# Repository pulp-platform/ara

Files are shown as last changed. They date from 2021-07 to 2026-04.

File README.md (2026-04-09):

# Ara



Ara is a vector unit working as a coprocessor for the CVA6 core.
It supports the RISC-V Vector Extension, [version 1.0](https://github.com/riscv/riscv-v-spec/releases/tag/v1.0), and the [Zvkned](https://github.com/riscv/riscv-crypto/releases/tag/v1.0.0) vector crypto extension for AES encryption/decryption.

Prototypical documentation can be found at https://pulp-platform.github.io/ara

## Dependencies

Check `DEPENDENCIES.md` for a list of hardware and software dependencies of Ara.

## Supported instructions

Check `FUNCTIONALITIES.md` to check which instructions are currently supported by Ara.

## Get started

Make sure you clone this repository recursively to get all the necessary submodules:

```bash
make git-submodules
```

If the repository path of any submodule changes, run the following command to change your submodule's pointer to the remote repository:

```bash
git submodule sync --recursive
```

## Toolchain

Ara requires a RISC-V LLVM toolchain capable of understanding the vector extension, version 1.0.

To build this toolchain, run the following command in the project's root directory.

```bash
# Build the LLVM toolchain
make toolchain-llvm
```

Ara also requires an updated Spike ISA simulator, with support for the vector extension.
There are linking issues with the standard libraries when using newer CC/CXX versions to compile Spike. Therefore, here we resort to older versions of the compilers. If there are problems with dynamic linking, use:
`make riscv-isa-sim LDFLAGS="-static-libstdc++"`. Spike was compiled successfully using gcc and g++ version 7.2.0.

To build Spike, run the following command in the project's root directory.

```bash
# Build Spike
make riscv-isa-sim
```

## Verilator

Ara requires an updated version of Verilator, for RTL simulations.

To build it, run the following command in the project's root directory.

```bash
# Build Verilator
make verilator
```

Alternatively, you can use a system-installed Verilator by passing `system_verilator=1` to the hardware make targets:

```bash
make -C hardware verilate system_verilator=1
```

### macOS

On macOS, install `libelf` via Homebrew (it is not shipped with macOS):

```bash
brew install libelf
```

The build system will automatically detect macOS and add the necessary Homebrew include/library paths.

## Configuration

Ara's parameters are centralized in the `config` folder, which provides several configurations to the vector machine.
Please check `config/README.md` for more details.

Prepend `config=chosen_ara_configuration` to your Makefile commands, or export the `ARA_CONFIGURATION` variable to choose a configuration other than the `default` one.

## Software

### Build Applications

The `apps` folder contains example applications that work on Ara. Run the following command to build an application. E.g., `hello_world`:

```bash
cd apps
make bin/hello_world
```

### SPIKE Simulation

All the applications can be simulated with SPIKE. Run the following command to build and run an application. E.g., `hello_world`:

```bash
cd apps
make bin/hello_world.spike
make spike-run-hello_world
```

### RISC-V Tests

The `apps` folder also contains the RISC-V tests repository, including a few unit tests for the vector instructions. Run the following command to build the unit tests:

```bash
cd apps
make riscv_tests
```

## RTL Simulation

### Hardware dependencies

The Ara repository depends on external IPs and uses Bender to handle the IP dependencies.
To install Bender and initialize all the hardware IPs, run the following commands:

```bash
# Go to the hardware folder
cd hardware
# Install Bender and checkout all the IPs
make checkout
```

If you have Bender installed system-wide, pass `system_bender=1` to use it instead of the local binary.

### Patches (only once!)

Note: this step is required only once, and needs to be repeated ONLY if the IP hardware dependencies are deleted and checked out again.

Some of the IPs need to be patched to work with Verilator.

```bash
# Go to the hardware folder
cd hardware
# Apply the patches (only need to run this once)
make apply-patches
```

### Simulation

To simulate the Ara system with ModelSim, go to the `hardware` folder, which contains all the SystemVerilog files. Use the following command to run your simulation:

```bash
# Go to the hardware folder
cd hardware
# Only compile the hardware without running the simulation.
make compile
# Run the simulation with the *hello_world* binary loaded
app=hello_world make sim
# Run the simulation with the *some_binary* binary. This allows specifying the full path to the binary
preload=/some_path/some_binary make sim
# Run the simulation without starting the gui
app=hello_world make simc
```

We also provide the `simv` makefile target to run simulations with the Verilator model.

```bash
# Go to the hardware folder
cd hardware
# Apply the patches (only need to run this once)
make apply-patches
# Only compile the hardware without running the simulation.
make verilate
# Run the simulation with the *hello_world* binary loaded
app=hello_world make simv
```

It is also possible to simulate the unit tests compiled in the `apps` folder. Given the number of unit tests, we use Verilator. Use the following command to install Verilator, verilate the design, and run the simulation:

```bash
# Go to the hardware folder
cd hardware
# Apply the patches (only need to run this once)
make apply-patches
# Verilate the design
make verilate
# Run the tests
make riscv_tests_simv
```

Alternatively, you can also use the `riscv_tests` target at Ara's top-level Makefile to both compile the RISC-V tests and run their simulation.

### Traces

Add `trace=1` to the `verilate`, `simv`, and `riscv_tests_simv` commands to generate waveform traces in the `fst` format.
You can use `gtkwave` to open such waveforms.

### Ideal Dispatcher mode

CVA6 can be replaced by an ideal FIFO that dispatches the vector instructions to Ara with the maximum issue-rate possible.
In this mode, only Ara and its memory system affect performance.
This mode has some limitations:
 - The dispatcher is a simple FIFO. Ara and the dispatcher cannot have complex interactions.
 - Therefore, the vector program should be fire-and-forget. There cannot be runtime dependencies from the vector to the scalar code.
 - Not all the vector instructions are supported, e.g., the ones that use the `rs2` register.

To compile a program and generate its vector trace:

```bash
cd apps
make bin/${program}.ideal
```

This command will generate the `ideal` binary to be loaded in the L2 memory for the simulation (data accessed by the vector code).
To run the system in Ideal Dispatcher mode:

```bash
cd hardware
make sim app=${program} ideal_dispatcher=1
```

### VCD Dumping

It's possible to dump VCD files for accurate activity-based power analyses. To do so, use the `vcd_dump=1` option to compile the program and to run the simulation:

```bash
make -C apps bin/${program} vcd_dump=1
make -C hardware simc app=${program} vcd_dump=1
```

Currently, the following kernels support automatic VCD dumping: `fmatmul`, `fconv3d`, `fft`, `dwt`, `exp`, `cos`, `log`, `dropout`, `jacobi2d`.

### Linting Flow

We also provide Synopsys Spyglass linting scripts in the hardware/spyglass. Run make lint in the hardware folder, with a specific MemPool configuration, to run the tests associated with the lint_rtl target.

### Support for `rvv-bench`

To run `rvv-bench` instructions benchmark, execute:

```bash
make rvv-bench
make -C apps bin/rvv
make -C hardware simv app=rvv
```

## FPGA implementation and Linux flow

Ara supports Cheshire's FPGA flow and can be currently implemented on VCU128 and VCU118 in bare-metal and with Linux. The tested configuration is with 2 lanes.

For information about the FPGA bare-metal and Linux flows, please refer to `cheshire/README.md`.

## Publications

If you want to use Ara, you can cite us:
```
@Article{Ara2020,
  author = {Matheus Cavalcante and Fabian Schuiki and Florian Zaruba and Michael Schaffner and Luca Benini},
  journal= {IEEE Transactions on Very Large Scale Integration (VLSI) Systems},
  title  = {Ara: A 1-GHz+ Scalable and Energy-Efficient RISC-V Vector Processor With Multiprecision Floating-Point Support in 22-nm FD-SOI},
  year   = {2020},
  volume = {28},
  number = {2},
  pages  = {530-543},
  doi    = {10.1109/TVLSI.2019.2950087}
}
```
```
@INPROCEEDINGS{9912071,
  author={Perotti, Matteo and Cavalcante, Matheus and Wistoff, Nils and Andri, Renzo and Cavigelli, Lukas and Benini, Luca},
  booktitle={2022 IEEE 33rd International Conference on Application-specific Systems, Architectures and Processors (ASAP)},
  title={A “New Ara” for Vector Computing: An Open Source Highly Efficient RISC-V V 1.0 Vector Processor Design},
  year={2022},
  volume={},
  number={},
  pages={43-51},
  doi={10.1109/ASAP54787.2022.00017}}
```
```
@ARTICLE{10500752,
  author={Perotti, Matteo and Cavalcante, Matheus and Andri, Renzo and Cavigelli, Lukas and Benini, Luca},
  journal={IEEE Transactions on Computers},
  title={Ara2: Exploring Single- and Multi-Core Vector Processing With an Efficient RVV 1.0 Compliant Open-Source Processor},
  year={2024},
  volume={73},
  number={7},
  pages={1822-1836},
  keywords={Vectors;Registers;Computer architecture;Vector processors;Multicore processing;Microarchitecture;Kernel;RISC-V;vector;ISA;RVV;processor;efficiency;multi-core},
  doi={10.1109/TC.2024.3388896}}
```

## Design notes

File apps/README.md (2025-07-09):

# Apps

This folder contains the benchmarks, programs, and tests ready to be run on Ara.

Run the following command to build an application. E.g., `hello_world`:

```bash
cd apps
make bin/hello_world
```

### Convolutions

Convolutions allow to specify the output matrix size and the size of the filter, with the variables `OUT_MTX_SIZE` up to 112 and `F_SIZE` within {3, 5, 7}. Currently, not all the configurations are supported for all the convolutions. For more information, check the `main.c` file for the convolution of interest.
Example:

```bash
cd apps
make bin/fconv2d OUT_MTX_SIZE=112 F_SIZE=7
```

### Linux programs

Compile $app for bare-metal:

```bash
make ${app}
```

Compile $app for OS:

```bash
make ${app}-linux LINUX=1
```

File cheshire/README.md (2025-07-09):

## Introduction

Ara can be synthesized on a VCU128 FPGA and boot Linux through the Cheshire SoC. This folder provides the necessary targets and flow to build RVV-Linux and deploy Ara on FPGA. To make them work, this repository should be deployed as a submodule of Cheshire.

Our entry point is to generate a custom `add_sources.vcu128.tcl` file with specific Ara targets, copy this file into the Cheshire directory, and then use the default Cheshire compile flow, which will use our provided TCL file

## How to Use

Ara should be instantiated as a submodule of Cheshire. This means that the Ara repo should be downloaded through `bender checkout` from the Cheshire directory. Then, Ara's path can be retrived using `bender path ara`.

```bash
git clone git@github.com:pulp-platform/cheshire.git
cd cheshire
git checkout ${COMMIT}
bender checkout
ARA_ROOT=$(bender path ara)
cd ${ARA_ROOT}
```

## FPGA and OS flow

### LINUX-RVV Kernels
Compile kernels to be run on the FPGA under Linux (this will also install the buildroot toolchain)

```bash
cd ${ARA_ROOT}/cheshire/sw

# Choose a kernel from the apps directory
kernel=fmatmul
make ${kernel}-linux
```

### Generate the Linux IMG
Generate the Linux image (containing all the RVV kernels previously built)

```bash
# Generate the Linux img
cd ${ARA_ROOT}/cheshire/sw
make linux-img

# Generate Cheshire's Linux img
cd ${ARA_ROOT}/cheshire
make ara-chs-image
```

### Generate the FPGA bitstream

```bash
cd ${ARA_ROOT}/cheshire
make ara-chs-xilinx
```

### Flash the Linux image on the SD card

```bash
cd ${ARA_ROOT}/cheshire
make ara-chs-xilinx-flash
```

### Program the bitstream

```bash
cd ${ARA_ROOT}/cheshire
make ara-chs-xilinx-program
```

For more information, see Cheshire's documentation (https://pulp-platform.github.io/cheshire/tg/xilinx).

### Example

Example script to boot Linux on a VCU128 FPGA board. Modify the variables as needed.

There should be an open Hardware Target for the VCU128 board. Moreover, a UART terminal is required.

Note: this script requires `bender`. Also, some Cheshire targets may require an up-to-date RISC-V compiler.

```bash
export CHS_ROOT=$(pwd)/cheshire

# Cheshire commit
# FILL ME
export CHS_HASH=

# Do we need a specific GCC/G++ version to build the buildroot GCC compiler?
HOST_TOOLCHAIN_SUFFIX=

# Which RVV kernels to run under Linux
export RVV_KERNELS="hello_world-linux fmatmul-linux fconv3d-linux jacobi2d-linux fdotproduct-linux"

# FPGA details
# FILL ME
export BOARD="vcu128"
export CHS_XILINX_HWS_URL=
export CHS_XILINX_HWS_PATH=

# Info
echo "Using the VCU128 ${CHS_XILINX_HWS_URL} ${CHS_XILINX_HWS_PATH}"
# Clone Cheshire
echo "Cloning Cheshire"
git clone git@github.com:pulp-platform/cheshire.git
cd ${CHS_ROOT}
git checkout ${CHS_HASH}
# Checkout Ara
echo 'Checkout hardware deps'
bender checkout
export ARA_ROOT=$(bender -d ${CHS_ROOT} path ara)
# Apply patches if needed
# The following is non-mandatory:
# Upsize Cheshire's memory and disable VGA
make -C ${ARA_ROOT}/cheshire patch_cheshire_high_perf_hw
# The following is non-mandatory
# Setup L2 as a cache and not as a scratchpad when running Linux
make -C ${ARA_ROOT}/cheshire/sw patch_cheshire_high_perf_sw
# Compile RVV kernels
echo 'Install the Linux compiler and compile the LINUX RVV kernels'
make -C ${ARA_ROOT}/cheshire/sw ${RVV_KERNELS} HOST_TOOLCHAIN_SUFFIX=${HOST_TOOLCHAIN_SUFFIX}
# Compile the Linux image
echo 'Compile the Linux image'
make -C ${ARA_ROOT}/cheshire/sw linux-img HOST_TOOLCHAIN_SUFFIX=${HOST_TOOLCHAIN_SUFFIX}
# Generate Cheshire's Linux image
echo 'Generate Cheshire Linux image'
make -C ${ARA_ROOT}/cheshire ara-chs-image BOARD=${BOARD}
# Generate the bitstream
echo 'Generate the bitstream'
make -C ${ARA_ROOT}/cheshire ara-chs-xilinx BOARD=${BOARD}
# Flash the SD with Linux
echo 'Flash the SD with Linux'
make -C ${ARA_ROOT}/cheshire ara-chs-xilinx-flash BOARD=${BOARD} CHS_XILINX_HWS_URL=${CHS_XILINX_HWS_URL} CHS_XILINX_HWS_PATH=${CHS_XILINX_HWS_PATH}
# Program the bitstream
echo 'Program the bitstream'
make -C ${ARA_ROOT}/cheshire ara-chs-xilinx-flash BOARD=${BOARD} CHS_XILINX_HWS_URL=${CHS_XILINX_HWS_URL} CHS_XILINX_HWS_PATH=${CHS_XILINX_HWS_PATH}
```

## Bare-metal flow

### Compile the bare-metal programs in `${ARA_ROOT}/cheshire/sw/src`

```bash
cd ${ARA_ROOT}/cheshire/sw
make chs-sw-all
```

### Patch Cheshire (optional)

Optionally, Cheshire can be patched to have a larger main memory, VGA disabled, and LLC configured as cache under Linux.
This provides better performance.

```bash
cd ${ARA_ROOT}/cheshire
make patch_cheshire_high_perf_hw
cd ${ARA_ROOT}/cheshire/sw
make patch_cheshire_high_perf_sw
```

### Generate the FPGA bitstream

```bash
cd ${ARA_ROOT}/cheshire
make ara-chs-xilinx
```

### Program the bitstream

Provided that an Hardware Target is available:

```bash
cd ${ARA_ROOT}/cheshire
make ara-chs-xilinx-program
```

### Run programs on the FPGA
The programs can now be injected in the FPGA via JTAG (OpenOCD + GDB).
For more information, see Cheshire's documentation (https://pulp-platform.github.io/cheshire/tg/xilinx).

## Back-Referencing Explained

Here's how we use back-referencing in our setup:

1.  **Generate Custom TCL File**:

    -   We generate a custom `add_sources.vcu128.tcl` file using the `bender script vivado` command with our specific targets (`-t fpga -t vcu128 -t cv64a6_imafdcv_sv39 -t cva6 --define ARA --define NR_LANES=$(nr_lanes) --define VLEN=$(vlen)`).
    -   This custom TCL file includes all the necessary sources and configurations required for the FPGA synthesis with Cheshire + Ara.

2.  **Copy Custom TCL File**:

    -   The generated custom TCL file is then copied into the Cheshire directory (`$(BACKREF_CHS_XIL_SCRIPTS)/add_sources.vcu128.tcl`).

3.  **Invoke Cheshire Compile Flow**:

    -   With the custom TCL file in place, we invoke the Cheshire compile flow by running `make -C $(BACKREF_CHS_ROOT) chs-xilinx-all`.
    -   The Cheshire compile flow target depends on the `add_sources.vcu128.tcl` file, and since we have provided our custom version, it will use ours for the synthesis process.

This method ensures that we can extend and customize the compile flow for our specific needs without modifying the Cheshire repository directly.

## Notes

### Variables
 - ARA_CONFIGURATION: thus far, only Ara with 2 lanes has been tested (ARA_CONFIGURATION=2_lanes).
 - HOST_TOOLCHAIN_SUFFIX: the host GCC and G++ should be sufficiently up to date to build the buildroot cross compiler. For environments that track the program version with suffixes, this variable helps choose the correct host compiler version. Use this variable only if needed when installing the buildroot toolchain.
 - BOARD: name of the board, e.g., `vcu128`.
 - CHS_XILINX_HWS_URL: URL of the FPGA, if connected to the net.
 - CHS_XILINX_HWS_PATH: physical PATH of the FPGA.

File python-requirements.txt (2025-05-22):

# Copyright 2021 ETH Zurich and University of Bologna.
# Solderpad Hardware License, Version 0.51, see LICENSE for details.
# SPDX-License-Identifier: SHL-0.51

dataclasses
gitpython
hjson
jsonref
jsonschema
tabulate
yamlfmt
numpy
matplotlib
scikit-learn

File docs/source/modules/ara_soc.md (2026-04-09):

# `ara_soc`: Top-Level Dummy SoC for Ara

## Overview

The `ara_soc` module is a top-level **dummy system-on-chip** used to instantiate the **Ara vector processor** alongside the scalar **CVA6 core**, enabling test and benchmarking in a standalone simulation environment.

This SoC includes:
- Ara + CVA6 integration
- L2 memory (a simple SRAM, called DRAM in the file for historical reasons)
- Dummy UART peripheral
- Control and status registers
- AXI crossbar interconnect and protocol adapters

It is **parameterizable** to support varying numbers of vector lanes and data widths, enabling scalable evaluation of Ara across configurations.

---

## Parameters

| Name | Description |
|---|---|
| `NrLanes` | Number of parallel vector lanes (2–16, power-of-two) |
| `VLEN` | Vector length in bits (usually `1024 × NrLanes`) |
| `OSSupport` | Enable OS-level support in CVA6 |
| `FPUSupport` | Enables FP16, FP32, FP64 support |
| `FPExtSupport` | Enable optional `vfrec7` / `vfrsqrt7` instructions |
| `FixPtSupport` | Enables fixed-point support |
| `SegSupport` | Enables segmented memory instructions |
| `CryptoSupport` | Enables vector crypto extensions (e.g., `CryptoSupportAES` for Zvkned) |
| `Axi*Width` | AXI bus widths for data, address, ID, user |
| `AxiRespDelay` | AXI response delay in picoseconds (used in gate-level simulations) |
| `L2NumWords` | Number of words in simulated SRAM (`4MiB / lane` default) |

---

## Memory Map

| Region | Base Address | Size |
|---|---|---|
| `SRAM` | `0x8000_0000` | 1 GB |
| `UART` | `0xC000_0000` | 4 KB |
| `CTRL` | `0xD000_0000` | 4 KB |

---

## Internal Structure

### AXI Crossbar
- One master (CVA6+Ara system)
- Three slaves: SRAM, UART, control registers
- Managed via `axi_xbar` with routing rules

### SRAM (L2 Memory)
- Backed by non-synthesizable SRAM (`tc_sram`)
- Connected via `axi_to_mem` and `axi_atop_filter` (atomics filtered out)

### Dummy UART
- APB interface exposed to the environment
- Internally connected via AXI-Lite and AXI width converter
- Used to implement printf's putc in during simulation

### Control Registers
- Control and status block (exit signal, counters, etc.)
- Connected via AXI-Lite

### CVA6 + Ara Integration
- Instantiated via `ara_system`
- Custom configuration generated dynamically from RVV template config

---

## Interfaces

### Inputs
- `clk_i`, `rst_ni`: Clock and active-low reset
- `scan_enable_i`, `scan_data_i`: Scan chain inputs (for DFT)
- `uart_prdata_i`, `uart_pready_i`, `uart_pslverr_i`: UART bus inputs

### Outputs
- `exit_o`: Simulation termination flag, sensed by the testbench to end the simulation.
- `hw_cnt_en_o`: Hardware counter enable signal. Used for benchmarking.
- `scan_data_o`: Scan chain output.
- `uart_*`: APB UART outputs.

---

## Configuration Notes

CVA6 is configured dynamically using:

```systemverilog
function automatic config_pkg::cva6_user_cfg_t gen_usr_cva6_config(...);
```

## Memory

CVA6 + Ara access the memory through AXI using a `32 * #Lanes`-bit wide data port. This wide data port avoids complex interconnects and banked memory management, but performs poorly with indexed memory operations.

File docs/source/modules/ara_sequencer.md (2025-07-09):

# `ara_sequencer` — Instruction sequencer and macro dependency check

Overview
--------
The `ara_sequencer` is a central control module in Ara's vector processor that manages instruction dispatching and execution synchronization across its parallel processing elements (PEs). It ensures correct ordering and dependency resolution for vector instructions, tracks the state of each instruction in-flight, and handles hazards and stalling due to resource constraints.

Key Features
------------
- Tracks running vector instructions and their mapping to PEs
- Maintains a global hazard table for dependency management
- Calculates start and end lanes for operand access
- Arbitrates instruction issuance based on operand readiness and structural hazards
- Interfaces with CVA6 via a tokenized valid/ready protocol
- Handles load/store sequencing and exception propagation
- Supports masked vector operations and precise scalar forwarding

Interface Description
---------------------
### Inputs
- `clk_i`, `rst_ni`: Standard clock/reset
- `ara_req_i`, `ara_req_valid_i`: Instruction request from dispatcher
- `pe_req_ready_i`, `pe_resp_i`: PE readiness and response signals
- `alu_vinsn_done_i`, `mfpu_vinsn_done_i`: Completion signals from specific FU types
- `addrgen_ack_i`, `addrgen_exception_i`, `addrgen_exception_vstart_i`, `addrgen_fof_exception_i`: Address generator and exception interfaces
- `pe_scalar_resp_i`, `pe_scalar_resp_valid_i`: Scalar value return for scalar-result instructions

### Outputs
- `ara_req_ready_o`, `ara_resp_o`, `ara_resp_valid_o`: Request response handshake
- `pe_req_o`, `pe_req_valid_o`: Instruction issued to PEs
- `global_hazard_table_o`: Dependency matrix broadcast to operand requesters
- `ara_idle_o`: High when no instruction is in-flight
- `pe_scalar_resp_ready_o`: Ready signal for scalar result

Main Components
---------------
### Instruction State Tracking
- `pe_vinsn_running_q`: Bitmap showing which PE is executing which instruction
- `vinsn_running_q`: Aggregated bitmap indicating if any instruction is live. This signal is extremely useful for debug
- `vinsn_id_n`: Allocated ID for the next instruction using LZC

### Hazard Management
- RAW, WAR, WAW hazards computed against `read_list_q` and `write_list_q`
- `global_hazard_table_o` updated with current hazard vectors
- Enforces correct serialization and prevents premature execution

### Start/End Lane Calculation
- Derives which lanes will produce the first and last valid elements
- Based on `vstart`, `vl`, and `vsew`
- Important for operand alignment and masking

### Issuance Arbitration
- FSM with `IDLE` and `WAIT` states
- Uses counters per VFU to throttle instruction dispatch
- "Gold ticket" system ensures stalled-but-accounted instructions are not blocked

### Functional Unit Interface
- Identifies target VFU for each instruction
- Uses `target_vfus()` function to map to ALU, MFPU, SLDU, MASKU, etc.
- Only issues when operand requesters and FU queues are ready

### Special Features
- Slide unit constraints handled to avoid chaining issues
- Handles scalar results with mask unit coordination
- Exception signaling for burst and address-related faults
- Provides synchronization to CVA6 (via token and response logic)

Instruction Flow
----------------
1. Dispatcher issues instruction to sequencer.
2. Sequencer:
   - Allocates ID
   - Checks for hazards
   - Builds request (`pe_req_d`)
   - Calculates start/end lanes
   - Evaluates VFU counters
3. If resources available:
   - Issues request
   - Updates global hazard table and instruction trackers
4. Enters `WAIT` if instruction needs scalar return or memory ack
5. Once response is received or exception detected, returns to `IDLE`.

FSM States
----------
- **IDLE**: Default state; waits for instruction or handles stalls from the lanes' operand requesters.
- **WAIT**: Holding state for memory/scalar responses.

Dependency tracking and chaining
----------
Dependencies are tracked per instruction, so that chaining can be implemented at vector-element level.

The sequencer only knows which instruction depends on which other instruction, and assign special "hazard" signals to each instruction before issuing it to the units.
Every instruction keeps hazard metadata per operand register, so that it is clear upon which instruction every operand register depends.

Chaining is implemented in each lane, during operand fetch.
Every dependency (RAW, WAR, WAW) on a specific register will throttle the source operand fetch from the VRF. This throttling is controlled by the write throughput of the instruction that generated the dependency.

RAW example:
```
vld v0, addr
vadd v1, v0, v0
```

When executing the `vadd` (`vld` is executing in parallel), a lane will fetch the next element from `v0` only if `vld` has written one element first. This control is a credit-based system with a depth of one element only. Therefore, if `vld` writes 5 elements, the `vadd` only registers one credit for a read.

WAR and WAW hazards are handled in the same way.

WAR example:
```
vmul v2, v1, v1
vadd v1, v0, v0
```

Also in this case, `vadd` will be able to fetch from `v0` only when `vmul` has written into `v2`. This works because if source operands are chained, destination operands are also correctly ordered.

As soon as one instruction that causes a dependency is completes execution, the scoreboard is cleared and the second instruction will be allowed to fetch operands without restrictions.

This works as long as:
 - The second instruction has source operands from the VRF. For example, WAR and WAW stall loads, which would not be able to chain with this mechanism.
 - The first instruction actually writes something into the VRF. Therefore, WAR on store instructions stalls the second instruction until the first one has not completed.

Instruction Issue
----------
The sequencer keeps an instruction counter per functional unit to track how many instructions are in-flight and stall instruction issue whenever the next target functional unit's instruction queue is already full.

A new instruction bumps up the respective counter, and a completed instruction bumps it down.

Since, for timing reasons, instructions flow into the sequencer and bump the respective counter without waiting to be issues, counters can also go beyond their maximum capacity for one cycle. This event is registered through a gold ticket assigned to the instruction, which basically implies that the instruction was already registered by the respective counter. As soon as the counter returns to its maximum capacity (this happens when an instruction is finishes execution in the respective unit), the gold ticket allows the stalled instruction to proceed.

Physical Considerations
-----------------------
- `vinsn_queue_ready`: Derived from counter depth per FU
- `stall_lanes_desynch`: Ensures lane-0 aligned counters for ALU/MFPU
- `global_hazard_table_d`: Matrix [NrVInsn][NrVInsn] with sparse update logic
- Careful pipeline management to support exception-aware issuing

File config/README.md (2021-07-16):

# Configuration file for Ara

This file is included by all *Makefiles* in the Ara project to have a common
source for all configurations. Please only edit this file to change some
parameters such as the number of lanes in the design. This will automatically
generate the correct software runtime and the correct hardware.

Ara currently has four configurations, which differ on the amount of lanes:
- `2_lanes.mk`
- `4_lanes.mk`
- `8_lanes.mk`
- `16_lanes.mk`
We also provide a `default.mk` configuration, which links to the `4_lanes` one.

When running Ara's Makefiles, prepend `config=configuration_without_mk` to choose
a configuration. Alternatively, export the `ARA_CONFIG` variable. Please note that
the configuration chosen via the `config=` command line has priority over the
configuration set globally through the `ARA_CONFIG` variable.

If no configuration is explicitly chosen, Ara will use the `default` one. Please run
`make clean` after changing configurations.

To avoid constantly having a dirty git environment when working with a
configuration that differs from the default one, you can ignore changes to the
configuration file with the following command:

```bash
git update-index --assume-unchanged config/default.mk
```

In case you want to change the default and commit your changes to `default.mk`,
you can use the following command to make git pick up tracking the file again:

```bash
git update-index --no-assume-unchanged config/default.mk
```

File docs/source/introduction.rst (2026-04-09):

Introduction
=============

This Section will Introduce you the Ara Vector Processor.

Introduction to Ara
-------------------

Ara is a **modular, open-source vector processing unit** designed to **augment RISC-V processors** with **high-performance, energy-efficient vector computation**. It is developed by the `PULP platform <https://pulp-platform.org/>`_ at ETH Zurich and the University of Bologna.

At its core, **Ara is a scalable vector accelerator** compliant with the `RISC-V Vector Extension 1.0 (RVV) <https://github.com/riscv/riscv-v-spec>`_. It is specifically designed to target **data-parallel workloads** in embedded and high-performance computing environments. Ara is built to plug into the `CVA6 RISC-V core <https://github.com/openhwgroup/cva6>`_, and is suitable for system-on-chip (SoC) designs that require vector processing capabilities for applications such as:

- Signal processing
- Linear algebra
- Machine learning kernels
- Computer vision
- Cryptographic acceleration (currently AES via the Zvkned extension)

Ara can be configured with a power-of-2 number of parallel vector lanes ranging from 2 to 16. Each lane contains a slice of the Vector Register File (VRF), a SIMD FPU, and a SIMD ALU/Multiplier.

Since Multiply-and-Accumulate instructions can be executed in one cycle by each FPU, the maximum performance of Ara is `2 * #Lanes` 64-bit packets/cycle, where each 64-bit packet can contain from one 64-bit element to eight 8-bit elements, processed in SIMD fashion.

Architectural Overview
----------------------

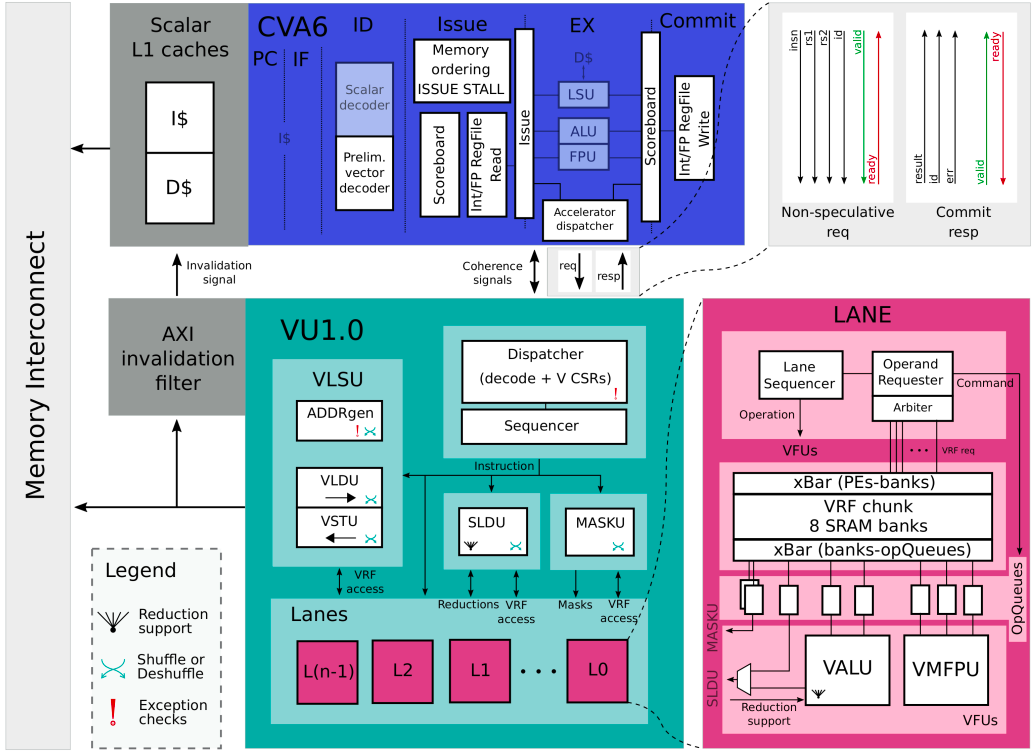
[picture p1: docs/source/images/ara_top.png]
Ara Top level Image


   Ara's top level diagram

Ara is composed of the following major components:

- **Vector Functional Units (VFUs)**: Includes ALUs, FPUs, multipliers, mask units, and slide units, each operating across multiple lanes in parallel.
- **Vector Lanes**: The architecture is scalable to multiple lanes. Each lane processes one slice of the data, providing parallelism at the element level.
- **Dispatcher & Sequencer**: These components decode and schedule vector instructions, ensuring synchronization and legal execution patterns.
- **Register File (VRF)**: Ara contains a large vector register file, partitioned across lanes for bandwidth scalability.
- **Memory Interface**: Vector loads and stores are issued via AXI-compatible memory accesses, either from DRAM or TCDM (depending on system integration).

Ara is **modular by construction**: users can configure the number of lanes, supported datatypes (int/fixed/fp), and optional features like floating-point extensions, reductions, or vector crypto.

Target Use Cases
----------------

Ara is ideal for:

- **Academic research** into vector architectures and compilers
- **Hardware/software co-design**
- **Custom accelerators** in SoC designs
- **FPGA-based prototyping** of RVV software

Ara for Non-Experts
-------------------

What Is Ara?
~~~~~~~~~~~~

Think of Ara as a **muscle boost for a processor**, specialized in handling **repetitive data-heavy tasks**—like multiplying a thousand numbers in parallel or transforming images efficiently.

Instead of performing one operation at a time, Ara handles **many operations at once** using **vectors** (think: long lists of numbers). This is similar to how modern GPUs work for games and machine learning—but in a way that is more **tailored to embedded systems** and open-source hardware.

Why Is Ara Useful?
~~~~~~~~~~~~~~~~~~

Most general-purpose CPUs process one or two pieces of data per cycle. Ara can process **dozens or hundreds of values in parallel**. This makes it **much faster and more energy-efficient** when dealing with structured, repetitive workloads like:

- Filtering an audio signal
- Applying a blur effect on an image
- Computing dot products in a neural network layer

Ara plugs into a RISC-V core like an add-on, offloading these "bulk" computations.

.. toctree::
   :maxdepth: 2
   :caption: Contents:

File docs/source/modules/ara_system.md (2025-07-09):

# `ara_system`: Integration of CVA6 and Ara

## Overview

`ara_system` instantiates and connects the scalar core **CVA6** with the **Ara vector accelerator**. It builds the system-level interface between the two, handles AXI width conversion, invalidation signaling, and merges AXI traffic into a unified master port.

This module is the core of Ara's architectural integration, enabling:
- Vector instruction dispatch from CVA6 to Ara
- Shared AXI access arbitration
- Coherent invalidation handling for vector memory stores
- Flexible benchmarking configurations through parameterization

CVA6 is a RV64GC RISC-V Linux-ready core. It features one L1 instruction cache and one L1 data cache connecting to the L2 memory.

CVA6 is the only "RISC-V core" properly speaking, meaning that it is the only one accessing the program's instruction flow.

Ara is a tighlty-coupled accelerator plugged into CVA6, and receives vector instructions from CVA6.

Both Ara and CVA6 have a private AXI4-compliant Load-Store unit. Ara's one directly connects to the L2 memory, bypassing CVA6's L1 data cache.

This allows for potential coherence and memory operation ordering issues.

---

## Memory Coherence and Consistency

Memory coherence is enforced through three main mechanisms:
 - Memory writes are serialized through a single memory bus.
 - CVA6 L1-D$ is write-through.
 - An invalidation filter snoops on Ara's AXI AW memory bus and invalidates the potentially-stale sets in CVA6's L1-D$.

Memory ordering is enforced by CVA6 and control signals between CVA6 and Ara. No memory operations are issued or started until it's safe to do so.
For example, pending vector stores prevent CVA6 from issuing scalar memory operations, and vector memory operations are not dispatched to Ara if there is a pending scalar store.

---

## Virtual memory support

Ara uses CVA6's MMU to translate virtual addresses into physical ones. This is done through the MMU interface.

---

## Parameters

### Ara + RVV Parameters

| Name | Description |
|---|---|
| `NrLanes` | Number of vector lanes |
| `VLEN` | Vector register length (in bits) |
| `OSSupport` | Enables OS features |
| `FPUSupport`  | Enabled FP precisions |
| `FPExtSupport`| Support for `vfrec7`, `vfrsqrt7` |
| `FixPtSupport`| Enable fixed-point ops |
| `SegSupport`  | Support for segmented memory ops |

### CVA6 and AXI Interface

| Name | Description |
|---|---|
| `CVA6Cfg` | CVA6 configuration record |
| `exception_t` | CVA6 exception type |
| `accelerator_req_t` | Accelerator interface (CVA6 → Ara) |
| `accelerator_resp_t`| Accelerator interface (Ara → CVA6) |
| `acc_mmu_{req,resp}`| MMU interface |
| `cva6_to_acc_t` | Packed request interface |
| `acc_to_cva6_t` | Packed response interface |
| `Axi*Width` | AXI bus widths |
| AXI typedefs | All channel and request/response types |

---

## Ports

| Port | Direction | Description |
|---|---|---|
| `clk_i` | Input | Clock signal |
| `rst_ni` | Input | Active-low reset |
| `boot_addr_i`| Input | Initial fetch address for CVA6 |
| `hart_id_i`  | Input | Hardware thread ID |
| `scan_*` | In/Out | Scan chain (test) |
| `axi_req_o`  | Output | AXI master request (merged) |
| `axi_resp_i` | Input | AXI master response (merged) |

---

## Internal Blocks

### 1. **CVA6 Core**
- Scalar processor core
- Interfaces to Ara via a dedicated accelerator port
- Outputs standard AXI (`ariane_axi_req_t`) at narrow data width to L2 memory

### 2. **Ara Accelerator**
- Fully parameterized vector unit
- Receives CVA6 requests, returns results and exceptions
- AXI master interface at wide data width (`32 * #Lanes` data width)

### 3. **AXI Width Converter**
- `axi_dw_converter` adjusts CVA6's narrow AXI (e.g., 64-bit) to match Ara/system-wide bus width

### 4. **AXI Invalidation Filter**
- Detects vector memory stores and emits invalidation signals
- Ensures cache coherence with CVA6
- Integrated with Ara's AXI path

### 5. **AXI Multiplexer**
- Merges CVA6 and Ara AXI requests
- Handles arbitration, backpressure, and spill registers

---

## Vector Interface Handling

- The `acc_to_cva6_t` signal is extended to include `inval_valid` and `inval_addr`, enabling memory coherence notification from Ara back to CVA6.
- Ara can assert `inval_valid` when performing stores that require CVA6 cache line invalidation.
- `acc_cons_en` gate controls the invalidation path.

---

## Alternative Configuration: `IDEAL_DISPATCHER`

The ideal dispatcher is just a tool to benchmark Ara's performance with an ideal vector instruction dispatcher instantiated INSTEAD OF CVA6.

If `IDEAL_DISPATCHER` is defined:
- CVA6 is replaced with a perfect dispatcher (`accel_dispatcher_ideal`), i.e., a FIFO containing the dynamic instruction trace of the program plus the correct register file values
- Useful for functional validation/benchmarking or micro-benchmarking Ara in isolation

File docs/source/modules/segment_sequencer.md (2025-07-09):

# `segment_sequencer` - Split segment memory operations into multiple micro-ops

This module breaks down segment memory operations into a sequence of scalar memory operations. While this results in poor instruction-per-cycle (IPC) performance, it simplifies hardware implementation and avoids the need for tightly coupled multi-element memory accesses.

## Key Parameters

- `SegSupport`: Enables or disables segment memory support (`1'b1` enables it).
- `ara_req_t`, `ara_resp_t`: Types representing Ara's request and response protocols.

## Interface Signals

### Clock & Reset
- `clk_i`: Clock signal.
- `rst_ni`: Active-low reset.

### Control Inputs
- `ara_idle_i`: Indicates Ara is idle.
- `is_segment_mem_op_i`: Indicates the instruction is a segment memory op.
- `illegal_insn_i`: Signals if the instruction is illegal.
- `is_vload_i`: Identifies if the operation is a vector load.

### Operation Tracking
- `seg_mem_op_end_o`: Signals the end of a segment memory op.
- `load_complete_i/o`, `store_complete_i/o`: Track completion of memory operations.

### Ara Frontend-Backend Interface
- `ara_req_i/o`, `ara_req_valid_i/o`, `ara_req_ready_i`
- `ara_resp_i/o`, `ara_resp_valid_i/o`

## Functionality

When `SegSupport` is enabled, this module implements a small FSM to micro-sequence a segment operation into a series of scalar instructions. These instructions are prepared by adjusting `vs1`, `vd`, and `scalar_op` fields, and issuing one sub-operation at a time.

### FSM States

- `IDLE`: Wait for segment memory op. Sample `nf` and `is_vload_i`.
- `SEGMENT_MICRO_OPS`: Sequentially issue micro-operations for each field of the segment.
- `SEGMENT_MICRO_OPS_WAIT_END`: Wait for Ara backend to become idle.
- `SEGMENT_MICRO_OPS_END`: Forward the final response and signal completion.

### Micro-operation Construction

- For each segment element:
  - `vl` is set to 1
  - `vstart` tracks the segment index
  - `vs1`, `vd`, and `scalar_op` are offset by the segment field index (`segment_cnt_q`)
- For unit-stride segments (`VLE`, `VSE`): `op` is changed to `VLSE`, `VSSE` and a `stride` is computed.

### Control Logic

- Two counters are used:
  - `segment_cnt_q` tracks the number of fields processed
  - `vstart_cnt_q` increments for each segment
- Response (`ara_resp_q`) is delayed until the full operation finishes and Ara is idle.

## Disabled Mode (SegSupport == 0)

In this case, the module becomes a passthrough between Ara's frontend and backend, with no internal FSM or micro-operation handling.

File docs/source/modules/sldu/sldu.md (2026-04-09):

# `sldu` — Ara's slide unit, for permutations, shuffles, and slides

## Overview

The Slide Unit (`sldu`) in Ara's vector processor is responsible for implementing vector slide instructions as specified in the RISC-V Vector Extension (RVV). These instructions shift elements within vector registers, either left or right, potentially with a configurable stride, and can support varying effective element widths (EEWs). The design is modular and consists of three components:

- `sldu`: The top-level Slide Unit module
- `sldu_op_dp`: The datapath handling element reshuffling and shifting
- `p2_stride_gen`: A utility module that generates power-of-two strides

This unit supports seamless data flow between the operand lanes and result queues, handling valid/ready handshakes and internal reshuffling, aligning with the RVV specification.

---

## 1. `sldu`: Top-Level Slide Unit

### Purpose

The `sldu` module serves as the interface and coordinator for the entire slide operation. It connects the operand input/output ports, manages the slide operation control logic, and integrates the datapath (`sldu_op_dp`) and the stride generator (`p2_stride_gen`).

### Key Interfaces

- **Clock and Reset**
  - `clk_i`, `rst_ni`: Standard synchronous design signals.

- **Operands**
  - `sldu_operand_i [NrLanes-1:0]`: Operand vector from the lanes.
  - `sldu_operand_valid_i`, `sldu_operand_ready_o`: Valid/ready handshake.
  - `sldu_result_o`, `sldu_result_valid_o`, `sldu_result_ready_i`: Slide result vector and handshake signals.

- **Control**
  - `vinsn_issue_i`: Vector instruction information (EEW, SEW, etc.).
  - `stride_valid_i`, `stride_update_i`: Control inputs for stride progression.
  - `stride_i`: Incoming stride value.

- **Utility**
  - `stride_valid_o`: Asserted if the stride value is a power of two.
  - `popcount_o`: Output of 1-bit population count on stride vector.

### Functionality

- Integrates:
  - **Datapath (`sldu_op_dp`)** for reshuffling and sliding
  - **Stride Generator (`p2_stride_gen`)** for power-of-two stride sequence generation

- Responds to stride updates and dynamically loads new strides.

The slide unit's datapath can only handle power-of-two strides. Every non-power-of-two stride is broken down into power-of-two strides. This ensures a lightweight interconnect datapath in the slide unit while accelerating the common case. Non-power-of-2 slides are extremely rare.

The slide unit can also reshuffle, i.e., perform a slide-by-zero with different input and output data widths. This is used to change the byte layout of a vector register file.

---

## 2. `sldu_op_dp`: Slide Operand Datapath

### Purpose

This module implements the actual sliding logic of the operands, depending on:
- Source and destination EEW (`eew_src_i`, `eew_dst_i`)
- Direction (`dir_i`)
- Slide amount (`slamt_i`)

It operates with flattened vectors (`op_i_flat`, `op_o_flat`) for simplified internal manipulation.

### Operation

- Uses a large `unique case` block over `{eew_src_i, eew_dst_i, slamt_i, dir_i}` to pattern-match operations.
- For each case, byte-wise manipulation (via `+: 8` slices) rearranges bytes between source and destination.
- The result is assigned back to the `op_o_flat` register, which is then returned to the module interface.

### Notable Features

- Handles conversions across EEWs (e.g., EW8 → EW16)
- To have a simpler datapath, it cannot slide and reshuffle in the same cycle

---

## 3. `p2_stride_gen`: Power-of-Two Stride Generator

### Purpose

This utility module generates stride vectors where exactly one bit is high (i.e., a power-of-two stride), and can sequentially generate the next stride on `update_i`.

### Interfaces

- **Input**
  - `stride_i`: A stride vector to load.
  - `valid_i`: Load enable.
  - `update_i`: Trigger to generate the next stride.

- **Output**
  - `stride_p2_o`: Power-of-two stride vector
  - `valid_o`: Indicates if a valid (non-zero) stride is present
  - `popc_o`: Population count of stride bits

### Functionality

- Uses:
  - **`popcount` module** to count active bits in `stride_i`
  - **`lzc` module** to detect the first active bit
- Computes the next stride by XORing the current with the last stride
- Asserts `valid_o` if the stride is valid

---

## Signal Behavior Across Modules

- `vinsn_issue_i` is propagated across modules to control EEW behaviors and operand reshuffling.
- `sldu_op_dp` interprets the sliding direction (`dir_i`) and index (`slamt_i`) to select the output permutation.
- `stride_p2_o` controls which element is selected during a stride-slide.
- All data vectors (`op_i`, `op_o`) are organized as `elen_t [NrLanes-1:0]`, allowing lane-based parallel operation.

---

## Zvkned AES Support

When `Zvkned(CryptoSupport)` is enabled, the SLDU serves as the cross-lane permutation engine for AES instructions. It performs **Phase 2** of the 3-phase ALU-SLDU-ALU pipeline used by AES round and key schedule instructions.

### Role in the AES Pipeline

The SLDU receives intermediate results from the VALU (after SubBytes), performs a cross-column permutation, and returns the result to the VALU (for MixColumns + AddRoundKey). This reuses the existing SLDU datapath and avoids dedicated AES shuffle hardware.

### AES ShiftRows / InvShiftRows

For AES round instructions, the SLDU performs the ShiftRows (encrypt) or InvShiftRows (decrypt) byte permutation across the 4 columns of each 128-bit AES element group.

Each 32-bit AES column is laid out as `[7:0]=row0, [15:8]=row1, [23:16]=row2, [31:24]=row3`. The permutation operates per-element-group (4 columns), selecting source bytes from neighboring columns:

**ShiftRows** (for `vaesem`, `vaesef`):
- Row 0: stays in place
- Row 1: sourced from column `(c+1) % 4`
- Row 2: sourced from column `(c+2) % 4`
- Row 3: sourced from column `(c+3) % 4`

**InvShiftRows** (for `vaesdm`, `vaesdf`):
- Row 0: stays in place
- Row 1: sourced from column `(c+3) % 4`
- Row 2: sourced from column `(c+2) % 4`
- Row 3: sourced from column `(c+1) % 4`

The permutation is computed combinationally using column indices derived from `NrLanes` and `AesColsPerLane` (= DataWidth / 32).

### AES Key Schedule Prefix-XOR

For key schedule instructions (`vaeskf1`, `vaeskf2`), the SLDU performs a prefix-XOR chain across the 4 columns of each element group:

```
Input from VALU Phase 0:  [w0, w1, w2, temp]
  where temp = SubWord(RotWord(w3)) ^ Rcon

XOR chain:
  nw0 = w0 ^ temp
  nw1 = w1 ^ nw0
  nw2 = w2 ^ nw1

Output to VALU Phase 1:   [nw0, nw1, nw2, nw2]
```

The `nw2` value is placed in both column 2 and column 3 positions, so that the VALU can compute `nw3 = old_w3 ^ nw2` in Phase 3.

### Active Lane Masking

When `VL` is smaller than one full beat (fewer than `2 * NrLanes` columns), the SLDU computes an active lane mask to avoid marking inactive lanes as valid — which would cause a deadlock since no VALU would be waiting to grant on those lanes.

### Parameterization

Key AES parameters in the SLDU:
- `AesColsPerLane = DataWidth / 32` — AES columns per 64-bit lane (typically 2)
- `AesColsPerGroup = 4` — columns per 128-bit AES element group
- `AesGroupsPerBeat = (NrLanes * AesColsPerLane) / AesColsPerGroup` — element groups processed per beat

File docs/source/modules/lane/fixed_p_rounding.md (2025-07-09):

# `fixed_p_rounding` - Set up fixed-point arithmetic rounding information

## Overview

The `fixed_p_rounding` module implements fixed-point rounding logic for Ara's vector execution stage. It operates on 64-bit wide elements and generates rounding result bits for each element stream based on the rounding mode and vector element width (VEW).

---

## Ports

### Inputs

| Name | Type | Description |
|---|---|---|
| `operand_a_i` | `elen_t` | Encodes the shift amount `j` for each sub-element. |
| `operand_b_i` | `elen_t` | Source operand to extract rounding bits from. |
| `valid_i` | `logic` | Enables rounding logic when high. |
| `op_i` | `ara_op_e` | Operation type; rounding occurs only on selected operations. |
| `vew_i` | `vew_e` | Specifies the vector element width: `EW8`, `EW16`, `EW32`, or `EW64`. |
| `vxrm_i` | `vxrm_t` | RISC-V vector rounding mode: `00`, `01`, `10`, or `11`. |

### Output

| Name | Type | Description |
|---|---|---|
| `r_o` | `strb_t` | Output rounding bits for each element. |

---

## Internal Structures

### `rounding_args`
A `union packed` type that allows simultaneous interpretation of a 64-bit value as:
- 8 x 8-bit (`w8`)
- 4 x 16-bit (`w16`)
- 2 x 32-bit (`w32`)
- 1 x 64-bit (`w64`)

---

## Functional Behavior

Rounding logic is triggered only when `valid_i` is high and `op_i` matches one of:
- `VSSRA`
- `VSSRL`
- `VNCLIP`
- `VNCLIPU`

Depending on `vew_i` and `vxrm_i`, different rounding strategies are selected.

### Rounding Modes (`vxrm_i`)
- `00` (RNU): Round to Nearest, Up.
- `01` (RNE): Round to Nearest, ties to Even.
- `10` (RTZ): Round Towards Zero (no rounding).
- `11` (ROD): Round towards -∞ for negative and +∞ for positive.

### Element Width Handling

Each `vew_i` type (`EW8`, `EW16`, etc.) leads to different slicing of input operands.

#### Example for `EW8`, `vxrm = 00`:
```verilog
for (int i = 0; i < 8; i++) begin
  j      = opa.w8[i];
  r_o[i] = opb.w8[i][j-1];
end
```

#### Example for `EW32`, `vxrm = 01`:
```verilog
for (int i = 0; i < 2; i++) begin
  j      = opa.w32[i];
  r_o[i] = opb.w32[i][j-1] & opb.w32[i][j];
end
```

#### For `vxrm = 10`, no rounding is performed:
```verilog
r_o = '0;
```

#### For `vxrm = 11` (ROD), more logic is applied:
- Negates the `j`th bit
- ORs the masked remaining bits using a lookup from `bit_select`

---

## Lookup Table: `bit_select`

This is a constant table used to mask and check lower bits for rounding:
```verilog
bit_select = {
  64'h0000000000000000,
  64'h0000000000000001,
  64'h0000000000000003,
  ...
  64'h7FFFFFFFFFFFFFFF
};
```

Each index `j` selects `bit_select[j]` to help evaluate whether remaining bits are non-zero.

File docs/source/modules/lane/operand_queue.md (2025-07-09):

# `operand_queue` — Buffer between the VRF and the functional units

**Module Path**: `operand_queue.sv`
**Description**:
This module implements a configurable operand queue used to buffer and manipulate elements from the Vector Register File (VRF) before they are consumed by Functional Units (FUs). It includes support for type conversion, data widening, floating-point normalization, and reduction operations. It is a key part of Ara’s vector execution pipeline.

---

## Table of Contents
1. [Interface Overview](#interface-overview)
2. [Parameterization](#parameterization)
3. [Command FIFO](#command-fifo)
4. [Data Buffer (Input FIFO)](#data-buffer-input-fifo)
5. [Credit-Based Flow Control](#credit-based-flow-control)
6. [Floating-Point Leading Zero Count](#floating-point-leading-zero-count)
7. [Type Conversion Logic](#type-conversion-logic)
8. [Neutral Value Padding for Reductions](#neutral-value-padding-for-reductions)
9. [Operand Output Control](#operand-output-control)
10. [State Management](#state-management)
11. [Conclusion](#conclusion)

---

## Interface Overview

### Inputs:
- `clk_i`, `rst_ni`: Clock and active-low reset.
- `flush_i`: Flushes internal state (used during exception recovery or pipeline flush).
- `lane_id_i`: Identifier for the lane this operand queue belongs to.
- `operand_queue_cmd_i`, `operand_queue_cmd_valid_i`: Command inputs that define the behavior for each operand.
- `operand_i`, `operand_valid_i`: Operand data from the VRF.
- `operand_issued_i`: Tracks how many operands were issued.
- `operand_ready_i`: One-hot vector indicating readiness of connected FU ports.

### Outputs:
- `cmd_pop_o`: Optional indication that command has been popped (only if `AccessCmdPop` is enabled).
- `operand_queue_ready_o`: Signals readiness to accept new operands.
- `operand_o`, `operand_valid_o`, `operand_target_fu_o`: Operand data sent to FU, with valid and target signals.

---

## Parameterization

- `CmdBufDepth`, `DataBufDepth`: FIFO depths for commands and data.
- `FPUSupport`: Enum to control which FP formats (Half, Single, Double) are supported.
- `SupportIntExt[2|4|8]`: Enable widening integer operations.
- `SupportReduct`, `SupportNtrVal`: Support for reductions and neutral padding.
- `AccessCmdPop`: Enables external visibility into command buffer pops.

---

## Command FIFO

The command buffer stores upcoming operand operations as defined by the scheduler. These determine how operands are transformed. The `fifo_v3` module ensures in-order delivery and tracks usage internally. Commands are consumed only when enough operands are emitted.

---

## Data Buffer (Input FIFO)

An operand input FIFO buffers incoming VRF values until they are needed. Each cycle, values may be pushed (if valid) and popped (when used). Internally, a credit-based system ensures no overflows and supports simultaneous push/pop.

---

## Credit-Based Flow Control

The signal `operand_queue_ready_o` is driven by comparing current FIFO usage (`ibuf_usage_q`) with capacity. The usage counter is updated based on:
- Operand issued → increment
- Operand consumed → decrement

Flush logic resets the usage tracker.

---

## Floating-Point Leading Zero Count

The module optionally instantiates LZC (Leading Zero Counter) logic to normalize subnormal FP inputs:
- `fp8_m_lzc`, `fp16_m_lzc`, `fp32_m_lzc`: Count zeros in mantissas of FP formats.
- Used for wide FP conversions (e.g., fp8→fp16, fp16→fp32, etc.)

---

## Type Conversion Logic

The `type_conversion` block:
- Handles all widening cases (sign/zero-extension for int8→int16/32/64).
- Supports floating-point widening with exponent/mantissa adjustment.
- Applies neutral padding for inactive lanes during reductions.
- Includes element reordering logic for FP conversions and `shuffle_index`.

Conversion modes supported:
- `OpQueueConversionSExt*`, `ZExt*`, `WideFP2`, `AdjustFPCvt`
- Neutral-padding via `OpQueueReductionZExt` or default padding for final packet

---

## Neutral Value Padding for Reductions

When `SupportNtrVal` is set and reduction is active:
- MSBs are padded with harmless neutral values to avoid altering result.
- Based on EEW (element width) and command-provided `ntr_red`.

Neutral values vary per target (ALU, MFPU) and FP format, with special encoding:
- e.g., `0x7ff0000000000000` for FP64 max

---

## Operand Output Control

Output logic in `obuf_control` block:
- Tracks how many operands have been emitted (`elem_count_q`)
- Selects sub-operands in packet (`select_q`)
- Pops from FIFO when all elements of an operand are consumed
- Updates target FU routing info
- Resets state on flush or command completion

Operand conversion and sequencing are tightly controlled to maintain data integrity across pipeline stages.

---

## State Management

Sequential registers:
- `select_q`, `elem_count_q`: Maintain operand fragment selection and element counter.
- Updated on each operand emission or reset on flush.

---

## Conclusion

The `operand_queue` module is a sophisticated component handling:
- Pipelined operand buffering
- Element-wise manipulation (conversion, widening, neutral fill)
- Intelligent control of operand delivery timing
- Support for multiple vector formats, FP pipelines, and reduction ops

It ensures high flexibility and correctness in vector operand preparation before execution in Ara’s VFUs.

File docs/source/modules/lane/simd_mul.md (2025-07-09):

# `simd_mul` — Ara's in-lane SIMD multiplier

**Module Name:** `simd_mul`
**Function:** This module implements a SIMD vector multiplier for Ara.

---

## Overview

The `simd_mul` module is Ara’s SIMD multiplier, supporting 8/16/32/64-bit elements and fixed-point multiplication with rounding and saturation. It operates in a pipelined manner and can produce one 64-bit result per cycle when fully utilized. It supports several RISC-V vector arithmetic operations (`VMUL`, `VMULH`, `VMULHU`, `VSMUL`, `VMADD`, `VMACC`, etc.).

---

## Parameters

| Parameter | Type | Description |
|---|---|---|
| `FixPtSupport` | `fixpt_support_e` | Enables fixed-point support and saturation logic. |
| `NumPipeRegs` | `int unsigned` | Number of pipeline stages. |
| `ElementWidth` | `vew_e` | Specifies element width (EW8, EW16, EW32, EW64). |

---

## Interface

| Port | Direction | Type | Description |
|---|---|---|---|
| `clk_i` | Input | `logic` | Clock. |
| `rst_ni` | Input | `logic` | Active-low reset. |
| `operand_[a|b|c]_i` | Input  | `elen_t` | Vector operands. |
| `mask_i` | Input | `strb_t` | Element-level mask. |
| `op_i` | Input | `ara_op_e` | Operation selector. |
| `vxrm_i` | Input | `vxrm_t` | Rounding mode. |
| `valid_i` | Input | `logic` | Input valid handshake. |
| `ready_o` | Output | `logic` | Input ready. |
| `result_o` | Output | `elen_t` | Computed result. |
| `mask_o` | Output | `strb_t` | Mask forwarded to next stage. |
| `vxsat_o` | Output | `vxsat_t` | Saturation flags. |
| `valid_o` | Output | `logic` | Output valid. |
| `ready_i` | Input | `logic` | Output ready handshake. |

---

## Key Internal Structures

### Operand Packing (`mul_operand_t`)
Unions the operand into multiple views (64, 32, 16, or 8-bit chunks) for ease of SIMD processing.

### Pipeline Buffers
Multi-stage pipeline implemented using shift-register logic, enabled via `NumPipeRegs`. All operands, opcodes, masks, and valid bits are pipelined.

### Ready Valid Interface
Flow control logic supports handshake-based data propagation through the pipeline.

---

## Functional Description

### Multiply Logic
Supports various operations:
- `VMUL`, `VMULHU`, `VMULHSU`, `VMULH` → Integer multiply
- `VSMUL` → Fixed-point multiply with rounding/saturation
- `VMACC`, `VMADD`, `VNMSAC`, `VNMSUB` → Multiply-accumulate & multiply-subtract

### Signedness
Sign control logic dynamically selects signed/unsigned behavior based on opcode (`signed_a`, `signed_b`).

### Result Rounding
Rounding logic for `VSMUL` is driven by `vxrm` mode:
- 00: round to nearest even
- 01: round to nearest, tie to max magnitude
- 10: truncate
- 11: ceiling

### Saturation (`vxsat`)
When enabled (`FixedPointEnable`), detects overflow and sets corresponding saturation bits.

---

## Element Width Handling

For each supported width, dedicated combinational blocks handle:
- Partial multiplications
- Optional fixed-point rounding/saturation
- Result assembly and output formatting

### EW64
- 1 × 64-bit operation
- Uses full 128-bit product

### EW32
- 2 × 32-bit elements
- Operates on upper/lower halves

### EW16
- 4 × 16-bit elements
- Operates on 16-bit lanes

### EW8
- 8 × 8-bit elements
- Operates on each byte independently

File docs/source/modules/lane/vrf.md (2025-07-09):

# `vrf` — Ara's Vector Register File (VRF)

## Ara Vector Register File

The Vector Register File (VRF) of Ara is implemented using a set of single ported (1RW) memory banks. The width of each bank is 64-bits which is the same as the width of the datapath of each lane. There are eight banks per lane resulting in eight single ported memory banks per lane. In the RVV ISA there are 32 vector registers. The size of each vector register, in bits, is implementation dependent (minimum = 128 bit).  Let's look at the size of VRF by using an example.

Size of Vector register  (VLEN) = 4096 bit

Size of Vector Register File = 4096 * 32 = 217 bits = 16 KiB

Number of Lanes in Ara can vary from 1 to 16 (implementation dependent). So for a 4 lane system the VRF will be divided into 4 lanes with 4KiB of memory per lane.

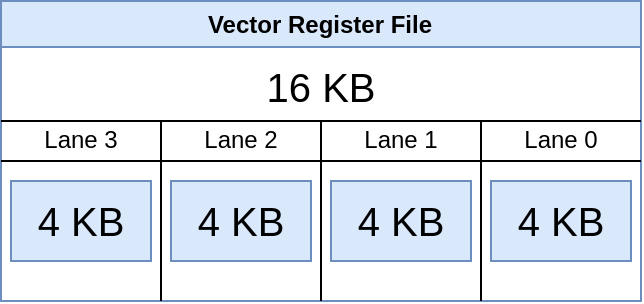
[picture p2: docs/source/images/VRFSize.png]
Image Here


Benefits of splitting VRF across lanes:

* As lanes are our processing elements so most computation constrained within one lane makes hardware implementation easy.

* Removes the dependency of the execution units  on the number of lanes which makes Ara scalable.

* As VRF is internal to the lane routing between VRF and lane execution logic is simplified.

### Division of VRF into Banks

As indicated earlier the portion of VRF inside a lane is further divided into eight 64-bit wide banks. Each bank is implemented using a single-ported SRAM memory. Being a single ported memory it has only one address port for both reads and writes. In steady state, under worst case conditions, 5 banks are accessed simultaneously in order to support predicated multiply-accumulate instructions (which require 3 source registers plus the mask register resulting in 4 reads, and one destination register -resulting in a single write). This is the worst case for a single instruction. But more instructions can be executed at the same time in different units (e.g. vload + vslide + vmacc.m) and they can access up to 8 banks per lane at the same time all together.

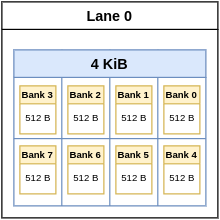
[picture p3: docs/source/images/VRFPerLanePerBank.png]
Image Here


Continuing with the earlier example, where each of the four lanes has 4KiB of memory, each lane will as such have 8 banks of 512B (4096B / 8 =  512B) memory. Given that each bank is 64-bits wide there will be 64 (512B/8B = 64) 8B wide addressable locations within each bank.

Since each lane has  4KiB of VRF memory the address bus, going to each lane,  will be 12-bits wide. Since there are 8 banks within a lane the least significant 3 bits of the address are used for addressing the 8 banks and the remaining 9-bits are used to address the byte within the bank. Of these remaining 9-bits, 6-bits are used to address 1-of-the-64 64-bit locations within the bank and the remaining 3 bits of the address are used to address the individual byte within the 64-bits.

Image Here

### Translating Vector Register Number to SRAM memory Bank

Vector register number fields ranging in value from 0 to 31 (5-bits) are present in the instruction. They are decoded and used to determine the starting address of that vector register in the VRF memory. Within a lane the vector registers are stored as a contiguous set of bytes. The register number (vid) is multiplied by a factor which is equal to the number of bytes in a single vector register divided by the number of lanes. The resulting number gives the starting address of the vector register in the VRF memory.

For normal cases the starting address of every vector register is a multiple of 8 given that the multiplying factor that is used is a  power of 2 and  greater than or equal to 8. For our continuing example this factor is equal to 128 [(4096/8)/4].  In some cases where VLEN is small e.g.128, and number of lanes are high e.g. 16 this is not true.  So if the address is a multiple of 8  then the least significant three bits of the address are always 0.  As indicated earlier the least significant 3 bits of the address are used to select the bank. As such every vector register has its first element (its starting point) in the first bank i.e., bank 0 and this will cause bank conflicts which are discussed later.

Continuing with our example the following table gives the starting address in the VRF memory for all 32 vector registers. As can be seen the last nibble of every address is 0 implying that the last 3 address bits are always 0 and as such always pointing to bank 0.

.. csv-table:: Starting Address of 32 Vector Register in VRF Memory
   :file: /documents/Vector_Starting_Addr.csv
   :header-rows: 1

This arrangement causes bank conflicts because banks are composed of single ported memories and as such only a single request to read or write an operand can be sent to a bank. However functional units can request multiple operands simultaneously and as such need to access the same bank at the same time causing bank conflicts.

To resolve bank conflicts Ara uses a weighted round robin priority arbiter per bank. Mask register (v0) has the highest priority, followed by reading of operands A, B, C, and then writing a destination register.

### Organization of Elements in Vector Register File

Elements of a  vector register are mapped to consecutive lanes in the VRF. Each lane’s  datapath width is 64 bits which matches the width of an individual register file bank. The  figure below shows 4 lanes, numbered 0-3  with each lane having 8 bytes (64 bits) and the consecutive bytes numbered 0 - 1F. Since there are functional units present in each lane, groups of elements can be processed in parallel. For example if we have four 64-bit elements and four lanes then each element is placed in a different lane shown by the numbers 0-3 below. All 4 of these elements can be accessed simultaneously from the VRF and can be operated upon in parallel.

Image Here

Continuing with the previous arrangement across lanes, elements within a single lane are also arranged in an order such that when the element width changes the mapping between some of the elements and lanes remains the same. Due to this, the mapping between consecutive bytes in a lane and consecutive bytes of an element is not the same. This is resolved by using shuffle logic described in the next section.

As an example with a vector length of 256B (2048-bits) and 4 lanes each of which are  64-bits wide the mapping of bytes for various sizes of SEW are shown below:

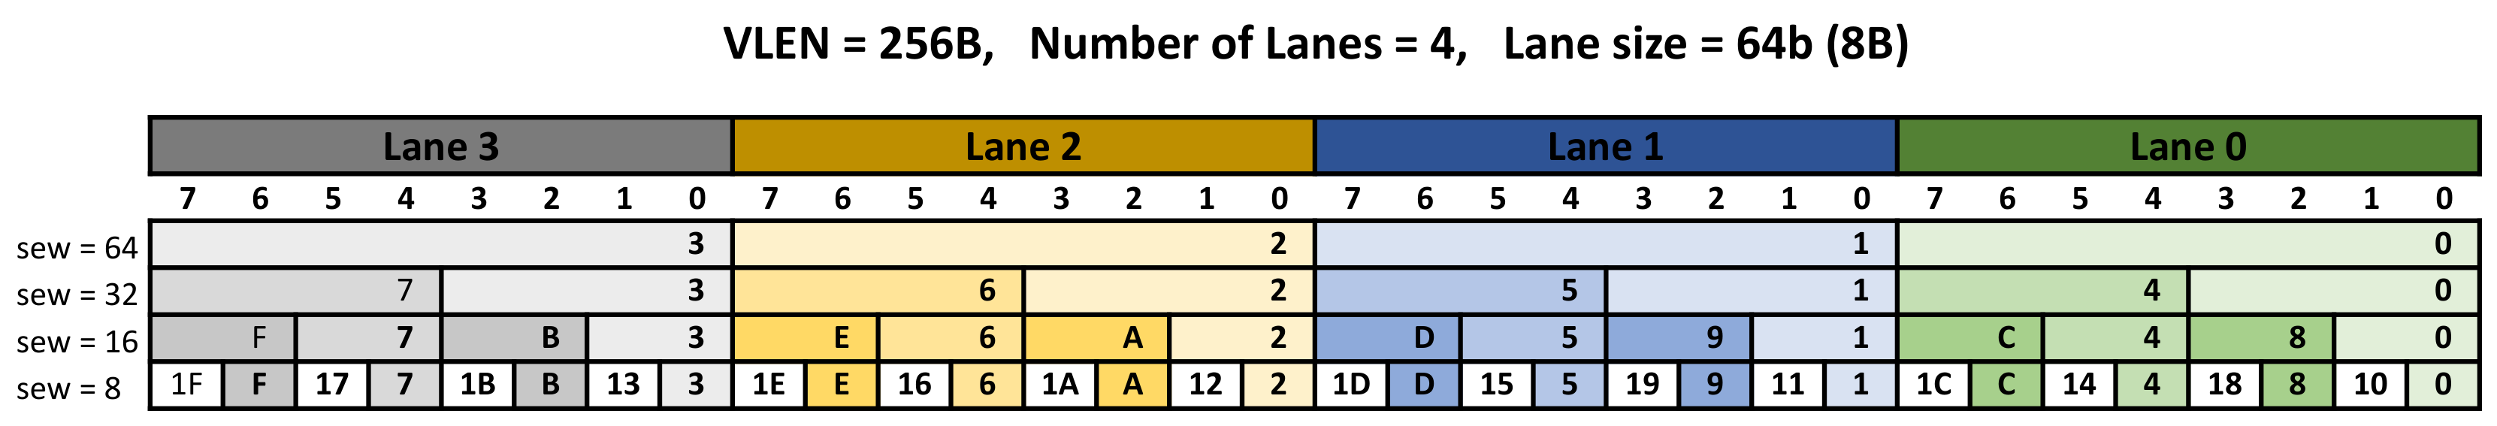
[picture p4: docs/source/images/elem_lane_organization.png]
Image Here


For the first case (SEW = 64) the arrangement is simple and obvious. Each 64-bit element is mapped into a different lane and the bytes of each element are contiguously stored within the lane. For the second case (SEW = 32) elements 0, 1, 2 and 3 are mapped in the lower half (32-bit) of lane 0 through lane 3. Element 4 then gets mapped to the upper half of lane 0 and so on until element 7 gets mapped to the upper half of lane 3. It is important to note that the least significant byte of  elements 0, 1, 2 and 3 for both cases of SEW are mapped to the same byte location within the corresponding lanes.  This process continues to be repeated for the remaining values of SEW.

In the case of SEW = 16 and 8 there is an additional thing to observe. When we start from lane 0 to start assigning the first byte of a new element we also observe which half of the lane (upper or lower 32-bits) the last element in the lane was assigned.  For the new assignment we pick the half which was not used the previous time. So in the case of SEW = 16  when it comes time to assigning element 8 it is placed in Lane 0’s byte position 2 (lower half of lane 0) and not byte position 6 (upper half of lane 0)  since the last element assigned in lane 0, element 4, was assigned in byte position 4 (upper half of lane 0).

The above arrangement of elements and their corresponding bytes in the VRF is constrained within the lane. Data outside the lane i.e in memory, is arranged with bytes packed simply from the least-significant byte to the most-significant byte in increasing memory addresses. As such when data is moved between the memory and the VRF bytes get shuffled/de-shuffled to match the appropriate required ordering. These two ordering of elements and bytes is referred to as Lane Organization of bytes and Natural Packing of bytes.

**Lane Organization:** The manner in which elements and their corresponding bytes are stored in the VRF as discussed above.

**Natural Packing:** The elements and bytes packed in memory with the least-significant bye to the most-significant byte in increasing memory addresses.

### Shuffle Logic

As shown in the figure below the shuffle/de-shuffle logic sits between the memory subsystem and the VRF. When data is moved from memory to the VRF (via a load instruction) it gets shuffled from the Natural Packing arrangement to the Lane Organization arrangement. Similarly When data is moved from VRF to memory (via a store instruction) it gets de-shuffled from the  Lane Organization to the Natural Packing arrangement.

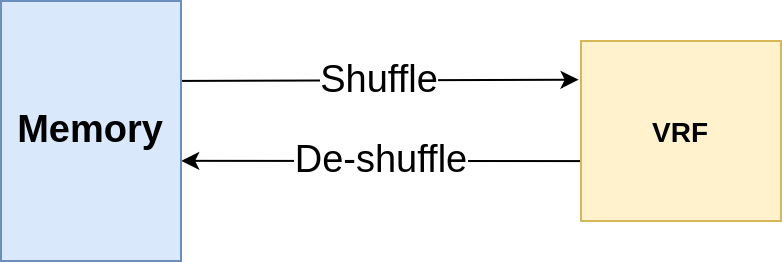
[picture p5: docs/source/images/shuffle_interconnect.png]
Image Here


The mapping of bytes from Natural Packing to Lane Organization for 4 lanes and SEW of 16 is shown in the figure below.  For element 0, byte indices are the same, 0 & 1, for Natural Packing and Lane Organization. Element 1 is mapped  to byte index 8 in the VRF with its two bytes in indices 8 & 9 in the VRF. Shuffle logic takes the sequential bytes from memory as shown in the natural Packing row and converts it into the Lane Organization arrangement as shown in the Lane Organization row. De-shuffle logic does the opposite.

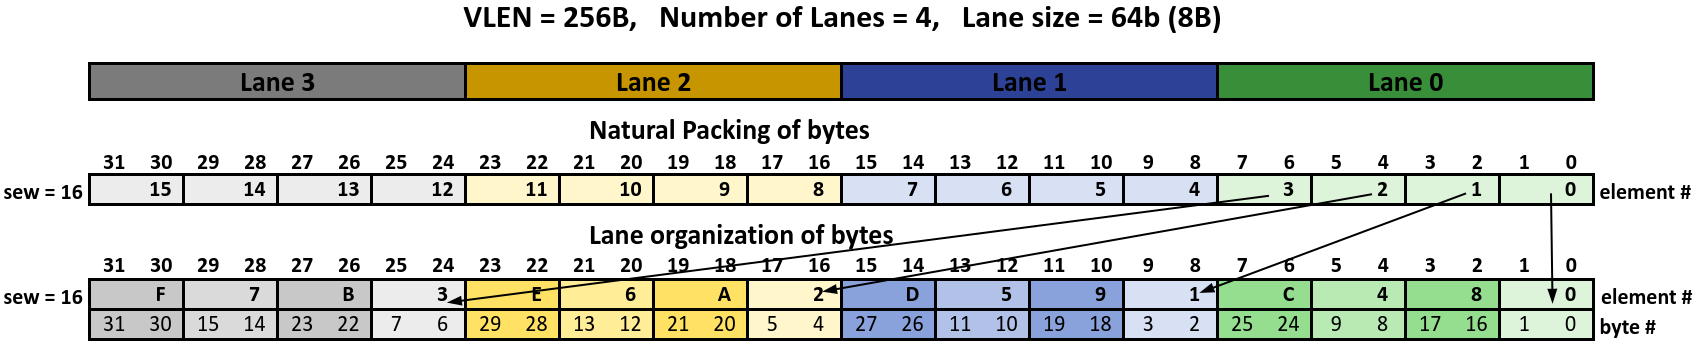
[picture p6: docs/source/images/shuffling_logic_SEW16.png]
Image Here


The arrangement of the shuffle/de-shuffle logic is a function of the vector’s SEW. This means that when a vector is moved from Memory to the VRF bytes get shuffled based on the value of the vector’s SEW. Similarly when a vector is moved from the VRF to memory bytes get reshuffled based on the vector’s SEW. As such in addition to the bytes of a vector being stored in the VRF it also gets tagged, in hardware, with its SEW. This tag is subsequently used by the de-shuffle logic when data is moved back to memory.

The following figure shows how bytes are stored in memory (Natural Packing) and how they get stored in the VRF (Lane Organization.) Thirty two bytes named A0 to H3 are stored sequentially in memory locations 0 through 31 (natural ordering)  as shown in the Memory image below. Subsequently these 32 bytes are stored in the VRF using different SEW values as shown in the VRF image below.

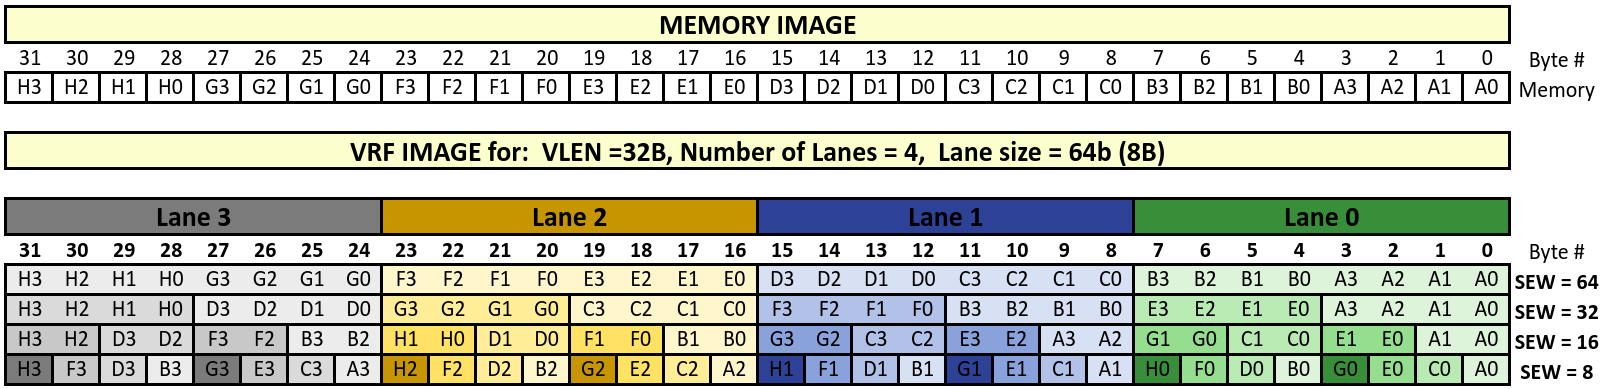
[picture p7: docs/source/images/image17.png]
Image Here


For example Lane 1’s byte location 11 can have memory bytes C3, B3, E3 or G1 for SEW values 64, 32, 16 and 8 respectively . So the shuffle multiplexor for this byte is as follows:

Lane 1 [ location 11]  =  (SEW = = 64) ? C3 : ((SEW == 32) ? B3 : ((SEW == 16) ? E3 : G1))

Similarly the deshuffle multiplexor for memory location 11 is as follows:

Memory [location 11] =   (SEW = = 64) ? Lane 1[location 11)] :  ((SEW == 32) ? Lane 2[location 19] : ((SEW == 16) ? Lane 1[location 13] : Lane 3[location 25]))

These byte multiplexores get replicated in both directions for every byte coming from memory into the VRF and every byte going out from the VRF to memory.

### Reshuffle Logic

In a multi-lane architecture with the VRF distributed across multiple lanes, certain peculiar issues arise for instructions which cross lane boundaries (e.g., the narrowing and widening instruction). These issues get further exacerbated because of the architectural requirement of supporting the tail-undisturbed policy i.e., the requirement that elements past the vector length should not be modified. When an instruction writes to a vector register, vd, that was originally encoded with a EEW different than the new EEW and the old contents of vd are not fully overwritten then the old contents of vd get corrupted and the tail undisturbed policy gets violated. To avoid this corruption of the tail elements the slide unit, which has access to all the lanes, performs a shuffling operation on the vector register. This shuffling operation is called reshuffle.

Let us take the example of a simple vector unit with a 256bit (32B) wide vector register and four lanes with each lane being 64bit (8B) wide. Each lane has a single 256B SRAM bank configured as 32x64bit wide 1R1W port memory. As such each bank implements a ¼ of the VRF. The examples below are limited to SEW values of 16 and 32.

Mapping of vector elements, in the SRAM, based on Natural Packing is shown below:

Image Here

Mapping of vector elements, in the SRAM, based on Lane Organization is shown below:

Image Here

Each lane has 8 bytes of the vector and the vector elements are mapped starting from Lane 0 all the way to Lane 3.
For Natural Packing & SEW = 32 Lane 0 contains elements 0 and 1, Lane 1 contains elements 2 and 3, Lane 2 contains elements 4 and 5 and Lane 3 contains elements 6 and 7. Similarly the mappings of the 16 elements for SEW = 16 are also shown. As such consecutive elements of the vector register are stored in consecutive lanes.
For Lane Organization & SEW = 32 Lane 0 contains elements 0 and 4, Lane 1 contains elements 1 and 5, Lane 2 contains elements 2 and 6 and Lane 3 contains elements 3 and 7. Similarly the mappings of the 16 elements for SEW = 16 are also shown. Here consecutive elements are stored in different lanes.
The following memory image is used in the examples below. Consecutive vector bytes are stored in consecutive locations in memory.

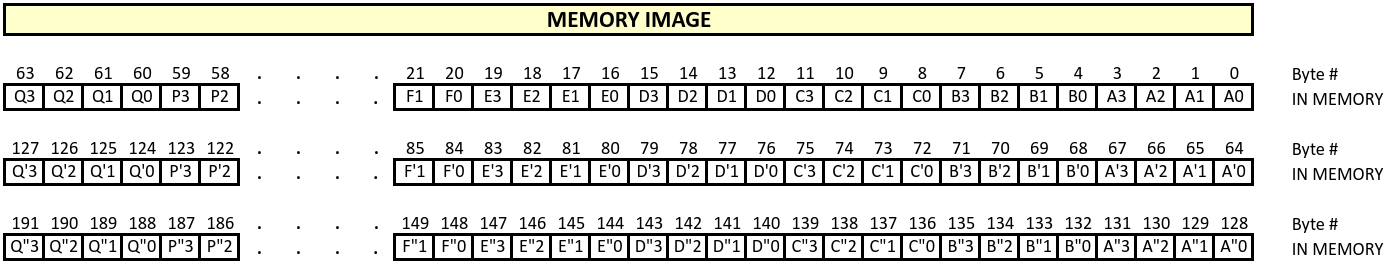
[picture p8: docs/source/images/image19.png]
Image Here


Bytes are numbered from A0 through Q”3 with A0 stored in memory location 0 and Q”3 stored in memory location 191.
In the case of Natural Packing data movement between memory and the VRF is fairly straight forward and there is a one to one mapping between the memory image and the VRF image of individual bytes. In case of Lane organization, as discussed above,  the mapping is not straight forward and requires a shuffle/deshuffle unit between the memory and the VRF to get the data bytes in the correct position.

#### Natural Packing

Let us take an example of a Narrowing instruction with source SEW = 32 and LMUL = 2 and a destination EEW = 16 and the corresponding EMUL = 1. Taking the case of Natural Packing we look at the case with the destination register initially having a SEW of 32. Below the source registers are identified as Vs and Vs+1. The destination register before the instruction is executed is identified as Vd’:

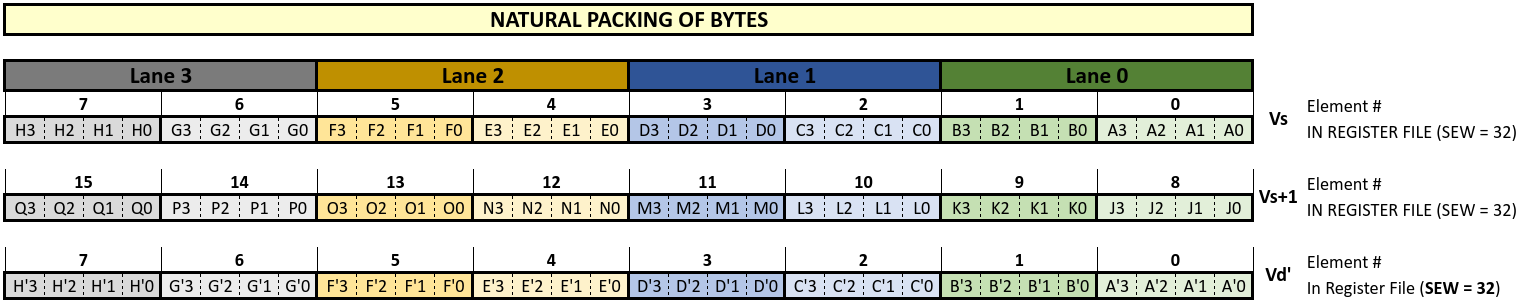
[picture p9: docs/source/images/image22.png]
Image Here


Since the source SEW = 32 there are 8 elements in each source register for a total of 16 elements and 64 bytes. These 64 bytes A0 – Q3 are loaded from memory locations 0 to 63 into the source registers.

The vector length, vl, for the narrowing instruction is set to 11. This means that only the first 11 elements of the destination register, Vd, should be modified and the remaining 5 elements of the destination register are part of the tail and should not be disturbed. Taking the Vector Narrowing Integer Right Shift Instruction as an example:

Narrowing Instruction (source 4 bytes, shift amount = 0) -> Destination 2 bytes

e.g., for the first source element A3A2A1A0:

Narrowing Instruction (A3A2A1A0, 0) -> A”1A”0

with A”0 being the least significant byte and A”1 being the most significant byte of the resulting 16bit result. Note the bytes are identified with a (“) but they are the source’s least significant bytes A0 and A1.

Vd” shows the content of Vd’ after the instruction is executed:

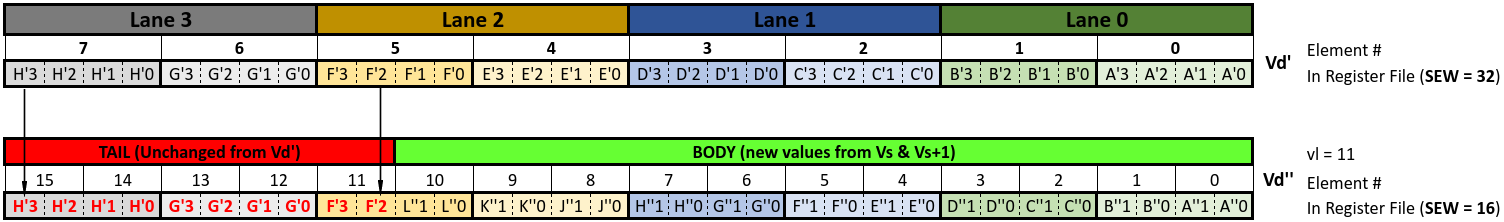
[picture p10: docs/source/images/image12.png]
Image Here


Result bytes move across lanes, requiring the use of the Slide unit. The destination bytes (from Vd’) that should remain unchanged get preserved and transferred to Vd” as shown above in a straightforward manner.

The case with Vd’ having a SEW of 16 before the execution of the instruction is shown below:

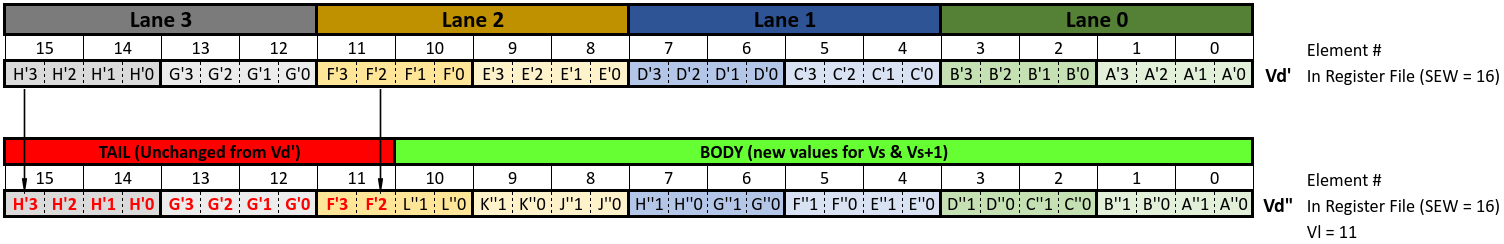
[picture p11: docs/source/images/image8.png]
Image Here


Once again destination bytes that should be unchanged (from F’2 to H’3) get preserved and transferred to Vd”. Hence if bytes are mapped in the VRF according to Natural Packing order the tail undisturbed policy gets implemented without requiring any special logic.

#### Lane Organiation

Now let’s look at the case of Lane Organization of the VRF. The source registers and the destination register (before instruction execution) are shown below. This is the case where initially the destination register has a vector with SEW = 32 stored in it. As can seen in this organization consecutive bytes from memory are not stored in consecutive lanes because the elements are not stored in consecutive lanes.

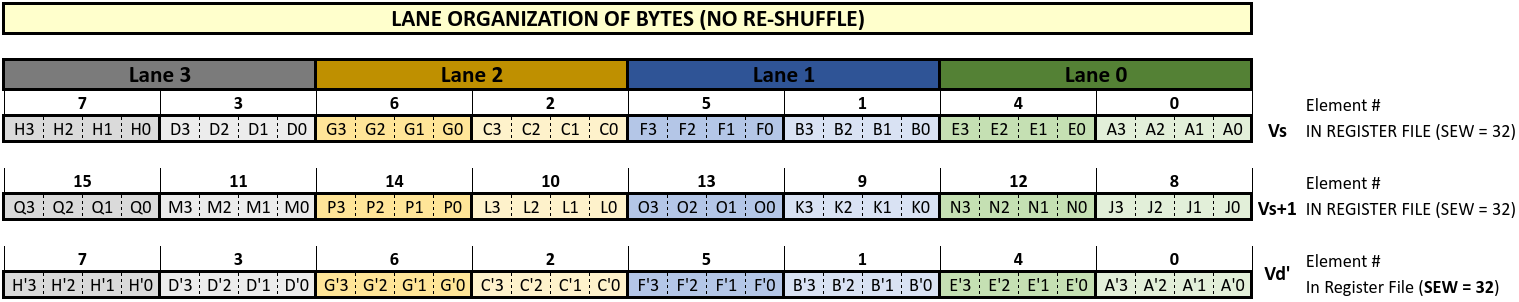
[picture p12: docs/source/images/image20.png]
Image Here


After the Vector Narrowing Integer Right Shift Instruction is executed Vd changes as shown below from Vd’ to Vd”:

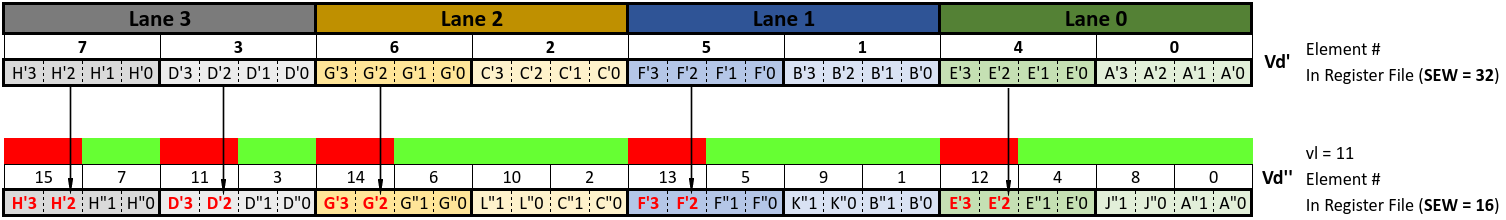
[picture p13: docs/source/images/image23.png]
Image Here


The last 5 tail elements are unchanged between Vd’ and Vd”. However because these elements are not stored in consecutive locations they are now distributed across all four lanes. Now de-shuffling these (using the de-shuffle multiplexor discussed earlier) so that it can be written to memory in the correct order we get:

Image Here

Comparing this with Natural ordering we see that two of the tail elements are totally incorrect and two are in the wrong position (only one element is correct and in the correct position.) These discrepancies can be resolved by shuffling the contents of the destination register before the instruction is executed and ordering the elements of the destination in line with the new destination EEW. This step is called reshuffle and is shown in the figure below. For ease of understanding this reshuffle process is shown as a two-step process below.

    Step 1: the destination is de-shuffled  into natural ordering based on its existing EEW

    Step 2: the result of step 1 is shuffled  into lane organization based on the new EEW.

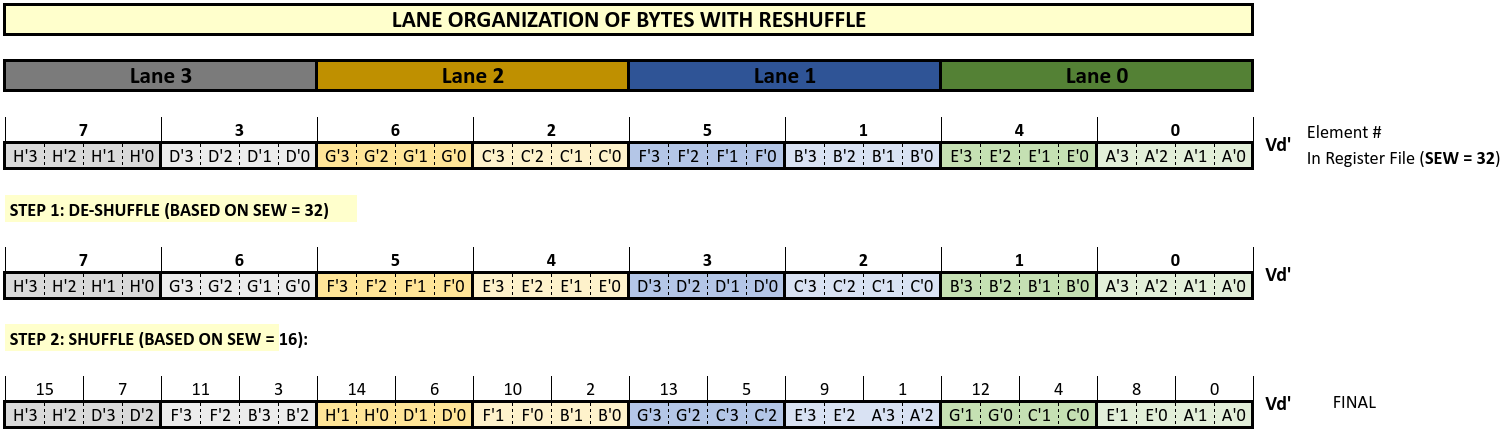
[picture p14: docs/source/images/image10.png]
Image Here


Now using this new reshuffled Vd’ and executing the narrowing instruction we get:

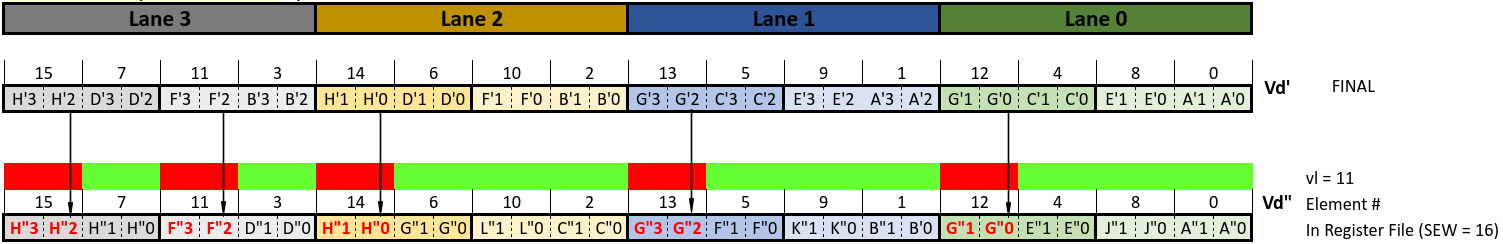
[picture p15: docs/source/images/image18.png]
Image Here


Now de-shuffling these so that it can be written to memory in the correct order we get:

Image Here

Comparing this with Natural Ordering we see that the correct tail elements are preserved in the correct locations. Hence by reshuffling the destination register so that it’s SEW matches the EEW of the instruction’s destination register EEW we can correctly implement the tail undisturbed policy.  As is obvious from the figure above if the SEW & EEW match then reshuffling is not required.

### Mapping of Vector Elements to the Memory Banks

Continuing on let's look at the mapping between the elements of an individual vector register and the VRF memory banks. As an example with VLEN=4096, SEW=64 and 4 lanes, we have a total 64 elements which are numbered from 0 to 63. In Natural packing vector representation V0 is shown below with Vn[x] indicating the xth 64-bit element of the vector register Vn:

Image Here

In the VRF the individual vector registers and their corresponding elements are distributed across 4 lanes. Continuing with our example elements of vector register V0 are distributed across lanes and memory banks as shown below:

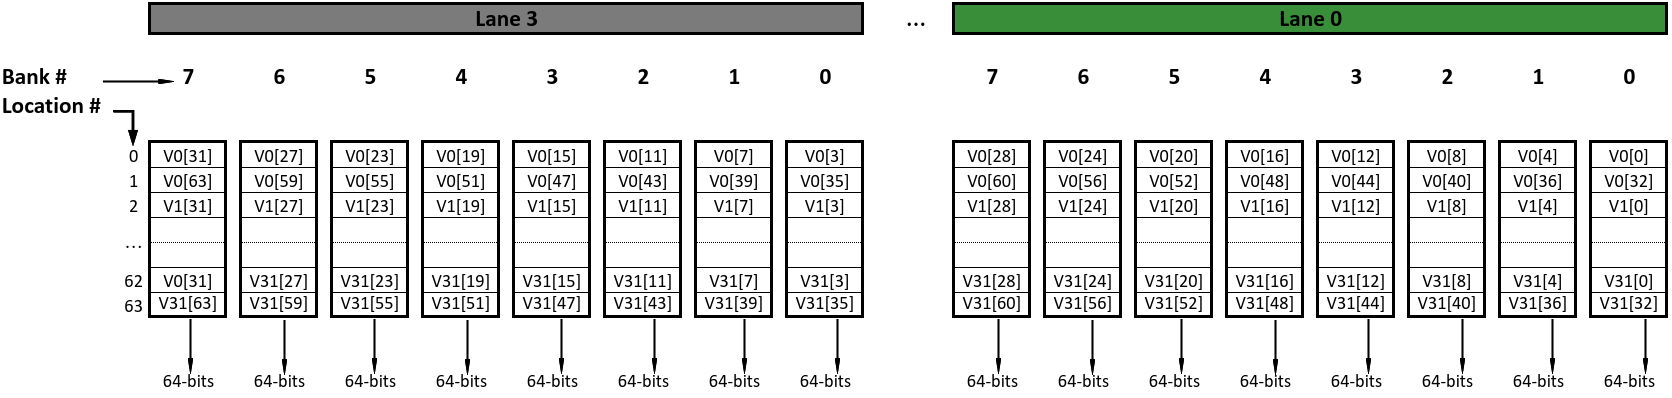
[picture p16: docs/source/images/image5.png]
Image Here


For 4 lanes a 4096-bit (512B) vector requires 64 memory banks with each bank being 64-bits wide. Since there are 4 lanes with each lane having 8 banks there are a total of 32 banks in a single “row” location. Hence two memory row locations are needed for the full vector. This can be seen in the figure above, for SEW = 64, where memory row locations 0 and 1 are occupied  by V0, locations 2 & 3 are occupied by V1 all the way to locations 62 & 63 being occupied by V31.

Taking another example for the same vector size of 4096-bit but with a SEW = 32 we have a total 128 elements which are numbered from 0 to 127. In Natural packing vector representation V0 is shown below:

Image Here

Once again, as discussed above, each vector register occupies two rows of memory banks. Since the element width is 32-bits and the bank width is 64-bits each bank contains two elements. This is shown in the figure below:

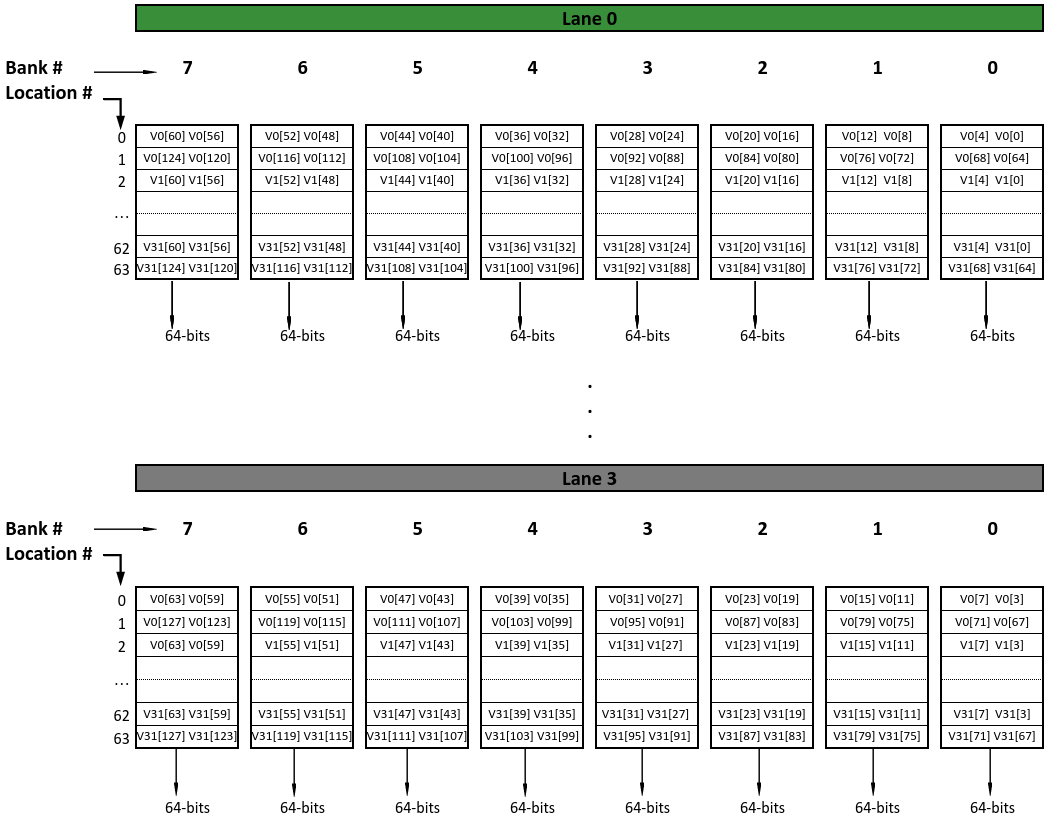
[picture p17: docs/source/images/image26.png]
Image Here


### Vector Register File and Operand-Delivery Interconnect

Each lane of the vector processor has 3 functional units:

1.  Vector Floating-point Unit (VFPU)
2.  Vector Multiplier (VMUL)
3.  Vector Integer ALU (VALU)

A Vector Load & Store unit (VLSU) for Lector Load and Store instructions and a Slide unit (SLDU) for Vector Slide instructions are present as separate units outside the lanes.

The datapath of each functional unit matches the VRF memory bank width of 64-bits.

The lanes receive requests from the main Ara sequencer to execute vector instructions. The request contains the following information about the vector instruction:

- Vector and scalar source operand register numbers
- Mask register number
- Vector & scalar destination register numbers
- Effective length multiplier
- Value of the vector length
- Value of the vector start
- Vector type (values from the vtype CSR register)
- etc.

Every lane has its own sequencer (Lane Sequencer) that receives the requests and interfaces with the Operand Requester and the functional units.

The Operand Requester along with the Vector Register File Arbiter requests individual operand elements from the VRF banks. The target functional unit information etc., is also passed along with the request. The fetched operands from the VRF, for the functional units, are then passed to the Operand Queues. As discussed earlier the multi-banked organization of the VRF leads to banking conflicts when several functional units try to access operands in the same bank. Each lane is provided with a set of operand queues between the VRF and the functional units to absorb delays due to such banking conflicts. Similarly writing results back into the VRF can also cause bank conflicts. Write Back  queues present at the output of each functional unit are provided to absorb any delays due to banking conflicts. All the queues are 64-bits wide.

There are nine Operand Queues connecting the VRF banks to the functional units:

- Three are dedicated to the VFPU/VMUL.
- Two are dedicated to the VALU.
- Two are dedicated to the Mask Unit.
- One is dedicated to the VLSU.
- One is dedicated to the SLDU.

Operand Queues send their operands to the functional units as the operands become available and the functional unit is ready for the next operation.

There are six Write Back Queues one from each of the Functional units. Each Functional unit has a Write Back queue inside the unit.

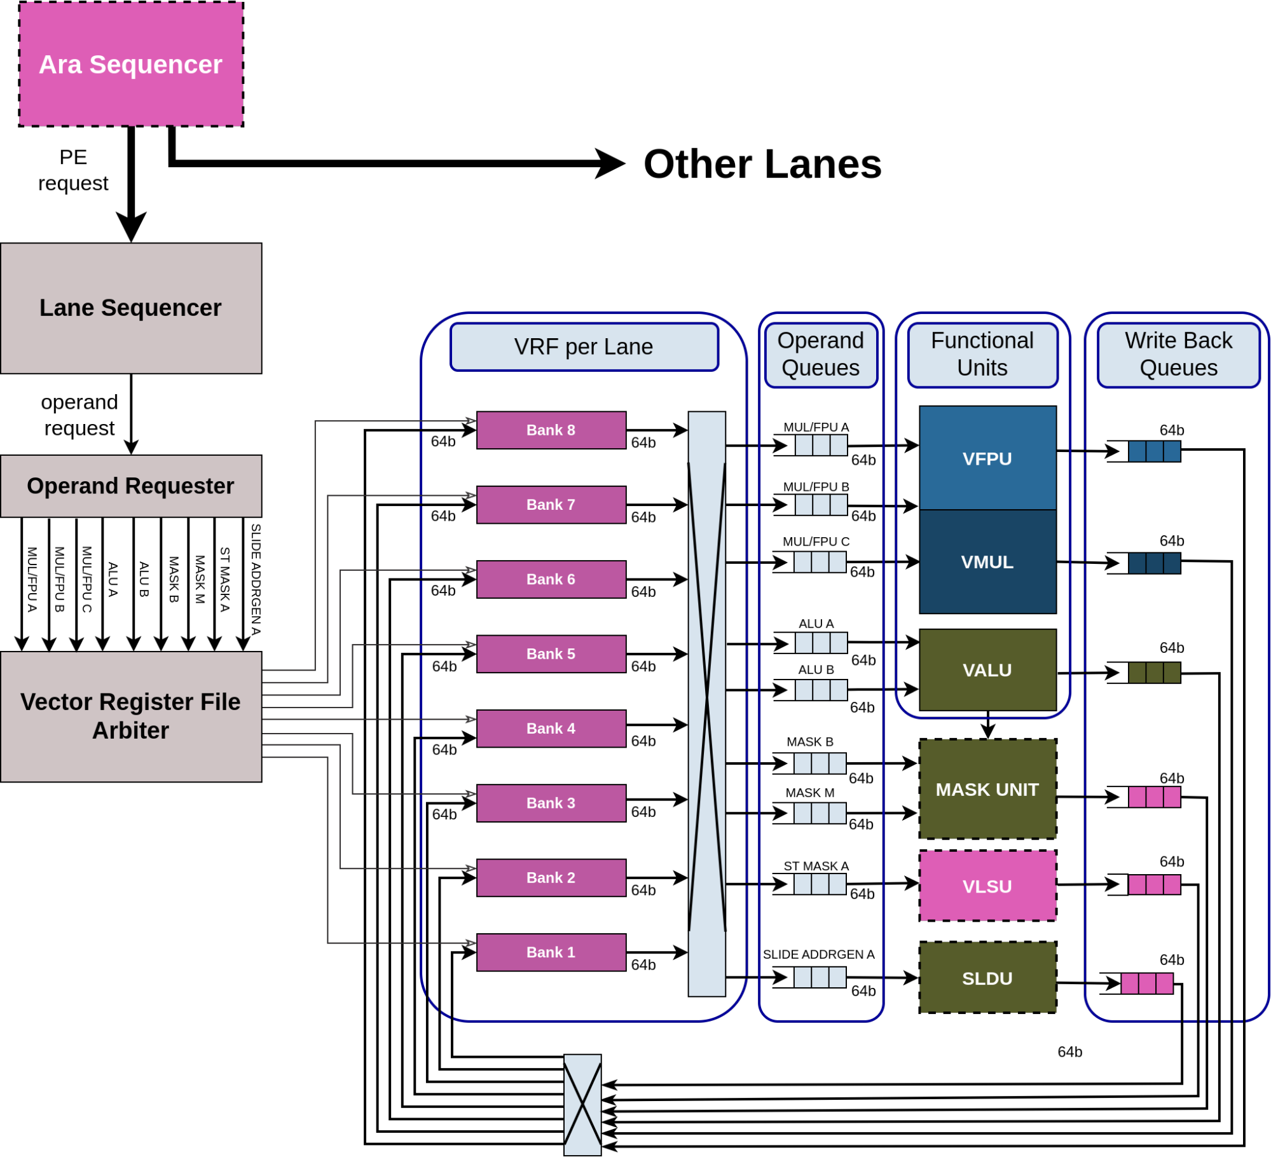
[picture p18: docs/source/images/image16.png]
Image Here


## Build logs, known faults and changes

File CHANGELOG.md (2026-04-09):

# Changelog
All notable changes to this project will be documented in this file.

The format is based on [Keep a Changelog](http://keepachangelog.com/en/1.0.0/)
and this project adheres to [Semantic Versioning](http://semver.org/spec/v2.0.0.html).

## [Unreleased]

### Fixed

 - Fix dump vtrace script for vsetvli instructions without x0 (ideal dispatcher)
 - Fix Pathfinder and FFT performance
 - Stall Ara and wait for ara_idle upon CSR write/read
 - Fix how VLSU reports exceptions
 - Set vstart=0 upon succesfull vector instructions
 - Fix vstart usage in ara dispatcher
 - Fix reshuffle mechanism
 - Fix vstart usage for memory operations
 - Fix fft, exp, softmax, roi_align performance
 - Fix printf bug (missing characters) - UART and CTRL memory regions are now idempotent
 - Start int reductions only if ALU result queue is empty
 - Fix `acc_dispatcher` CVA6 bug for instructions with side effects
 - Fix NaN/subnormal floating-point handling in opqueues
 - Stall vfdiv/vfsqrt instructions following/preceding other fp instructions
 - Bump upload and delete artifact actions
 - Fix synthesis-unfriendly constructs
 - Fix vector slicing bug in operand requesters
 - Fix legality check for allowed registers in dispatcher
 - Remove a couple of latches
 - Fix dispatcher state change upon vector CSR instruction
 - Force a reshuffle when `vl == vlmax && vstart > 0`
 - Align g++ version with cheshire's if simulating with it (for QuestaSim)
 - Don't compile the first-pass-decoder in CVA6 (need for a specific bender target)
 - Solve type-conversion warnings about type  - Indexed loads need to wait for operand requesters ready in sequencer
 - Drop sequencer `pe_req_valid` in case of exception
 - Reworked STU exception flush engine
 - Correctly flush the backend pipeline upon indexed load exceptions
 - Make addrgen wait for index address before making an MMU request
 - Fix typos in lane sequencer
 - Fix sldu/addrgen synchronization
 - Reset `vfirst`/`vcpop` accumulator when a new instruction starts
 - Fix wrong `eew` for mask comparisons in lane sequencer
 - Fix bug in ordered reductions
 - Avoid spurious valids to the simd multipliers
 - Fix ideal dispatcher (update the ara-cva6 interface)
 - Bump AXI (v0.39.4 is broken)
 - Remove timing loop in addrgen (triggered by CVA6 pulp-v2)
 - Fix latch in vmfpu
 - Remove spurious .c files from cheshire's test folder after compilation
 - RVV CSR instructions are "config" instructions in ara dispatcher
 - Reshuffle vector store's source reg group if emul > 1 and encoding is not homogeneous.
 - Pass CVA6Cfg to serial divider in Ara
 - Force cheshire's sim scripts re-generation
 - Fix u-boot to support RVV-linux
 - Fixed src emul check for vector integer extension operation

### Added

 - Add support for RISC-V Zvkned vector crypto AES instructions (`vaesdm`, `vaesdf`, `vaesem`, `vaesef`, `vaesz`, `vaeskf1`, `vaeskf2`) with configurable `CryptoSupport` parameter
 - Plot kernels-Vl performance plot
 - Print I$/D$ stall metrics
 - Add `spmv`, `conjugate_gradient`, and `gemv` kernels.
 - Add multi-precision matmul kernel
 - Add MMU interface between Ara and CVA6
 - Add virtual->physical address translation for Ara by sharing CVA6 MMU
 - Add Ara VLSU support for MMU exceptions
 - Add multi-precision conv3d
 - Add support for unit-stride, non-unit-stride, indexed segment memory instructions
 - Add support for fault-only-first loads
 - Extend the riscv-tests MASKU-related tests
 - Add support for vrgather/vcompress
 - Add parametrized support for 8-alt, 8, 16-alt floating-point
 - Add lavaMD `app`, benchmark, and performance plot
 - Add Cheshire bare-metal FPGA flow for vcu128 and vcu118
 - Add cva6-sdk submodule
 - Add Cheshire Linux FPGA flow for vcu128 and vcu118
 - Add RVV tests to be used with Cheshire's stub and specific debug environment.
 - Add ara-cheshire bender flow for vcs
 - Add support for `rvv-bench` instruction benchmarking/verification
 - Add original RiVec benchmark and port to AraOS flow
 - Add fmatmul-loop application
 - Add high-performance patches to cheshire and opensbi for AraOS

### Changed

 - Disable common_cells assertions when simulating with Verilator
 - Bender checkout instead of update
 - Remove Bender.local (use Bender.lock for reproducibility)
 - Update CVA6 to OpenHW group master branch
 - Optimize Jacobi2d
 - Benchmark only the vector kernel in roi_align
 - Improve cache warming functions
 - [f]dotproduct works on the vector length in elements
 - Optimize DWT
 - Fix pathfinder performance
 - Rename CSRs in dispatcher to improve clarity
 - Change from reporting "errors" to full "exceptions"
 - Bump CVA6 to version that supports "exceptions" reporting
 - VLEN is now a parameter of the ara architecture and does not depend on a define anymore
 - vlen_t, as a consequence, is now define within the architecture as a parameter/localparam
 - Refactor addrgen module
 - Memory size is now constant with NrLanes
 - Enable hierarchical verilation
 - Bump AXI and common cells to solve verilation warnings
 - Cut CVA6 - Ara combinatorial path on instruction interface
 - Parametrize OS support (disabled by default)
 - Cut ready-path between VLSU and MASKU
 - Relax tight ADDRGEN timing path
 - Time multiplex VCPOP and VFIRST ops in MASKU
 - Refactor MASKU
 - Remove bit-support for tail elements
 - Adapt mask tests to this behavior
 - Refactor the MASKU
 - The MASKU always receives balanced payloads from the lanes
 - Remove FPU support for opqueues that do not need it
 - Pre-calculate timing-critical addresses before addrgen stage
 - Update all GitHub Actions for CI
 - Update READMEs with FPGA implementation instructions
 - Optimize `addrgen` timing for OS-on operation
 - Enable OS by default
 - Bump CVA6 to pulp-v2
 - Re-parametrize the design with pulp-v2 parameters
 - Bump AXI version from 0.39.4 (broken) to 0.39.5
 - Bump default simulator to QuestaSim 2021.3
 - Bump CVA6 to pulp-v2 and update parametrization
 - Bump QuestaSim version
 - Bump LLVM to version 20.1.0
 - Update RVV intrinsics
 - Bump CI's OS to Ubuntu 22.04
 - Bump CI's Python to 3.12.0
 - Don't download heavy git submodule by default (reserve a make command for that)
 - Switch to a better buildroot mirror
 - CI frees up space in the runner before building a toolchain
 - Update documentation

## 3.0.0 - 2023-09-08

### Fixed

 - Avoid corner-case in which the sequencer issues the same instruction multiple times when two units become non-ready at the same time
 - The lane sequencer now calculates the correct number of elements to be requested by the `MASKU` operand requesters
 - When the instruction queue of the SLDU is not empty, read from it to update the commit counter, and not from the incoming request
 - Masked operations now target the MASKU as well for the issue checks in the main sequencer
 - The granularity of the issue checks/gold tickets is now at a PE level
 - Avoid losing hazard-related information in the pipeline between the main sequencer and the operand requesters
 - Fix anticipated grant bug from operand requester to LDU, SLDU, MASKU, because of the stream registers. Now, the three units wait for a final true grant before commiting
 - The mask unit does not require synchronized lanes anymore to commit an instruction
 - MASKU does not wait anymore for valid incoming data from inactive lanes
 - Fix corner-case comparison in MASKU to provide the expected behavior
 - Fix MaskB-queue vector length in the lane sequencer
 - VALU cleans up the partial result of a reduction when no more needed
 - VALU can step from normalOp->reduction and vice-versa without issues
 - VALU's counters can now count bits when operating on mask vectors
 - Fix the vector length for mask instructions that run on the VALU/VMFPU
 - Don't let indexed memory operations interfere with the reductions in MASKU
 - Enforce strict in-order execution of FPU operations in VMFPU
 - Fixed AXI-inval-filter policy for D$ lines invalidation upon vector stores that are misaligned w.r.t. the D$ line width
 - Fix lane sequencer checks for floating-point comparisons
 - Fix synthesis error occuring due to the continuous assignmnet in the always block of mask unit
 - Fix wrong variable in `vmerge` and `vmv` `riscv-tests`
 - Re-introduce WAIT_STATE to avoid hazards when changin LMUL
 - Fix the PEs-ready signals related conditions in the main sequencer
 - Fix misaligned memory operations with more than 255 beats (>= 256 beats)
 - Fix stripmining condition in dispatcher
 - CVA6 tracks writes to floating-point scalar registers by the accelerator
 - Fixed de-synch bug in vector-FPU
 - Fix masked VSLIDEUP. Use only the mask bits with index higher than the stride
 - Fix SLDU issue_counter modification upon new VSLIDEUP incoming instruction
 - Fix whole-register-move destination register re-encoding
 - `vslide1up` always writes the scalar element in `vd`
 - Don't trim `vslide1up` counters since it always writes the scalar element
 - Wait for the current reduction to be over to execute the next VALU instruction, also when reduction workload is unbalanced and some lanes are only a pass-through
 - Reshuffle the source registers vs when an in-lane operation operates on element with vsew != eew_q[vs]
 - Fix the data target for `.spike` app compilations
 - `make -C apps clean` performs a deeper clean of the temporary object files
 - Fix riscv-isa-sim patch and bump pointer to riscv-isa-sim submodule
 - Fix VALU issue_counter initialization for mask logical operations
 - `vslideup` instructions that have `stride >= vl_q` have no effect
 - `benchmark.sh` keeps into account the number of lanes during program compilation
 - Fix typo in `performance.py` related to `fconv2d`
 - Fix lmul checks on `vs1` for conversion instructions
 - Fix `eew_vs1` for widening instructions
 - Fix cleaning of the accumulator after partial reduction in `valu`
 - De-parametrize FFT on the data-type
 - New reductions should start only when the previous operation is over
 - Prevent VMFPU from acknowledging the opqueues when their issue is over
 - Operand requesters sanitize partial operands during a reduction
 - Fix load/store-complete signals to CVA6
 - Remove latches/repeated-signals from `masku`
 - Reshuffle all the registers of a register group that have `eew_q != eew_d` when `LMUL > 1`
 - `VLXE` and `VSXE` need to wait that the SlideAddrGenA opreq is free before being issued by the lane sequencer to the operand requester stage
 - Do not trap instructions with no operands in the main sequencer
 - Commit a reduction only after a grant from the VRF
 - Solve duplicate verify function in `roi_align`
 - Don't let the lanes sample more than once the same instruction when the workload is unbalanced and the instruction stalls in the main sequencer
 - Don't mute instructions on mask vectors in the lane sequencer when `vl == 0` in that lane
 - Remove unintentional latches from `valu`, `simd_mul`, `lane_sequencer`
 - Fix `vxsat` CSR update in `dispatcher`
 - Fix parameter passing through the hierarchy for fixed point support
 - Decouple `cmdBuffer` and `dataBuffer` depths in opQueues
 - Avoid handshaking wrong results in VMFPU
 - Fix eew reshuffle for mask logical operations
 - Fix eew reshuffle for `vmv.v.v` operations
 - Remove timing loop between `vmfpu` and `operand_requesters`
 - Solve some of the Warnings from SpyGlass run
 - Fix masku handshake. All the lanes should handshake together in input
 - Start solving `sldu` counter widths warnings
 - Fix `vslideup` wrong counter trimming
 - Reset gating registers before the integer multipliers in `vmfpu`
 - Fix narrowing for `vnclip` and `vnclipu`
 - NaN-box the scalar value before forwarding back to CVA6
 - Filter operand queue ready_i from addrgen and sldu selectively when they should not handshake
 - CI: don't check the patch directory for whitespace changes

### Added

 - The sequencer can issue instructions to non-full units even if the other units are full
 - Vector indexed unordered/ordered load (`vluxei8`, `vluxei16`, `vluxei32`, `vluxei64`, `vloxei8`, `vloxei16`, `vloxei32`, `vloxei64`)
 - Vector indexed unordered/ordered stores (`vsuxei8`, `vsuxei16`, `vsuxei32`, `vsuxei64`, `vsoxei8`, `vsoxei16`, `vsoxei32`, `vsoxei64`)
 - Vector integer reductions (`vredsum`, `vredmaxu`, `vredmax`, `vredminu`, `vredmin`, `vredand`, `vredor`, `vredxor`, `vwredsumu`, `vwredsum`)
 - Introduce the global hazard table in the main sequencer, to provide up-to-date information to the operand requesters about the status of the different dependant instructions
 - Integer and Floating-Point scalar move instructions (`vmv.x.s`, `vmv.s.x`, `vmv.f.s`, `vmv.s.f`)
 - Add support for `apps` simulation with `spike`
 - Support for vector single-width floating-point reduction instructions: `vfredusum`, `vfredosum`, `vfredmin`, `vfredmax`
 - Support for Vector widening floating-point reductions: `vfwredusum`, `vfwredosum`
 - fdotproduct benchmark to evaluate dot products with reductions
 - fredsum benchmark to evaluate fp-reductions
 - riscv-tests for `vfredusum`, `vfredosum`, `vfredmin`, `vfredmax`, `vfwredusum`, `vfwredosum`
 - Support for vector single-width fractional multiply with rounding and saturation instruction: `vsmul`
 - Support for vector single-width scaling shift instructions: `vssra`, `vssrl`
 - Support for vector narrowing fixed-point clip instructions: `vnclip`, `vnclipu`
 - Vector floating-point classify instruction (`vfclass`)
 - Vector floating-point divide instructions (`vfdiv`, `vfrdiv`)
 - Vector floating-point square-root instruction (`vfsqrt`)
 - Add simple test for source registers reshuffle, when VSEW != EEW_vs
 - Add support for ideal-dispatcher simulation
 - Add compile-time garbage-collection to strip unused functions out and decrease the memory footprint of the binary
 - Add benchmarking capability with the ideal-dispatcher system + performance plotting. The support is limited to simluation with QuestaSim only
 - Plot jacobi2d performance
 - Plot dropout performance
 - Add FFT benchmark and print its performance
 - Add DWT benchmark and print its performance
 - Add fp-exp, fp-cos, fp-log benchmarks from rivec bmark suite + print performance
 - Ideal Dispatcher tracer now supports strided memory operations
 - Add Softmax benchmark and print its performance
 - Add [f]dotproduct apps and benchmarks, and plot their performance
 - Add a specific script to handle [f]dotproduct performance plotting
 - Add a script to benchmark all the applications together locally
 - Add HW cycle counter to better measure runtime cycles with short vectors
 - Add Pathfinder `app` and `benchmark`, and plot its performance
 - Add Roi-Align `app` and `benchmark`, and plot its performance
 - Support for vector mask instructions: `vmsbf`, `vmsof`, `vmsif`, `viota`, `vid`
 - Add support for vector mask population count and find first set bit instructions: `vcpop.m`, `vfirst.m`
 - Add Spyglass linting script
 - Add parametrized support for Fixed-Point math
 - Add optimized ASM version of exp 64-bit
 - Add optimized ASM version of `roi_align`
 - Add support for cache warming before benchmarks
 - Add support to check the results of the ideal dispatcher runs
 - Add HW/SW environment for automatic VCD dumping
 - Support for vector floating-point reciprocal estimate instruction: `vfrec7`
 - Support for vector floating-point reciprocal square-root estimate instruction: `vfrsqrt7`
 - Support for vector narrowing floating-point convert instruction: `vfncvt.rod.f.f`
 - Parametrize `vfrec7`, `vfrsqrt7` and `vfncvt.rod.f.f` support
 - Add guards in the testbench to successfully compile in post-layout simulations
 - Add VCD dumping features to `imatmul`
 - `core_id_i` added to the interface of the system
 - Clock-gate the system bank macros when not used (VRF, D$, I$)
 - Spill register on `sldu` input signals to better isolate the unit
 - Clock-gate the unusued SIMD-int multipliers to save power

### Changed

 - Fixed-Point instructions were added (`VSADDU`, `VSADD`, `VAADD`, `VAADDU`, `VSSUBU`, `VSSUB`, `VASUB`, `VASUBU`)
 - The main sequencer issues instructions every time the target unit has a non-full instruction queue
 - The main sequencer stalls if the instructions target a lane, and its operand requesters are not ready
 - New instructions enter the main sequencer with a token that marks them as new, and the related counter is updated upon arrival
 - Update `README` with instructions on how to compile convolutions
 - Refactor `benchmark` app
 - Double the testbench memory size
 - Update the `python-requirements` list
 - Remove the assign keyword from the always block of masku.sv
 - Update LLVM to version `15.0.0` (RVV 1.0)
 - Update Spike to version `1.1.1-dev` (RVV 1.0)
 - Update `newlib` from commit 84d068 to 5192d5
 - Ara's dispatcher goes to WAIT_STATE only when the new LMUL is lower than the old one
 - Updated target -march to rv64gcv_zfh_zvfh0p1 to enable half-floats support
 - Halve CVA6's L1 caches to ease backend timing closure
 - Remove CVA6's cache patch from `hardware/patches` (CVA6 is now updated)
 - Increase addrgen queue depth to four, to better hide memory latency
 - The RESHUFFLE state is now iterative and reshuffles all the vector registers that need this operation
 - Performance metrics are now calculated by an external performance.py script, instead of during the program simulation, which just prints out the cycle count
 - 7x7 kernel 2dconvs now support arbitrary vector lengths
 - Default con vlen in the config files is now NR_LANES*1024
 - Optimize jacobi2d in ASM, +align store address
 - Replace `apps/common/script/datagen.sh` with new input data source-of-truth (`apps/common/default_arguments.mk`) during app compilation
 - benchmark.sh can now also benchmark just one app at a time via an input argument
 - Adapt `fdotproduct` to `dotproduct` structure
 - Pre-calculate next-cycle `aligned_start_address` in `addrgen` for timing reasons
 - Add `is_reduct` signal to the operand queues, to gate the neutral value filling
 - The hw-counter can be enabled or disabled via software to work also with an environment with cache warming
 - The dropout vectors are now explicitly memory aligned
 - `matmul` generates data offline like all the other benchmarks
 - Refactor `benchmark.sh` script
 - Update `LLVM` to `16`. This brings faster compilations and a prototype of auto-vectorization (disabled by default here!)
 - All the data-gen scripts generate now random data
 - Patch `riscv-tests` `crt0.S` also before compiling `riscv-tests`
 - Almost align all the vector/matrix sizes in `benchmark.sh`
 - Generate data for `fmatmul` at compile time
 - SIMD multipliers are now power gated
 - Roll-back to Verilator v4.214
 - Parametrize `addrgen` queue depth
 - SIMD-multipliers are now gated singularly depending on VSEW
 - Optimize `pathfinder` kernel
 - Optimize `dwt` kernel
 - Optimize `dotproduct` kernel
 - Optimize `fft` kernel
 - Simplify the reduction engine for both `valu` and `vmfpu`, to avoid spurious valid signals to the `sldu`
 - Fix commit for `dtc` installation (`spike` dependency)
 - Simplify the datapath of the slide unit. The `sldu` supports only powers of two, and cannot slide and reshuffle at the same time. Non-power-of-two slides are now handled with micro operations.
 - Bump Verilator to v5.012
 - Only allow one workflow at a time per branch/PR
 - Bump CVA6 version following OpenHW Group's modification
 - Bump fpnew to CVFPU
 - Switch from git submodules to Bender to handle hardware dependencies
 - Bump AXI, tech_cells_generic, and common_cells dependencies

## 2.2.0 - 2021-11-02

### Fixed

- Fix typo on the build instructions of the README
- Fix Gnuplot installation on GitHub's CI
- The number of elements requested by the Store Unit and the Element Requester now depends both on the requested eew and the past `eew` of the vector of the used register
- When the VRF is written and `EMUL > 1`, the `eew` of all the interested registers is updated
- Memory operations can change EMUL when EEW != VSEW
- The LSU now correctly handles bursts with a saturated length of 256 beats
- AXI transactions on an opposite channel w.r.t. the channel currently in use are started only after the completion of the previous transactions
- Fix the number of elements to be requested for a `vslidedown` instruction
- Generate `data.S` files before compiling the programs
- Clean intermediate app object files with `make clean`
- Add a `fence` before stopping the cycle counter, to let the last vector store complete

### Added

- `benchmarks` app to benchmark Ara
- CI task to create roofline plots of `imatmul` and `fmatmul`, available as artifacts
- Vector floating-point compare instructions (`vmfeq`, `vmfne`, `vmflt`, `vmfle`, `vmfgt`, `vmfge`)
- Vector single-width floating-point/integer type-convert instructions (`vfcvt.xu.f`, `vfcvt.x.f`, `vfcvt.rtz.xu.f`, `vfcvt.rtz.x.f`, `vfcvt.f.xu`, `vfcvt.f.x`)
- Vector widening floating-point/integer type-convert instructions (`vfwcvt.xu.f`, `vfwcvt.x.f`, `vfwcvt.rtz.xu.f`, `vfwcvt.rtz.x.f`, `vfwcvt.f.xu`, `vfwcvt.f.x`, `vfwcvt.f.f`)
- Vector narrowing floating-point/integer type-convert instructions (`vfncvt.xu.f`, `vfncvt.x.f`, `vfncvt.rtz.xu.f`, `vfncvt.rtz.x.f`, `vfncvt.f.xu`, `vfncvt.f.x`, `vfncvt.f.f`)
- Vector whole-register move instruction `vmv<nr>`
- Vector whole-register load/store `vl1r`, `vs1r`
- Vector load/store mask `vle1`, `vse1`
- Whole-register instructions are executed also if `vtype.vl == 0`
- Makefile option (`trace=1`) to generate waveform traces when running simulations with Verilator
- Add `fconv3d` kernel, optimized for 7x7 filters
- Optimize `fconv2d` and `iconv2d` kernels for 3x3 filters
- Add convolutions to the `benchmark` app, and print the related roofline plots
- Add corner case test to `vslidedown` instruction

### Changed

- Add spill register at the lane edge, to cut the timing-critical interface between the Mask unit and the VFUs
- Increase latency of the 16-bit multiplier from 0 to 1 to cut an in-lane timing-critical path
- Widen CVA6's cache lines
- Implement back-to-back accelerator instruction issue mechanism on CVA6
- Use https protocol when cloning DTC from main Makefile
- Use https protocol for newlib-cygwin in .gitmodules
- Cut a timing-critical path from Addrgen to Sequencer (1 cycle more to start an AXI transaction)
- Cut a timing-critical path in the `VSTU`, relative to the calculation of the pointer to the `VRF` word received from the lanes
- Create `ara_system` wrapper containing Ara, Ariane, and an AXI mux, instantiated from within Ara's SoC
- Retime address calculation of the `addrgen`
- Push `MASKU` operand muxing from the lanes to the Mask Unit
- Reduce CVA6's default cache size
- Update Verilator to `v4.214`
- Update bender to `v0.23.1`

## 2.1.0 - 2021-07-16

### Fixed

- Fix calculation of `vstu`'s vector length
- Fix `vslideup` and `vslidedown` operand's vector length trimming
- Mute mask requests on idle lanes
- Mute instructions with vector length zero on the respective `lane_sequencer` and `operand_requester`
- Fix `simd_div`'s offset calculation
- Delay acknowledgment of memory requests if the `axi_inval_filter` is busy

### Added

- Format source files in the `apps` folder with clang-format by running `make format`
- Support for the `2_lanes`, `8_lanes`, and `16_lanes` configurations, besides the default `4_lanes` one

### Changed

- Compile Verilator and Ara's verilated model with LLVM, for a faster compile time.
- Verilator updated to version v4.210.
- Verilation is done with a hierarchical verilation flow
- Replace `ara_soc`'s LLC with a simple main memory
- Reduce number of words on the main memory, for faster Verilation
- Update `common_cells` to v1.22.1
- Update `axi` to v0.29.1

## 2.0.0 - 2021-06-24

### Added

- Script to align all the elf sections to the AXI Data Width (the testbench requires it)
- RISC-V V intrinsics can now be compiled
- Add support for `vsetivli`, `vmv<nr>r.v` instructions
- Add support for strided memory operations
- Add support for stores misaligned w.r.t. the AXI Data Width

### Changed

- Alignment with lowRISC's coding guidelines
- Update Ara support for RISC-V V extension to V 0.10, with the exception of the instructions that were already missing
- Replace toolchain from GCC to LLVM when compiling for RISC-V V extension
- Update toolchain and SPIKE support to RISC-V V 0.10
- Patches for GCC and SPIKE are no longer required
- Ara benchmarks are now compatible with RISC-V V 0.10

### Fixed

- Fix `vrf_seq_byte` definition in the Load Unit
- Fix check to discriminate a valid byte in the VRF word, in the Load Unit
- Fix `axi_addrgen_d.len` calculation in the Address Generation Unit
- Correctly check whether the generated address corresponds to the vector load or the store unit
- Typos on the ChangeLog's dates
- Remove unwanted latches in the `addrgen`, `simd_div`, `instr_queue`, and `decoder`
- Fix `vl == 0` memory operations bug. Ara correctly tells Ariane that the memory operation is over

## 1.2.0 - 2021-04-12

### Added

- Hardware support for:
  - Vector slide instructions (vslideup, vslide1up, vfslide1up, vslidedown, vslide1down, vfslide1down)
- Software implementation of a integer 2D convolution kernel
- CI job to check the conv2d execution on Ara

### Fixed

- Removed dependency to a specific gcc g++ version in Makefile
- Arithmetic and memory vector instructions with `vl == 0` are considered as a `NOP`
- Increment bit width of the vector length type (`vlen_t`), accounting for vectors whose length is `VLMAX`
- Fix vector length calculation for the `MaskB` operand, which depends on `vsew`
- Fix typo on the `vrf_pnt` updating logic at the Mask Unit
- Update README to highlight dependency with Spike
- Update Bender's link dependency to the public CVA6 repository
- Retrigger the `compile` module if the ModelSim compilation did not succeed

### Changed

- The `encoding.h` in the common Ara runtime is now a copy from the `encoding.h` in the Spike submodule

## 1.1.1 - 2021-03-25

### Added

- Parametrization for FPU and FPU-specific formats support, through the `FPUSupport` ara_soc parameter

## 1.1.0 - 2021-03-18

### Added

- GitHub Actions-based CI
- Hardware support for:
  - Vector single-width floating-point fused multiply-add instructions (vfnmacc, vfmsac, vfnmsac, vfnmadd, vfmsub, vfnmsub)
  - Vector floating-point sign-injection instructions (vfsgnj, vfsgnjn, vfsgnjx)
  - Vector widening floating-point add/subtract instructions (vfwadd, vfwsub, vfwadd.w, vfwsub.w)
  - Vector widening floating-point multiply instructions (vfwmul)
  - Vector widening floating-point fused multiply-add instructions (vfwmacc, vfwnmacc, vfwmsac, vfwnmsac)
  - Vector floating-point merge instruction (vfmerge)
  - Vector floating-point move instruction (vfmv)

### Changed

- Contributing guidelines updated to include commit message and C++ code style guidelines

## 1.0.0 - 2021-03-10

### Added

- Hardware support for:
  - Vector single-width floating-point add/subtract instructions (vfadd, vfsub, vfrsub)
  - Vector single-width floating-point multiply instructions (vfmul)
  - Vector single-width floating-point fused multiply-add instructions (vfmacc, vfmadd)
  - Vector single-width floating-point min/max instructions (vfmin, vfmax)
- Software implementation of a floating-point matrix multiplication kernel

## 0.6.0 - 2021-02-24

### Added

- Support for a coherent mode between Ara and Ariane
  - Snoop AW channel from Ara to L2
  - Invalidate Ariane's L1 cache sets accordingly
  - Coherent mode can be toggled together with consistent mode using the LSB of CSR 0x702

### Changed

- Ariane's data cache is active by default
- The matrix multiplication kernel achieves better performance
  - It reports the performance and the utilization for several matrix sizes

## 0.5.0 - 2021-02-14

### Added

- Hardware support for:
  - Vector single-width integer divide instructions (vdivu, vdiv, vremu, vrem)
  - Vector integer comparison instructions (vmseq, vmsne, vmsltu, vmslt, vmsleu, vmsle, vmsgtu, vmsgt)
  - Vector carry-out of add-with-carry and subtract-with-borrow instructions (vmadc, vmsbc)
- Runtime measurement functions
- Consistent mode which orders scalar and vector loads/stores.
  - Conservative ordering without address comparison
  - Consistent mode is enabled per default, can be disabled by clearing the LSB of CSR 0x702.

### Fixed

- Ariane's accelerator dispatcher module was rewritten, fixing a bug where instructions would get skipped.
- The Vector Store unit takes the EEW of the source vector register into account to shuffle the elements before writing them to memory.

### Changed

- Vector mask instructions (vmand, vmnand, vmandnot, vmxor, vmor, vmnor, vmornot, vmxnor) no longer require the non-compliant constraint that the vector length is divisible by eight.

## 0.4.0 - 2021-02-04

### Added

- Hardware compilation with Verilator
- Software implementation of a matrix multiplication kernel

### Changed

- The `riscv_tests_simc` Makefile target was deprecated. The riscv-tests are now run with the Verilated design, which can be called through the `riscv_tests_simv` Makefile target.
- The operand queues now take as a parameter the type conversions they support (currently, `SupportIntExt2`, `SupportIntExt4`, and `SupportIntExt8`)
- The Vector Multiplier unit now has independant pipelines for each element width.

## 0.3.0 - 2021-01-28

### Added

- Hardware support for:
  - Vector single-width integer multiply instructions (vmul, vmulh, vmulhu, vmulhsu)
  - Vector single-width integer multiply-add instructions (vmacc, vnmsac, vmadd, vnmsub)
  - Vector integer add-with-carry/subtract-with-borrow instructions (vadc, vsbc)
  - Vector widening integer multiply instructions (vwmul, vwmulu, vwmulsu)
  - Vector widening integer multiply-add instructions (vwmaccu, vwmacc, vwmaccsu, vwmaccus)

### Changed

- Explicit scan chain signals added to the lane's and Ara's interfaces

### Fixed

- Miscellaneous fixes for compatibility with Synopsys DC
- Send the correct bits of the address to the Vector Register File's banks
- Correctly calculate the initial address of each vector register in the VRF

## 0.2.0 - 2021-01-22

### Added

- Hardware support for:
  - Bit-shift instructions (vsll, vsrl, vsra)
  - Vector widening integer add/subtract (vwadd, vwaddu, vwsub, vwsubu)
  - Vector integer extension (vzext, vsext)
  - Vector integer merge and move instructions (vmerge, vmv)
  - Vector narrowing integer right shift instructions (vnsrl, vnsra)

### Changed

- Bender updated to version 0.21.0

### Fixed

- CVA6's forwarding mechanism of operand B for accelerator instructions

## 0.1.0 - 2021-01-06

### Added

- Hardware support for:
  - Vector configuration instructions (vsetvl/vsetvli)
  - Unit-strided vector loads and vector stores
  - Basic arithmetic and logic instructions (vand, vor, vxor, vadd, vsub, vrsub, vmin-u, vmax-u)
  - Predicated instructions through a mask unit
  - Vector mask instructions (vmand, vmnand, vmandnot, vmor, vmnor, vmornot, vmxor, vmxnor)
  - Length multipliers

- Implementation of a synthesizable Ara SoC top-level

- Software support for RISC-V Vector code

- Continuous integration tests through riscv-tests executed both with Spike and on Ara

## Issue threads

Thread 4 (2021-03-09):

Add support for vector floating-point division and square-root instructions

mp-17, 2021-03-09:
Currently, Ara supports the most important FP operations to run a `matmul` kernel.
All the other vector floating-point instructions still need to be added.

Note:
Some of them, namely:
 - `vfclass`
 - `vfdiv`
 - `vfsqrt`

are not implemented due to issues with the FPU (`fpnew`) when operating in vectorial (SIMD) mode. Once these problems are solved, the corresponding instructions will be added as well.

suehtamacv, 2021-03-12:
Is there a corresponding issue in the `fpnew` repo? As far as I know, this is not an issue with Ara, but rather on how the `fpnew` handles the vector execution of those instructions.

mp-17, 2021-03-12:
This is a reference to the synch issue that affects `vfdiv` in `fpnew`: https://github.com/pulp-platform/fpnew/issues/45
We will add the new issue for `vfclass` soon; I have opened an issue here as well just as a reminder, as the implementation of these instructions in Ara is stalled by the issues in `fpnew`

Xavier2979, 2021-05-19:
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

mp-17, 2022-01-19:
Due to a delay in updating the FPU, these instructions were delayed as well. We are merging them now with PR https://github.com/pulp-platform/ara/pull/100.

Closed 2022-09-29.

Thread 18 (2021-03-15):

Multiple operations on the same `vd`, with different `VSEW` and `vl`

mp-17, 2021-03-15:
The following operation does not work on Ara.

> VSET(1, e64, m1);
  VLOAD_64(v1, 0xffffffffffffffff);
  VSET(16, e16, m1);
  VLOAD_16(v2, 0x33ca, ..., 0x314f);
  VLOAD_16(v3, 0x33ca, ..., 0xbb98);
  asm volatile("vmfeq.vv v1, v2, v3");
  VSET(1, e64, m1);
  VCMP_U64(13, v1, 0xffffffffffff0001);

The same register is first loaded with one 64-bit element, and then a 16 bits mask is produced from a `e16` comparison. The final store operation de-shuffles the `VRF` elements as the register hosted `e16` data. The problem is that the mask unit does not store the mask results following a `e16` shuffled pattern, and does not re-shuffle the previously held `e64` element into `e16` elements.

Potentially, the issue is broader:
Ara can have problems with multiple operations on the same register if `VSEW` [and `vl`] are changed, as not all the elements are re-shuffled during the second operation. Part of the old elements remains shuffled in the register (check this, and open another issue if true). If this is the case, when there is a change in `VSEW`, the previously held elements must be re-shuffled with the correct `VSEW`.

suehtamacv, 2021-03-16:
Can you provide a smaller code snippet where this error occurs? The actual assembly code would also help.

This issue could be fixed by making the Mask Unit reorganize all the elements of a vector, up to `vl`, as it is the case with the other functional units.

mp-17, 2021-09-21:
The following example runs smoothly on SPIKE, but it is not correctly handled by Ara.

```
void TEST_CASE5(void) {
  int64_t zero = 0;
  VSET(2, e64, m1);
  VLOAD_64(v0, 0x76543210fedcba98, 0x76543210fedcba98);
  VSET(2, e16, m1);
  asm volatile("vmul.vx v0, v0, %[A]" :: [A] "r"(zero));
  VCMP_U64(13, v0, 0x7654321000000000, 0x76543210fedcba98);
};

```

Closed 2023-11-28.

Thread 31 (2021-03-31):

Correctly load/store (4*NrLanes)-bit unaligned arrays from/to memory

mp-17, 2021-03-31:
The store unit commits an off-by-one error when tries to store arrays that are not 128-bit aligned in memory (128-bit is the AXI data width). For now, benchmarks work on 128-bit aligned data to overcome this issue.

mp-17, 2021-04-16:
With the commits 1f9c2f54f6919e7b532ec2bd380a559aafcd1afc and 7e4c17dfa80d9d9349213abe0f1d320f8598d5e7, the load operations should now work even when starting from memory locations not aligned to `4*NrLanes` Byte.
For the store operations, I do not find an easy fix. The problem arises since the lanes give the data to the store unit in a synchronized fashion, and receive a grant altogether. In the case of an unaligned store, we might need some of the old data from some lanes and new data from the remaining lanes to fill the AXI beat.
The easiest solution I see is that we need to de-synchronize the lanes, having one `stu_operand_ready_o` signal per lane. Every time we use a value, we acknowledge the corresponding unit. The problem is that we need the same also for the mask values; the mask unit should either be able to store some mask values or process them individually.

mp-17, 2021-05-25:
With commit 650ca1f1938e1ce92a3837c8b7d3b0cd6579d90b, the problem should be solved. The effective length of the AXI bus is reduced to accommodate the misalignment, and the effective length must be a divisor of `8*NrLanes`.

suehtamacv, 2021-05-26:
There are a few style issues with that commit, it is not compliant with the code style, but before I do not know where to review it. The Clang PR is not passing, and I am waiting for that to review it. However, the fixes to this issue are attached to that PR.. What should I do?

suehtamacv, 2021-07-15:
Closed since the commit was merged with #40.

Closed 2021-07-15.

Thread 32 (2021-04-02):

Error when compiling hello_world

strongwind312, 2021-04-02:
i'm trying to run make bin/hello_world, but i got the following errors:

make bin/hello_world
/home/workspace/pulp/ara_lenovo_unix/install/riscv-gcc/bin/riscv64-unknown-elf-gcc -mcmodel=medany -march=rv64gcv -mabi=lp64 -I/home/workspace/pulp/ara_lenovo_unix/apps/common -static -std=gnu99 -O3 -ffast-math -fno-common -fno-builtin-printf -DNR_LANES=4 -Wunused-variable -Wall -Wextra  -c hello_world/main.c -o hello_world/main.c.o
/home/workspace/pulp/ara_lenovo_unix/install/riscv-gcc/bin/riscv64-unknown-elf-gcc -mcmodel=medany -march=rv64gcv -mabi=lp64 -I/home/workspace/pulp/ara_lenovo_unix/apps/common -static -std=gnu99 -O3 -ffast-math -fno-common -fno-builtin-printf -DNR_LANES=4 -Wunused-variable -Wall -Wextra  -c common/crt0.S -o common/crt0.S.o
common/encoding.h: Assembler messages:
common/encoding.h:1: Error: unknown pseudo-op: `..'
common/crt0.S:80: Error: illegal operands `li t0,PMP_NAPOT|PMP_R|PMP_W|PMP_X'
common/crt0.S:92: Error: illegal operands `li t0,(1<<CAUSE_LOAD_PAGE_FAULT)|(1<<CAUSE_STORE_PAGE_FAULT)|(1<<CAUSE_FETCH_PAGE_FAULT)|(1<<CAUSE_MISALIGNED_FETCH)|(1<<CAUSE_USER_ECALL)|(1<<CAUSE_BREAKPOINT)'
common/crt0.S:102: Error: illegal operands `li t0,(MSTATUS_FS&(MSTATUS_FS>>1))'
common/crt0.S:106: Error: illegal operands `li t0,(MSTATUS_VS&(MSTATUS_VS>>1))'
/home/workspace/pulp/ara_lenovo_unix/apps/common/runtime.mk:66: recipe for target 'common/crt0.S.o' failed
make: *** [common/crt0.S.o] Error 1
rm hello_world/main.c.o

what could be the reason for this ?

suehtamacv, 2021-04-05:
Hi @strongwind312,

I wonder if you are not missing the `encoding.h` file, which contains the definitions of macros such as `PMP_NAPOT` or `MSTATUS_FS`, and so on. In Ara, this file is available in `apps/common/encoding.h` as a soft-link to the file inside the Spike submodule.

Do you have this `encoding.h` file? Can you read it?

strongwind312, 2021-04-06:
Thank you for your help @suehtamacv
I have encoding.h,
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
and the real file is located in toolchain/riscv-isa-sim/riscv/encoding.h, it contains the required macro definitions.
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

I think the problem may be the relative file path "../../xxx", if i copy toolchain/riscv-isa-sim/riscv/encoding.h to apps/common to replace the original encoding.h, make bin/hello_world can run correctly.

suehtamacv, 2021-04-06:
That is interesting... I cannot reproduce it, but I have no issues in making a copy of `encoding.h` to the `apps/common` folder. I will open a PR to handle that.

suehtamacv, 2021-04-06:
Hi @strongwind312,

I created a new branch, `encoding`, which replaces the softlink by a copy of `encoding.h`. Could you please check whether it solves your issue?

strongwind312, 2021-04-06:
Ok, i will have a try and feed back later. @suehtamacv

strongwind312, 2021-04-08:
Hi, @suehtamacv ,
the encoding branch solved my problem.

Closed 2021-04-08.

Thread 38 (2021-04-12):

Error when nr_lanes changed to 8 and run make verilate

strongwind312, 2021-04-12:
I changed nr_lanes in config/config.mk to 8, but when i ran make verilate, i got the following error :
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
so did the combination of nr_lanes=8 and vlen=4096 tested ? and are there any usable combinations except na_lanes=4 and vlen=4096 ?

suehtamacv, 2021-07-08:
Hi @strongwind312,

Sorry for the delay in tackling this issue. Indeed, Ara has only currently been tested with four lanes. I started adding support for the other configurations. You can track my work on #50.

Matheus

Closed 2021-07-16.

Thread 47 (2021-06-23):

About the difference between annotation and spec 0.9.

Fog-cake, 2021-06-23:
I look at spec0.9, and the description of mapping seems to be a little different from your official one. Specifically when sew = 16 and sew = 8.

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
At the same time, ask a question. After version 1.0, slen was deleted, and mapping was different. This kind of mapping seems to be more complicated.

mp-17, 2021-06-24:
Hello Fog-cake,

You are right; our physical layout is different from the one depicted in the specs (and maybe there is an error in the comment inside `ara_pkg.sv`).
We have a register file that is split into multiple parts, one part per lane. This somehow "mandates" to have subsequent elements separated by one lane each. The internal representation within the 64-bit data width is kept in the way you see just because it is more convenient for operations in which `EEW != SEW` (I actually saw that this could not be the case for FP operations, though).
The important part is that thanks to the shuffling and deshuffling functions, everything should behave as `VLEN == SLEN` from an external point of view (for example, when data loaded in a register is then stored using a store targeting a different SEW), and the execution is predictable and behaves as the elements are physically kept in the VRF respecting the pattern in the specs.
Anyway, this is a nice issue to be raised since a satisfying verification of this behavior (that should be enforced) has not been done yet. In the meantime, if you experience some non-compliant behavior (we can easily verify the correct behavior with SPIKE), please tell us opening a dedicated issue!

Fog-cake, 2021-06-29:
Hi，mp-17,
Thank you for your answers. Yes it is. VLEN=SLEN is currently adopted in the 0.1.0 specification. I see that you have also recently updated to version 0.1.0. If I find a problem that is inconsistent with the specification, I will open a new one. So I will close this issue.

Fog-cake, 2021-06-29:
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

Hi，mp-17,
Thank you for your answers. Yes it is. VLEN=SLEN is currently adopted in the 0.1.0 specification. I see that you have also recently updated to version 0.1.0. If I find a problem that is inconsistent with the specification, I will open a new one. So I will close this issue.

Closed 2021-09-22.

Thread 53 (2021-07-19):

Run xtensor

davidbrochart, 2021-07-19:
[xtensor](https://github.com/xtensor-stack/xtensor) is a C++ library for high-performance ND array computing. Among other things, it implements lazy evaluation, which performs loop fusion and avoids temporaries. So it is well suited to be run on a vector/SIMD CPU such as RISC-V with Vector extension.
[xsimd](https://github.com/xtensor-stack/xsimd) is an abstraction layer around various SIMD architectures (Intel, Arm...), and xtensor supports xsimd to accelerate computations. We would like to support RISC-V Vector extension in xsimd, and ara is one of the only open-source projects that I know of which implements the Vector extension.
Do you think it is ready to be used for that purpose? We will need to evaluate performances, is the RTL model the only cycle-accurate model, or are there higher-level behavioral models?

suehtamacv, 2021-07-20:
Salut David,

Regarding the cycle-accurate models we have available, the RTL is indeed the only one. This being said, we use Verilator, which is reasonably fast for performance measurement. As you can see in Ara's CI, the Verilator model of Ara with four lanes simulates 3k cycles per second. I have a student project for the next semester where we will try to improve this further---we already know that the verilated `lzc` module is particularly slow, for example---but depending on the size of the algorithms you want to benchmark, this might suffice.

Ara does not implement the whole RVV Extension: we lack some hard-to-implement instructions such as reductions and vector register-gather, or even fixed point. But Ara does implement a large part of the specification, as you can see in the `FUNCTIONALITIES.md` file, and we are working on adding the missing instructions. From this point of view, although you might not be able to currently run some benchmarks on Ara, I believe it already supports enough of them to extract some performance results. Reductions are the biggest missing chunk on Ara right now, but @mp-17 is working on that in the [feat.reduction](https://github.com/pulp-platform/ara/tree/feat.reduction) branch.

Ara also currently does not support virtual memory and has an extremely simple runtime. We basically provide a `printf`. From what I saw from `xsimd`, it seems that it can be used in bare-metal mode. Is that correct? If you check our example kernels, you can see that all of our input matrices are [statically allocated](https://github.com/pulp-platform/ara/blob/17c4e28524ce6d805dc07c84aa26ce549cf0c2ce/apps/fmatmul/main.c#L49-L51). There might be work needed there if `xsimd` needs runtime functions that we do not implement, e.g., `malloc`.

Matheus

davidbrochart, 2021-07-20:
Hi Matheus!
Thanks for your answer. Actually xtensor might need to allocate memory for the rare occasions when it needs temporaries, but we could provide custom memory allocators so that memory is eventually statically allocated.
I was also thinking about starting with [Spike](https://github.com/riscv/riscv-isa-sim) only, just to develop the RISC-V target of xsimd, but I guess we won't be able to get any performance metrics out of it.
Anyways, I'll let you know how it goes, thanks again!

Closed 2021-09-30.

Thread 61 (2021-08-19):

Stuck at the complie flow `make riscv_tests_simv`

fantasysee, 2021-08-19:
Hi, @mp-17 @suehtamacv
When I try to `make riscv_tests_simv` according to the README file, my terminal has been stuck with no message update for a long while, about a few hours.

> `(base) ➜  hardware git:(main) ✗ make riscv_tests_simv`
> `build/verilator/Vara_tb_verilator -l ram,/home/fantasysee/Projects/ara/apps/bin/rv64uv-ara-vadd,elf &> build/rv64uv-ara-vadd.trace`
>

And I checked the message in the `build/rv64uv-ara-vadd.trace` file for several times, which is listed as below. It remains the same for a long while as well.

```
Program header number 0 in `/home/fantasysee/Projects/ara/apps/bin/rv64uv-ara-vadd' low is 80000000
Program header number 0 in `/home/fantasysee/Projects/ara/apps/bin/rv64uv-ara-vadd' high is 80004179
Program header number 1 in `/home/fantasysee/Projects/ara/apps/bin/rv64uv-ara-vadd' high is 80004877
Program header number 2 in `/home/fantasysee/Projects/ara/apps/bin/rv64uv-ara-vadd' high is 80004b17
Program header number 3 in `/home/fantasysee/Projects/ara/apps/bin/rv64uv-ara-vadd' is not of type PT_LOAD; ignoring.
Set `ram TOP.ara_tb_verilator.dut.i_ara_soc.i_dram 10 0x80000000 0x80000 write with offset: 0x0 write with size: 0x4b18
Simulation of Ara
=================

Simulation running, end by pressing CTRL-c.

```

Note that, my QuestaSim version is `Mentor Graphics QuestaSim 10.6c` instead of `Mentor Graphics QuestaSim 2020.1`. And I merely make a fake version soft link to `2020.1`, with no modification in the `hardware/Makefile`.

Is this experimental phenomenon normal? If yes, could you please tell me how long this process approximately lasts? If no, would you please help me check if there is something wrong with my experimental environment?

Thanks in advance!!!

suehtamacv, 2021-08-20:
Hi @fantasysee,

That is weird indeed, simulation usually takes no more than 2min. And, as you can see in the CI, we can simulate this `vadd` kernel. How did you compile the binary? Did you compile it with the compiler provided with this repo?

From what you report, I think an exception happened. If the core reaches an illegal exception, it enters a spinlock phase, and does not leave it (we should probably fix this). Can you attach the `vadd` binary you are trying to simulate here?

Matheus

fantasysee, 2021-08-20:
Hi Matheus @suehtamacv,

Thank you very much for your warm reply.

I compile the binary followed the `README.md` **with the compiler provided with this repo**:
1. Build the LLVM toolchain & Spike: `make toolchain-llvm; make riscv-isa-sim`.[The gcc toolchain I also built: `make toolchain-gcc`]
2. Build Verilator: `make verilator`.
3. Build Applications & RISC-V Tests: `cd apps; make bin/hello_world; make riscv_tests;`.
4. Simulate the unit tests:
```
# Go to the hardware folder
cd hardware
# Apply the patches (only need to run this once)
make apply-patches
# Verilate the design
make verilate
# Run the tests
make riscv_tests_simv
```

The links of `rv64uv-ara-vadd` [binary ](https://box.nju.edu.cn/f/c4c20a4335b244f5884f/?dl=1)and its [dump](https://box.nju.edu.cn/f/a40fb81b70374dd18935/?dl=1) are attached here.

Thanks again!!!

Best Regards,
Chao Fang

suehtamacv, 2021-08-23:
Hi Chao,

I just compared your binary with the one I have on my machine, and while there were a few differences in the addresses, they are not significant. I then tried to run a simulation of your binary with a freshly-compiled verilator model, and it worked without issues.

I guess the problem is in your Verilator model, then. Are you sure you are using the version of Verilator version shipped with this repo? (I guess you should, based on your list of commands, but just checking). Did Verilator compile successfully? Did you get any warnings compiling Verilator, or the Verilator model of Ara? Which version of LLVM did you use to compile both of them?

Matheus

fantasysee, 2021-08-24:
Thank you, Matheus.

Based on your helpful advice and the fact that my binary file combined with your freshly-compiled Verilator model worked without issues, I guess there is something mismatched in my hardware toolchain.

I double-checked the version of Verilator and the version of LLVM at first.

The version of compiled Verilator is `v4.211` for the first time, and I found the required version of Verilator is `v4.106` in `DEPENDENCIES.md`. I then modified the `Makefile` and re-compiled Verilator, but also met the same issue. And I also checked the workflow in the CI, I found the Verilator version is `v4.211` as well. Then I think the version of Verilator is acceptable. I am sure that both versions of Verilators have successfully complied without warnings and errors since I checked the [log](https://box.nju.edu.cn/f/9120db843d5b4fbcba31/?dl=1) of `make verilator`.

The LLVM version is `13.0.0`.

However, an error is thrown following the command `make compile`, which compiles the hardware without running the simulation.

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

At the same time, the called Questasim throws an error in its GUI, thereby failing to continue the compile flow.

> **Error (suppressible): (vsim-19) Failed to access library 'work' at "work".**

Finally, I locate my issue on the version of QuestaSim and realize what the problem is.
I compile the ara project on `WSL2`, which is Ubuntu 20.04.1 LTS. However, my Questasim is installed in Windows. It can be searched and called in the WSL2, while it is incompatible with the workflow of ara. At least I observed incompatibility in two ways.  First, the Windows Questasim required `*.dll` instead of `*.so` files to link. Second, the Windows Questasim can't access the path in WSL2-like behavior.

I feel very sorry for the occupation of your valuable time. I think it would be better if I declare the compile environment in advance before I seek help.

I would then try to find a Ubuntu OS machine instead of a virtual machine like `WSL2`, and find a Linux version of QuestaSim to re-compile the ara project. I'll let you know if I make any progress.

I sincerely appreciate your response.

Best Regards,
Chao

fantasysee, 2021-08-25:
Hi, Matheus.

I just succeeded to run the simulation of the RISC-V unit tests, while the simulation unexpectedly stops at the `rv64uv-ara-vnmsac`. It seems that there are no rules to build this instruction. ~~Is this experimental phenomenon correct?~~

I checked `riscv-tests-simv` in the CI at first, and found that it could be simulated normally.

And then I checked the process to build the unit tests for the vector instructions. The command I use to build the riscv_tests is `make -C apps riscv_tests` on the ara project root path.  I found that there is a segmentation fault when building the unit test for the `vmacc` instruction.

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

The LLVM version is `13.0.0`.

What may be the problem to trigger the segmentation fault?

===
The previous issue is indeed triggered by the platform where QuestaSim was installed. And the solution is using a Ubuntu OS and a Linux version QuestaSim.

Your helpful advice and the CI help me a lot. Thank you very much!!!

Regards,
Chao

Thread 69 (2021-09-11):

Make  bin/hello_world failed

zhuxuanlong, 2021-09-11:
Hi,
The ligloss library cannot be found when compiling hello_world.  When I add the tool chain install directory to the path, the same problem still exists.
`
root@zte-R5300-G4-riscv:/share/zhuxuanlong/Vector_Work/ara/apps# make bin/hello_world
chmod +x /share/zhuxuanlong/Vector_Work/ara/apps/common/script/align_sections.sh
rm -f /share/zhuxuanlong/Vector_Work/ara/apps/common/link.ld && cp /share/zhuxuanlong/Vector_Work/ara/apps/common/arch.link.ld /share/zhuxuanlong/Vector_Work/ara/apps/common/link.ld
/share/zhuxuanlong/Vector_Work/ara/apps/common/script/align_sections.sh 4 /share/zhuxuanlong/Vector_Work/ara/apps/common/link.ld
/share/zhuxuanlong/Vector_Work/ara/install/riscv-llvm/bin/clang -march=rv64gcv0p10 -mabi=lp64d -menable-experimental-extensions -mno-relax -fuse-ld=lld -mcmodel=medany -I/share/zhuxuanlong/Vector_Work/ara/apps/common -std=gnu99 -O3 -ffast-math -fno-common -fno-builtin-printf -DNR_LANES=4 -Wunused-variable -Wall -Wextra -Wno-unused-command-line-argument  -c hello_world/main.c -o hello_world/main.c.o
/share/zhuxuanlong/Vector_Work/ara/install/riscv-llvm/bin/clang -march=rv64gcv0p10 -mabi=lp64d -menable-experimental-extensions -mno-relax -fuse-ld=lld -mcmodel=medany -I/share/zhuxuanlong/Vector_Work/ara/apps/common -std=gnu99 -O3 -ffast-math -fno-common -fno-builtin-printf -DNR_LANES=4 -Wunused-variable -Wall -Wextra -Wno-unused-command-line-argument  -c common/crt0.S -o common/crt0-llvm.S.o
/share/zhuxuanlong/Vector_Work/ara/install/riscv-llvm/bin/clang -march=rv64gcv0p10 -mabi=lp64d -menable-experimental-extensions -mno-relax -fuse-ld=lld -mcmodel=medany -I/share/zhuxuanlong/Vector_Work/ara/apps/common -std=gnu99 -O3 -ffast-math -fno-common -fno-builtin-printf -DNR_LANES=4 -Wunused-variable -Wall -Wextra -Wno-unused-command-line-argument  -c common/printf.c -o common/printf-llvm.c.o
/share/zhuxuanlong/Vector_Work/ara/install/riscv-llvm/bin/clang -march=rv64gcv0p10 -mabi=lp64d -menable-experimental-extensions -mno-relax -fuse-ld=lld -mcmodel=medany -I/share/zhuxuanlong/Vector_Work/ara/apps/common -std=gnu99 -O3 -ffast-math -fno-common -fno-builtin-printf -DNR_LANES=4 -Wunused-variable -Wall -Wextra -Wno-unused-command-line-argument  -c common/string.c -o common/string-llvm.c.o
/share/zhuxuanlong/Vector_Work/ara/install/riscv-llvm/bin/clang -march=rv64gcv0p10 -mabi=lp64d -menable-experimental-extensions -mno-relax -fuse-ld=lld -mcmodel=medany -I/share/zhuxuanlong/Vector_Work/ara/apps/common -std=gnu99 -O3 -ffast-math -fno-common -fno-builtin-printf -DNR_LANES=4 -Wunused-variable -Wall -Wextra -Wno-unused-command-line-argument  -c common/serial.c -o common/serial-llvm.c.o
mkdir -p bin/
/share/zhuxuanlong/Vector_Work/ara/install/riscv-llvm/bin/clang -Iinclude -march=rv64gcv0p10 -mabi=lp64d -menable-experimental-extensions -mno-relax -fuse-ld=lld -mcmodel=medany -I/share/zhuxuanlong/Vector_Work/ara/apps/common -std=gnu99 -O3 -ffast-math -fno-common -fno-builtin-printf -DNR_LANES=4 -Wunused-variable -Wall -Wextra -Wno-unused-command-line-argument  -o bin/hello_world hello_world/main.c.o common/crt0-llvm.S.o common/printf-llvm.c.o common/string-llvm.c.o common/serial-llvm.c.o -static -nostartfiles -lm -T/share/zhuxuanlong/Vector_Work/ara/apps/common/link.ld
ld.lld: error: unable to find library -lgloss
clang-13: error: ld command failed with exit code 1 (use -v to see invocation)
make: *** [Makefile:59: bin/hello_world] Error 1
rm hello_world/main.c.o common/string-llvm.c.o common/crt0-llvm.S.o common/printf-llvm.c.o common/serial-llvm.c.o
`

Thank you.

mp-17, 2021-09-21:
Hello zhuxuanlong,

`libgloss` should be in `/share/zhuxuanlong/Vector_Work/ara/install/riscv-llvm/riscv64-unknown-elf/lib`. Can you please report the output of the command:
`ls /share/zhuxuanlong/Vector_Work/ara/install/riscv-llvm/riscv64-unknown-elf/lib`?

If it's not there, something went wrong during the installation of newlib.

Let us know! ;-)
Matteo

zhuxuanlong, 2021-09-22:
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

Hi mp-17,
Thank you for your reply. This file exists.

_root@zte-R5300-G4-riscv:/share/zhuxuanlong/Vector_Work/ara/apps# ls ../install/riscv-llvm/riscv64-unknown-elf/lib/
crt0.o  libc.a  libg.a  libgloss.a  libm.a  libnosys.a  libsemihost.a  libsim.a  nano.specs  nosys.specs  rv64imafdc  semihost.specs  sim.specs_

mp-17, 2021-09-22:
Okay, let's see where the linker searches for the libraries.

Can you please apply this patch to the Makefile in the `apps` directory?

You just need to download [this file](https://github.com/pulp-platform/ara/files/7210058/issue_69_0.txt) in the repository root directory, and then execute from there:

`git apply issue_69_0.txt`

Then, from the `apps` directory, you can try:

`make bin/hello_world | grep "ld.lld"`

Can you please post the output of this command here? We should see now the verbose output of the linker, with the directories that it visit when looking for the libraries.

zhuxuanlong, 2021-09-22:
> make bin/hello_world | grep "ld.lld"

Thank you. The output of the command is as follows:

`root@zte-R5300-G4-riscv:/share/zhuxuanlong/Vector_Work/ara/apps# make bin/hello_world
chmod +x /share/zhuxuanlong/Vector_Work/ara/apps/common/script/align_sections.sh
rm -f /share/zhuxuanlong/Vector_Work/ara/apps/common/link.ld && cp /share/zhuxuanlong/Vector_Work/ara/apps/common/arch.link.ld /share/zhuxuanlong/Vector_Work/ara/apps/common/link.ld
/share/zhuxuanlong/Vector_Work/ara/apps/common/script/align_sections.sh 4 /share/zhuxuanlong/Vector_Work/ara/apps/common/link.ld
/share/zhuxuanlong/Vector_Work/ara/install/riscv-llvm/bin/clang -march=rv64gcv0p10 -mabi=lp64d -menable-experimental-extensions -mno-relax -fuse-ld=lld -mcmodel=medany -I/share/zhuxuanlong/Vector_Work/ara/apps/common -std=gnu99 -O3 -ffast-math -fno-common -fno-builtin-printf -DNR_LANES=4 -Wunused-variable -Wall -Wextra -Wno-unused-command-line-argument  -c hello_world/main.c -o hello_world/main.c.o
/share/zhuxuanlong/Vector_Work/ara/install/riscv-llvm/bin/clang -march=rv64gcv0p10 -mabi=lp64d -menable-experimental-extensions -mno-relax -fuse-ld=lld -mcmodel=medany -I/share/zhuxuanlong/Vector_Work/ara/apps/common -std=gnu99 -O3 -ffast-math -fno-common -fno-builtin-printf -DNR_LANES=4 -Wunused-variable -Wall -Wextra -Wno-unused-command-line-argument  -c common/crt0.S -o common/crt0-llvm.S.o
/share/zhuxuanlong/Vector_Work/ara/install/riscv-llvm/bin/clang -march=rv64gcv0p10 -mabi=lp64d -menable-experimental-extensions -mno-relax -fuse-ld=lld -mcmodel=medany -I/share/zhuxuanlong/Vector_Work/ara/apps/common -std=gnu99 -O3 -ffast-math -fno-common -fno-builtin-printf -DNR_LANES=4 -Wunused-variable -Wall -Wextra -Wno-unused-command-line-argument  -c common/printf.c -o common/printf-llvm.c.o
/share/zhuxuanlong/Vector_Work/ara/install/riscv-llvm/bin/clang -march=rv64gcv0p10 -mabi=lp64d -menable-experimental-extensions -mno-relax -fuse-ld=lld -mcmodel=medany -I/share/zhuxuanlong/Vector_Work/ara/apps/common -std=gnu99 -O3 -ffast-math -fno-common -fno-builtin-printf -DNR_LANES=4 -Wunused-variable -Wall -Wextra -Wno-unused-command-line-argument  -c common/string.c -o common/string-llvm.c.o
/share/zhuxuanlong/Vector_Work/ara/install/riscv-llvm/bin/clang -march=rv64gcv0p10 -mabi=lp64d -menable-experimental-extensions -mno-relax -fuse-ld=lld -mcmodel=medany -I/share/zhuxuanlong/Vector_Work/ara/apps/common -std=gnu99 -O3 -ffast-math -fno-common -fno-builtin-printf -DNR_LANES=4 -Wunused-variable -Wall -Wextra -Wno-unused-command-line-argument  -c common/serial.c -o common/serial-llvm.c.o
mkdir -p bin/
/share/zhuxuanlong/Vector_Work/ara/install/riscv-llvm/bin/clang -Iinclude -march=rv64gcv0p10 -mabi=lp64d -menable-experimental-extensions -mno-relax -fuse-ld=lld -mcmodel=medany -I/share/zhuxuanlong/Vector_Work/ara/apps/common -std=gnu99 -O3 -ffast-math -fno-common -fno-builtin-printf -DNR_LANES=4 -Wunused-variable -Wall -Wextra -Wno-unused-command-line-argument  -o bin/hello_world hello_world/main.c.o common/crt0-llvm.S.o common/printf-llvm.c.o common/string-llvm.c.o common/serial-llvm.c.o -static -nostartfiles -lm -T/share/zhuxuanlong/Vector_Work/ara/apps/common/link.ld -v
clang version 13.0.0 (https://github.com/llvm/llvm-project.git b14c8f5f6eb96e70adb553cc8a4257524881e029)
Target: riscv64-unknown-unknown-elf
Thread model: posix
InstalledDir: /share/zhuxuanlong/Vector_Work/ara/install/riscv-llvm/bin
Found candidate GCC installation: /usr/lib/gcc-cross/riscv64-linux-gnu/9
Selected GCC installation: /usr/lib/gcc-cross/riscv64-linux-gnu/9
 "/share/zhuxuanlong/Vector_Work/ara/install/riscv-llvm/bin/ld.lld" -m elf64lriscv hello_world/main.c.o common/crt0-llvm.S.o common/printf-llvm.c.o common/string-llvm.c.o common/serial-llvm.c.o -lm -L/usr/lib/gcc-cross/riscv64-linux-gnu/9 -L/usr/lib/gcc-cross/riscv64-linux-gnu/9/../../../../riscv64-linux-gnu/lib -T /share/zhuxuanlong/Vector_Work/ara/apps/common/link.ld --start-group -lc -lgloss --end-group -lgcc -o bin/hello_world
ld.lld: error: unable to find library -lgloss
clang-13: error: ld command failed with exit code 1 (use -v to see invocation)
make: *** [Makefile:59: bin/hello_world] Error 1
rm hello_world/main.c.o common/string-llvm.c.o common/crt0-llvm.S.o common/printf-llvm.c.o common/serial-llvm.c.o
`

mp-17, 2021-09-22:
Your LLVM found a candidate RISC-V GCC installation on the system and it is searching for libraries there.
I must change the options we give to LLVM when it is installed to fix this in a more elegant way, but, in the meantime, you can apply another patch to solve the problem.

Revert the patch that you applied before, from the root repository directory:
`git checkout -- apps/Makefile`

Download and apply the [new patch](https://github.com/pulp-platform/ara/files/7211697/issue_69_1.txt):
`git apply issue_69_1.txt`

Then, it should compile smoothly. Let us know!

Best,
Matteo

zhuxuanlong, 2021-09-23:
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

Hi Matteo,
The above solution can solve the helloword compilation error. Thank you again for your support.  In addition, two targets need to be modified in the apps/makefile, such as `bin/$(1)-ara-%` and `bin/$(1)-ara-%.` Otherwise, `make riscv_tests` has the same problem.
After compilation, all executable programs under bin are as follows:
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
mp-17, 2021-09-23:
Perfect, happy that it helped! :-)

Best,
Matteo

Closed 2021-09-23.

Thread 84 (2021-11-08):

ctype.h

forthyen, 2021-11-08:
make bin/hello_world, ctype.h not found ?

suehtamacv, 2021-11-08:
Hi @forthyen

I am not sure, I never heard of this file. Do you have a more detailed log?

Matheus

forthyen, 2021-11-09:
chmod +x /mnt/d/ara/apps/common/script/align_sections.sh
/mnt/d/ara/install/riscv-llvm/bin/clang -march=rv64gcv0p10 -mabi=lp64d -menable-experimental-extensions -mno-relax -fuse-ld=lld -mcmodel=medany -I/mnt/d/ara/apps/common -std=gnu99 -O3 -ffast-math -fno-common -fno-builtin-printf -DNR_LANES=4 -DVLEN=4096 -Wunused-variable -Wall -Wextra -Wno-unused-command-line-argument  -c hello_world/main.c -o hello_world/main.c.o
/mnt/d/ara/install/riscv-llvm/bin/clang -march=rv64gcv0p10 -mabi=lp64d -menable-experimental-extensions -mno-relax -fuse-ld=lld -mcmodel=medany -I/mnt/d/ara/apps/common -std=gnu99 -O3 -ffast-math -fno-common -fno-builtin-printf -DNR_LANES=4 -DVLEN=4096 -Wunused-variable -Wall -Wextra -Wno-unused-command-line-argument  -c common/crt0.S -o common/crt0-llvm.S.o
/mnt/d/ara/install/riscv-llvm/bin/clang -march=rv64gcv0p10 -mabi=lp64d -menable-experimental-extensions -mno-relax -fuse-ld=lld -mcmodel=medany -I/mnt/d/ara/apps/common -std=gnu99 -O3 -ffast-math -fno-common -fno-builtin-printf -DNR_LANES=4 -DVLEN=4096 -Wunused-variable -Wall -Wextra -Wno-unused-command-line-argument  -c common/printf.c -o common/printf-llvm.c.o
/mnt/d/ara/install/riscv-llvm/bin/clang -march=rv64gcv0p10 -mabi=lp64d -menable-experimental-extensions -mno-relax -fuse-ld=lld -mcmodel=medany -I/mnt/d/ara/apps/common -std=gnu99 -O3 -ffast-math -fno-common -fno-builtin-printf -DNR_LANES=4 -DVLEN=4096 -Wunused-variable -Wall -Wextra -Wno-unused-command-line-argument  -c common/string.c -o common/string-llvm.c.o
/mnt/d/ara/install/riscv-llvm/bin/clang -march=rv64gcv0p10 -mabi=lp64d -menable-experimental-extensions -mno-relax -fuse-ld=lld -mcmodel=medany -I/mnt/d/ara/apps/common -std=gnu99 -O3 -ffast-math -fno-common -fno-builtin-printf -DNR_LANES=4 -DVLEN=4096 -Wunused-variable -Wall -Wextra -Wno-unused-command-line-argument  -c common/serial.c -o common/serial-llvm.c.o
rm -f /mnt/d/ara/apps/common/link.ld && cp /mnt/d/ara/apps/common/arch.link.ld /mnt/d/ara/apps/common/link.ld
/mnt/d/ara/apps/common/script/align_sections.sh 4 /mnt/d/ara/apps/common/link.ld
common/string.c:1:10: fatal error: 'ctype.h' file not found
#include <ctype.h>
         ^~~~~~~~~
hello_world/main.c:20:10: fatal error: 'string.h' file not found
#include <string.h>
         ^~~~~~~~~~
1 error generated.
make: *** [/mnt/d/ara/apps/common/runtime.mk:101: common/string-llvm.c.o] Error 1
make: *** Waiting for unfinished jobs....
1 error generated.
make: *** [/mnt/d/ara/apps/common/runtime.mk:107: hello_world/main.c.o] Error 1
rm common/crt0-llvm.S.o common/printf-llvm.c.o common/serial-llvm.c.o

suehtamacv, 2021-11-09:
I think @mp-17 wrote this file. Do you know what is this header?

suehtamacv, 2021-11-09:
This being said, `string.h` is part of the standard C++ library. You should have it. Maybe you need to install some packages in your system?

mp-17, 2021-11-09:
Yes, exactly, it seems more of an environmental problem. Check if the file `/mnt/d/ara/install/riscv-llvm/riscv64-unknown-elf/include/string.h` exists. BTW, do you have the folder `/mnt/d/ara/install/riscv-llvm/riscv64-unknown-elf/include`? If not, maybe `newlib` was not compiled correctly.
Try to check if you can make `toolchain-llvm-newlib` again, and if everything runs smoothly.

forthyen, 2021-11-10:
Thanks. I re-make toolchain-llvm and then I get back one new folder "install/riscv-llvm/riscv64-unknown-elf" !

Closed 2021-11-10.

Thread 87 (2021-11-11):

ara core hangs with 2 lanes and 4 lanes configuration

yanghao, 2021-11-11:
We saw the same program (binary) runs fine on 8 and 16 lanes configuration, however hangs when running on 2 lanes or 4 lanes configuration. From the waveform, when it hangs the PC stopped moving forward. And it is not introduced by any particular vector instruction, it seems to be a mix of scalar and vector instructions that is causing this hang. Tested on latest commits and showing also the same result.

Just wondering if this is a known issue, and do you need a minimum sequence that can reproduce this issue?

suehtamacv, 2021-11-11:
Hi @yanghao,

It is hard to say what is happening. It could be a bug, or it could be an issue with the code you are running. Could you please provide a minimum example?

Matheus

yanghao, 2021-11-11:
@suehtamacv OK, I will try to create a simpler test that can reproduce this. So far it is a big program, but it works fine on spike and ara8/16. The very interesting thing is:

* for VL==128, only ara-2-lanes hang.
* for VL==256, ara-2-lanes and ara-4-lanes hang.

I haven't tried VL > 256 as spike right now only supports 4Kib VLEN (EEW == 16), but seems there is a pattern here, which maybe when VL==512, ara-8-lanes starts to hang and if VL==1024 ara-16-lanes will hang. Will try to provide a simple code, but could take a while to extract the essence of the instruction flow that triggered the issue.

mp-17, 2021-11-11:
Hello @yanghao,

This sounds like a bug to me, but it's hard to tell what's going on under the hood. A minimum example would be perfect and would help a lot!
BTW, if you also want to share the source code and your implementation, we can integrate it into our tests (if it is a program that you want to open-source).

Thanks for reporting the problem,
Matteo

yanghao, 2021-11-12:
https://github.com/pulp-platform/ara/pull/88

Please check the minimal example that reproduce the hang on ara-2-lanes. Hope it helps.

mp-17, 2021-11-12:
Thanks a lot for the example!

It is a problem with the lane sequencer, which does not make the mask unit operand requester fetch enough elements in the case of masked operations. Fewer lanes and more elements highlight the bug, which depends also on your vector element width (indeed, if you use `e64` instead of `e16` it works with 2 lanes as well).
I will have a deeper look and fix it in the next few days and hopefully release a fixed version soon. Unluckily, next week will be busy, but we will patch this as soon as possible.

Best Regards,
Matteo

Closed 2022-02-10.

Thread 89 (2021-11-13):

make toolchain-gcc failed

kaitoukito, 2021-11-13:
I follow the guideline in README, and when I go to step
`make riscv_tests`

it seems that I need to make toolchain-gcc first
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

when I make toolchian-gcc, another problem comes
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

the log shows several similar errors like this "cannot stat 'xxx.gmo': No such file or directory"
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

How should I solve this problem?

suehtamacv, 2021-11-15:
Did you run a `git submodule --update --recursive` before compiling the toolchain? It might be the case that git did not manage to download all submodules correctly. They are pretty large. What is the output of `git status`?

kaitoukito, 2021-11-16:
> Did you run a `git submodule --update --recursive` before compiling the toolchain? It might be the case that git did not manage to download all submodules correctly. They are pretty large. What is the output of `git status`?

Firstly, I used "git submodule --update --recursive". The project is pretty large, and I waited for a whole day and it still hadn't finished. I had to use "ctrl + c" to interrupt the progress, and I restarted it again using "git submodule --update --recursive". After I repeated several times, it finally finished, and the shell didn't return any error message when I did this for the last time.

Now, when I use "git status", it seems I pull this project correctly. However, I'm not sure whether I have pulled this project recursively, as I once interrupted and restarted the command for serveral times.

hellcer, 2022-02-17:
I am facing the same problem. Please fix it or give suggestions.

suehtamacv, 2022-02-17:
`gcc` is a very large submodule, and you need to ensure that it was cloned correctly before compiling it. Check whether the output of `git status` is clean from the `riscv-gcc` folder. Sometimes `git` creates an empty repository when it is not able to clone it correctly.

Unfortunately, there is not much I can do regarding this, the submodule is simply too large.

mahdi259, 2023-10-05:
Have you installed prerequisites of riscv-gnu-toolchain?

$ `sudo apt-get install autoconf automake autotools-dev curl python3 python3-pip libmpc-dev libmpfr-dev libgmp-dev gawk build-essential bison flex texinfo gperf libtool patchutils bc zlib1g-dev libexpat-dev ninja-build git cmake libglib2.0-dev`

(https://github.com/riscv-collab/riscv-gnu-toolchain)

Closed 2022-02-27.

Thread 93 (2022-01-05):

score of dhrystone and coremark

kuopinghsu, 2022-01-05:
This is the score of Dhrystone and Coremark. Is this expected?

DMIPS_Per_MHz: 0.981
CoreMark/MHz: 1.368339

```text
Simulation of Ara
=================

Simulation running, end by pressing CTRL-c.

Dhrystone Benchmark, Version 2.1 (Language: C)

Program compiled without 'register' attribute

Please give the number of runs through the benchmark:
Execution starts, 100 runs through Dhrystone
Execution ends

Final values of the variables used in the benchmark:

Int_Glob:            5
        should be:   5
Bool_Glob:           1
        should be:   1
Ch_1_Glob:           A
        should be:   A
Ch_2_Glob:           B
        should be:   B
Arr_1_Glob[8]:       7
        should be:   7
Arr_2_Glob[8][7]:    110
        should be:   Number_Of_Runs + 10
Ptr_Glob->
  Ptr_Comp:          -2147473472
        should be:   (implementation-dependent)
  Discr:             0
        should be:   0
  Enum_Comp:         2
        should be:   2
  Int_Comp:          17
        should be:   17
  Str_Comp:          DHRYSTONE PROGRAM, SOME STRING
        should be:   DHRYSTONE PROGRAM, SOME STRING
Next_Ptr_Glob->
  Ptr_Comp:          -2147473472
        should be:   (implementation-dependent), same as above
  Discr:             0
        should be:   0
  Enum_Comp:         1
        should be:   1
  Int_Comp:          18
        should be:   18
  Str_Comp:          DHRYSTONE PROGRAM, SOME STRING
        should be:   DHRYSTONE PROGRAM, SOME STRING
Int_1_Loc:           5
        should be:   5
Int_2_Loc:           13
        should be:   13
Int_3_Loc:           7
        should be:   7
Enum_Loc:            1
        should be:   1
Str_1_Loc:           DHRYSTONE PROGRAM, 1'ST STRING
        should be:   DHRYSTONE PROGRAM, 1'ST STRING
Str_2_Loc:           DHRYSTONE PROGRAM, 2'ND STRING
        should be:   DHRYSTONE PROGRAM, 2'ND STRING

Number_Of_Runs: 100
User_Time: 57963 cycles
Dhrystones_Per_Second_Per_MHz: 1725
DMIPS_Per_MHz: 0.981
Microseconds for one run through Dhrystone: 5.796
Dhrystones per Second:                      172523.840

[284890] -Info: ara_tb_verilator.sv:47: Assertion failed in TOP.ara_tb_verilator: Core Test *** SUCCESS *** (tohost = 0)
- /home/kuoping/Projects/ara/hardware/tb/ara_tb_verilator.sv:50: Verilog $finish
Received $finish() from Verilog, shutting down simulation.

Simulation statistics
=====================
Executed cycles:  22c6d
Wallclock time:   38.747 s
Simulation speed: 3676.28 cycles/s (3.67628 kHz)
```

```text
Simulation of Ara
=================

Simulation running, end by pressing CTRL-c.
2K performance run parameters for coremark.
CoreMark Size    : 666
Total ticks      : 3654064
Total time (secs): 0.036541
Iterations/Sec   : 136.833947
Iterations       : 5
Compiler version : GCCClang 13.0.0 (https://github.com/llvm/llvm-project.git b14c8f5f6eb96e70adb553cc8a4257524881e029)
Compiler flags   : -march=rv64gcv0p10 -mabi=lp64d -menable-experimental-extensions -mno-relax -fuse-ld=lld -mcmodel=medany -std=gnu99 -O3 -ffast-math -fno-common -fno-builtin-printf -DNR_LANES=4 -DVLEN=4096 -Wunused-variable -Wall -Wextra -Wno-unused-command-line-argument
Memory location  : STACK
seedcrc          : 0xe9f5
[0]crclist       : 0xe714
[0]crcmatrix     : 0x1fd7
[0]crcstate      : 0x8e3a
[0]crcfinal      : 0xf24c
Correct operation validated. See README.md for run and reporting rules.
CoreMark 1.0 : 136.833947 / GCCClang 13.0.0 (https://github.com/llvm/llvm-project.git b14c8f5f6eb96e70adb553cc8a4257524881e029) -march=rv64gcv0p10 -mabi=lp64d -menable-experimental-extensions -mno-relax -fuse-ld=lld -mcmodel=medany -std=gnu99 -O3 -ffast-math -fno-common -fno-builtin-printf -DNR_LANES=4 -DVLEN=4096 -Wunused-variable -Wall -Wextra -Wno-unused-command-line-argument / STACK
CoreMark/MHz: 1.368339
[7463656] -Info: ara_tb_verilator.sv:47: Assertion failed in TOP.ara_tb_verilator: Core Test *** SUCCESS *** (tohost = 0)
- /home/kuoping/Projects/ara/hardware/tb/ara_tb_verilator.sv:50: Verilog $finish
Received $finish() from Verilog, shutting down simulation.

Simulation statistics
=====================
Executed cycles:  38f174
Wallclock time:   1019.19 s
Simulation speed: 3661.57 cycles/s (3.66157 kHz)
```

kuopinghsu, 2022-01-05:
Software package is at https://github.com/kuopinghsu/ara/tree/main/apps

mp-17, 2022-01-17:
Hi kuopinghsu,

If I see correctly, you have run the standard versions of the programs (they are not vectorized).
Guess that Ara is not used at all, in this case. Have you seen vector instructions while running the programs, or in the disassembly dump?

Best,
Matteo

Closed 2023-11-28.

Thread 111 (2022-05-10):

Hazard with different LMUL

bonewp, 2022-05-10:
I found that only one single vd is marked in write_list in `ara_sequencer`.
However, multiple vd will be written when LMUL > 1.
Consider case as follows:
`vsetvli a0, x0, e32, m8`
`vadd v8, v16, v24`
`vsetvli x0, x0, e32, m1`
`vmul v4, v12, v16`

v8~v15 are written by `vadd`, and the eight VRFs should be marked in write_list/global_hazard_list.
Then `vmul` will stall until v12 is written back.
But it seems not this way in ara_sequencer.

Could you help clarify this issue?
Thanks in advance.

mp-17, 2022-08-02:
Thus far, Ara deals with this by stalling when `LMUL` is changed (`WAIT_STATE` in the `ara_dispatcher`) until all the previous operations are over. In this way, all the operations access a VRF that is always partitioned in the same way, without the risk of hazards.

AD738560581, 2024-03-28:
Hello @mp-17  ，
I found another problem in ara_sequencer. If there is existing an instruction of vmv8r, whcih will write v8~v15. However, there is a vmul instruction which will read v12.  The eight VRFs should be marked in write_list/global_hazard_list. Then vmul will stall until v12 is written back.But it seems not this way in ara_sequencer.
vsetvli a0, x0, e32, m1
vmv8r.v v8, v16
vmul v4, v12, v16

AD738560581, 2024-04-10:
Hello @mp-17 ，
I found another problem in ara_sequencer again. If there is existing a series of instruction which need diferent cycles, like vadd and vrem. However, vrem and vsaddu need read v8 register while vaadd need write v8 register, so there is a hazard of WAR. But, vaadd instruction only find a hazard with vsaddu, while the vsaddu retired, then vaadd will remove hazard. However, vrem is long latency then vsaddu and vrem not read all v8~v15, and vaadd write v8~v16 before vrem, which will lead to a bug.
config: e16, m8, vl=32
vrem.vx v24,v8,gp
vsaddu.vx v16,v8,s11, v0.t
sll a4, a1, 0xb
add a4, a4, -1
vaadd.vx v8, v16, s3

AD738560581, 2024-04-10:
Hello @mp-17 ，
I found another problem in ara_sequencer again. If there is existing a series of instruction which need diferent cycles, like vadd and vrem. However, vrem and vsaddu need read v8 register while vaadd need write v8 register, so there is a hazard of WAR. But, vaadd instruction only find a hazard with vsaddu, while the vsaddu retired, then vaadd will remove hazard. However, vrem is long latency then vsaddu and vrem not read all v8 to v15, and vaadd write v8 to v15 before vrem, which will lead to a bug.
config: e16, m8, vl=32
vrem.vx v24,v8,gp
vsaddu.vx v16,v8,s11, v0.t
sll a4, a1, 0xb
add a4, a4, -1
vaadd.vx v8, v16, s3

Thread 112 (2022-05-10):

bugs from combining indexed load and integer reduction instruction

husterZC, 2022-05-10:
Hi, I find some problem for the new integer reduction instructions
suppose we have the C code below
```
#define SPVV_NONZREO 300
#define SPVV_VLEN 256
int32_t SPVV_idcs32[SPVV_NONZREO] __attribute__((aligned(32), section(".l2")));
int32_t SPVV_vect[SPVV_VLEN] __attribute__((aligned(32), section(".l2")));

int main()
{
        asm volatile("vsetvli zero, %0, e32, m4, ta, ma" ::"r"(256));
        for (int i = 0; i < 100; ++i)
	{
		asm volatile("vle32.v v4, (%0)"::"r"(SPVV_idcs32));//load indices
		asm volatile("vloxei32.v v8, (%0), v4"::"r"(SPVV_vect));//load data
		asm volatile("vredsum.vs v12, v8, v0");
		printf("iteration = %d \n",i);
	}
       return 0;
}
```

This code execute to iteration 3 and stalls there, never stop.
Could you please fix this bug?

mp-17, 2022-05-15:
Thanks a lot for reporting, I will fix it.

kuoyaoming93, 2022-05-26:
Hi @mp-17,
I have the same issue with **vredmin**. The program stalls when I store the result using store instructions (for example, vse64).

I tried it after your last commit regarding this issue 151a85a731039b4385d279fa8928d2c24c0e53ec

```c
#define q_field 16

int main(void)
{
    int64_t min[q_field];
    unsigned long int block_size_p;

    // Vector configuration
    asm volatile("vsetvli %0, %1, e64, m1, ta, ma" : "=r"(block_size_p) : "r"(q_field));
    // Min find
    asm volatile("vmv.v.i v8, 15;");
    asm volatile("vmv.v.i v6, 13;");
    asm volatile("vredmin.vs v10, v8, v6;");
    asm volatile("vse64.v v10, (%0);" ::"r"(min));
    printf("%d\n",min[0]);
}
```

Closed 2022-05-19.

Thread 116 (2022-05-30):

Bugs from integer reduction instructions

kuoyaoming93, 2022-05-30:
Hi, I'm having similar issues as described in #112, and applied the fix #114 to da92dee72b615c95e561b3836012cb27036203a1.

In my case, the program stalls in the first iteration. Suppose the C code below.
Could you please fix this bug? Thanks in advance.

```c
#include <stdint.h>

#include "printf.h"
#include "runtime.h"

#define q_field 16

int64_t wires[q_field][q_field] = {
    {0,1,2,3,4,5,6,7,8,9,10,11,12,13,14,15},
    {1,0,5,9,15,2,11,14,10,3,8,6,13,12,7,4},
    {2,5,0,6,10,1,3,12,15,11,4,9,7,14,13,8},
    {3,9,6,0,7,11,2,4,13,1,12,5,10,8,15,14},
    {4,15,10,7,0,8,12,3,5,14,2,13,6,11,9,1},
    {5,2,1,11,8,0,9,13,4,6,15,3,14,7,12,10},
    {6,11,3,2,12,9,0,10,14,5,7,1,4,15,8,13},
    {7,14,12,4,3,13,10,0,11,15,6,8,2,5,1,9},
    {8,10,15,13,5,4,14,11,0,12,1,7,9,3,6,2},
    {9,3,11,1,14,6,5,15,12,0,13,2,8,10,4,7},
    {10,8,4,12,2,15,7,6,1,13,0,14,3,9,11,5},
    {11,6,9,5,13,3,1,8,7,2,14,0,15,4,10,12},
    {12,13,7,10,6,14,4,2,9,8,3,15,0,1,5,11},
    {13,12,14,8,11,7,15,5,3,10,9,4,1,0,2,6},
    {14,7,13,15,9,12,8,1,6,4,11,10,5,2,0,3},
    {15,4,8,14,1,10,13,9,2,7,5,12,11,6,3,0}
};

int main(void)
{
    int i,j;
    int64_t result[q_field];
    unsigned long int block_size_p;

    // Vector configuration
    asm volatile("vsetvli %0, %1, e64, m1, ta, ma" : "=r"(block_size_p) : "r"(q_field));

    for(i=0; i<q_field;i++){
        asm volatile("vle64.v v0, (%0);" ::"r"(&wires[i][0]));      // Extract rows in v0

        // Min find
        asm volatile("vmv.v.i v2, 15;");
        asm volatile("vredmin.vs v4, v0, v2;");

        // Store result
        asm volatile("vse64.v v4, (%0);" ::"r"(result));

        // Print minimum
        printf("Minimum of row [%d]: %d\n", i, result[0]);
    }
}
```

The output from Verilator 4.214 2021-10-17 rev v4.214:
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

mp-17, 2022-05-30:
Hello @kuoyaoming93,

I will have a look at it, thanks a lot for reporting! :-)

Best,
Matteo

mp-17, 2022-07-09:
Hello Yao-Ming,

It should be fixed with https://github.com/pulp-platform/ara/pull/123.

Best,
Matteo

Closed 2022-08-02.

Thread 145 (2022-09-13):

vfmv.f.s and vmv.x.s are supported?

Gitefu, 2022-09-13:
A simple try-out of vfmv.f.s and vmv.x.s causes the simulation to error out.
Does ara support vfmv.f.s and vmv.x.s?

Thanks.

mp-17, 2022-09-26:
Hello @Gitefu ,

Yes, they should be supported.
Can you please share the program that causes this error?

Best,
Matteo

Gitefu, 2022-10-01:
Hello @mp-17

The following program does not work.
```c
#include <stdint.h>
#include <stdlib.h>
#include <stdio.h>
#include <string.h>
#include <math.h>

#include "printf.h"
#include "runtime.h"

#define N 32
void init_array(float *array, int64_t n){
  for(int i=0; i<n; i++)
    array[i] = i+0.1;
}
int main(){
  /* ---init variable numbers--- */
  float array[N];
  init_array(array,N);
  int64_t n=N;
  float f=0.8;

  printf("before moving:array[0]=%f,f=%f\n",array[0],f);

  /* --- f = array[0] --- */
  asm volatile("vsetvli zero, %0, e32, m1, ta, ma" ::"r"(n));
  printf("\tvsetvli is done.\n");

  asm volatile("vle32.v v1, (%0)" ::"r"(array));
  printf("\tvle32.v is done.\n");

  asm volatile("vfmv.f.s f1, v1"); // error
  printf("\tvfmv.f.s is done.\n");

  asm volatile("fsw f1, (%0)" ::"r"(&f));
  printf("\tfsw.f.s is done.\n");

  /* ----- */
  printf("after moving:array[0]=%f,f=%f\n",array[0],f);
  return 0;
}
```

The result is as follows.
```bash
build/verilator/Vara_tb_verilator  -l ram,/home/gitefu/Documents/gitRepositories/ara/apps/bin/original1,elf
Program header number 0 in `/home/gitefu/Documents/gitRepositories/ara/apps/bin/original1' low is 80000000
Program header number 0 in `/home/gitefu/Documents/gitRepositories/ara/apps/bin/original1' high is 800015d1
Program header number 1 in `/home/gitefu/Documents/gitRepositories/ara/apps/bin/original1' high is 80001ab7
Program header number 2 in `/home/gitefu/Documents/gitRepositories/ara/apps/bin/original1' high is 80001ae7
Program header number 3 in `/home/gitefu/Documents/gitRepositories/ara/apps/bin/original1' is not of type PT_LOAD; ignoring.
Set `ram TOP.ara_tb_verilator.dut.i_ara_soc.i_dram 10 0x80000000 0x80000 write with offset: 0x0 write with size: 0x1ae8
Simulation of Ara
=================

Simulation running, end by pressing CTRL-c.
before moving:array[0]=0.100000,f=0.800000
        vsetvli is done.
        vle32.v is done.
[9632] %Warning: ara_tb_verilator.sv:45: Assertion failed in TOP.ara_tb_verilator: Core Test *** FAILED *** (tohost = 2)
- /home/gitefu/Documents/gitRepositories/ara/hardware/tb/ara_tb_verilator.sv:50: Verilog $finish
Received $finish() from Verilog, shutting down simulation.

Simulation statistics
=====================
Executed cycles:  12d0
Wallclock time:   1.058 s
Simulation speed: 4551.98 cycles/s (4.55198 kHz)
make: *** [Makefile:186: simv] Error 2
```

Gitefu

mp-17, 2022-10-05:
Hello @Gitefu,

I tried the program and it works with both QuestaSim and Verilator (I compiled Ara with 4 Lanes).
I use Verilator `4.214 2021-10-17 rev v4.214`.

To see your version, execute
`./install/verilator/bin/verilator --version`

Is it the same version that I am using? Are you on the main branch, and is it up to date?

Best,
Matteo

giuseppe-chiari, 2022-12-18:
I am experiencing a similar problem with `vmv.x.s`.

I compiled _dotproduct_ for the Ideal Dispatcher with the 8 lanes configuration, specifically:
`make config=8_lanes bin/dotproduct.ideal`

Simulation (on Vivado 2020.2) seems to work until a `VMVXS` instruction is dispatched. At that point simulation stalls indefinitely.
The following is the complete instruction (as per ara_req_o in ara_sequencer.sv) that causes Ara to stall:

`1,VMVXS,1,EW8,VFU_None,0,00,1,OpQueueConversionNone,EW64,10,1,OpQueueConversionNone,EW64,0,EW64,0000002000000000,0,0,0000002000000000,0a,0,LMUL_1,RNE,0,CVT_SAME,0001,0000,'{0,0,0,EW64,LMUL_8},00,00,00,00`

Best regards,
Giuseppe

LeleJun97, 2023-08-25:
I also encountered the same problem as you, the vmv.x.s command couldn't run and got stuck as soon as it was executed.

mp-17, 2023-08-25:
Hello @LeleJun97,

Can you please post a small portion of the code to reproduce the problem?

Thanks,
Matteo

LeleJun97, 2023-08-29:
>
https://github.com/pulp-platform/ara/issues/241#issue-1865247746
I have raised my issue here

978716899, 2023-08-29:
Yes, like you, I also encountered this problem. I wrote the LeNet-5 program in C language, and when gcc -O3 automatic vectorization was enabled, the vmv.x.s instruction would get stuck.

https://github.com/pulp-platform/ara/issues/241#issuecomment-1696689844

mp-17, 2024-08-26:
Let me know if you are still experiencing this after [this fix](https://github.com/pulp-platform/ara/pull/352).

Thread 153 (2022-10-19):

Error in building spike!

StyleDiablo, 2022-10-19:
Hello, I cloned the repository I built the LLVM toolchain no problembt when I attempt to build to bild Spike i Get this error:

**../riscv/interactive.cc: In member function ‘void sim_t::interactive_fregd_all(const string&, const std::vector<std::__cxx11::basic_string<char> >&)’:
../riscv/interactive.cc:639:21: error: ‘class processor_t’ has no member named ‘get_max_xlen’; did you mean ‘get_xlen’?
  639 |   int max_xlen = p->get_max_xlen();
      |                     ^~~~~~~~~~~~
      |                     get_xlen**

How can I fix this?
Thank you.

mp-17, 2022-10-20:
Hello @StyleDiablo,

The released patch had one missing line! Thanks for noticing.
This PR should solve the problem: https://github.com/pulp-platform/ara/pull/154

Let us know,
Matteo

Closed 2022-10-21.

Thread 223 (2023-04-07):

ld.lld: error: unable to find library -lgloss

pigen01, 2023-04-07:
when I tried `make bin/hello_world`
return
```
/home/<user_name>/Documents/ara/install/riscv-llvm/bin/clang -Iinclude -march=rv64gcv_zfh_zvfh0p1 -menable-experimental-extensions -mabi=lp64d -mno-relax -fuse-ld=lld -fno-vectorize -mllvm -scalable-vectorization=off -mllvm -riscv-v-vector-bits-min=0 -Xclang -target-feature -Xclang +no-optimized-zero-stride-load -mcmodel=medany -I/home/<user_name>/Documents/ara/apps/common -std=gnu99 -O3 -ffast-math -fno-common -fno-builtin-printf  -DNR_LANES=4 -DVLEN=4096 -Wunused-variable -Wall -Wextra -Wno-unused-command-line-argument  -ffunction-sections -fdata-sections -o bin/hello_world hello_world/data.S.o hello_world/main.c.o common/crt0-llvm.S.o common/printf-llvm.c.o common/string-llvm.c.o common/serial-llvm.c.o common/util-llvm.c.o -static -nostartfiles -lm -Wl,--gc-sections -T/home/yepeijun/Documents/ara/apps/common/link.ld -v                 clang version 16.0.0 (https://github.com/llvm/llvm-project.git 5047104a76445bb424e480594f0eb2ed768315b3)                                                                                                           Target: riscv64-unknown-unknown-elf                                                                                                                                                                                Thread model: posix
InstalledDir: /home/<user_name>/Documents/ara/install/riscv-llvm/bin
Found candidate GCC installation: /usr/lib/gcc-cross/riscv64-linux-gnu/10
Found candidate GCC installation: /usr/lib/gcc/riscv64-unknown-elf/8.3.0                                                                                                                                           Selected GCC installation: /usr/lib/gcc-cross/riscv64-linux-gnu/10
 "/home/<user_name>/Documents/ara/install/riscv-llvm/bin/ld.lld" -m elf64lriscv -X hello_world/data.S.o hello_world/main.c.o common/crt0-llvm.S.o common/printf-llvm.c.o common/string-llvm.c.o common/serial-llvm.c.o common/util-llvm.c.o -lm --gc-sections -L/usr/lib/gcc-cross/riscv64-linux-gnu/10 -L/usr/lib/gcc-cross/riscv64-linux-gnu/10/../../../../riscv64-linux-gnu/lib -T /home/yepeijun/Documents/ara/apps/common/link.ld --start-group -lc -lgloss --end-group -lgcc -o bin/hello_world
ld.lld: error: unable to find library -lgloss
clang-16: error: ld command failed with exit code 1 (use -v to see invocation)
make: *** [Makefile:105: bin/hello_world] Error 1
```
I also had tried to debug as the closed issue, but it seems not work for me.

I guess this is because the clang find the wrong library (should change `$$RISCV_LDFLAGS_GCC` according to the Makefile) but have no idea how to do that.

mp-17, 2023-04-17:
Hello @pigen01,

Is `/home/<user_name>/Documents/ara/install/riscv-llvm/bin/clang` an existing path? Or maybe `<user_name>` is a mistake?

pigen01, 2023-05-04:
Hello @mp-17

Yes, it is an existing path, but it is not the default path for clang to find riscv-toolchain library,  so I add "-L" option to avoid the wrong linking to another library.

Closed 2023-05-04.

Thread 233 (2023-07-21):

Vivado Synthesis Error

abel-kun, 2023-07-21:
*** Running vivado
    with args -log vlsu.vds -m64 -product Vivado -mode batch -messageDb vivado.pb -notrace -source vlsu.tcl

****** Vivado v2018.1 (64-bit)
  **** SW Build 2188600 on Wed Apr  4 18:40:38 MDT 2018
  **** IP Build 2185939 on Wed Apr  4 20:55:05 MDT 2018
    ** Copyright 1986-2018 Xilinx, Inc. All Rights Reserved.

source vlsu.tcl -notrace
Command: synth_design -top vlsu -part xczu7ev-ffvf1517-1LV-i
Starting synth_design
Attempting to get a license for feature 'Synthesis' and/or device 'xczu7ev'
INFO: [Common 17-349] Got license for feature 'Synthesis' and/or device 'xczu7ev'
INFO: Launching helper process for spawning children vivado processes
INFO: Helper process launched with PID 2008
WARNING: [Synth 8-2490] overwriting previous definition of module fpnew_pkg [D:/ara_modular/lane/ara_lane.srcs/sources_1/imports/src/fpu/src/fpnew_pkg.sv:485]
WARNING: [Synth 8-1921] elaboration system task error violates IEEE 1800 syntax [D:/ara_modular/lane/ara_lane.srcs/sources_1/imports/vlsu/vlsu.sv:242]
WARNING: [Synth 8-1921] elaboration system task error violates IEEE 1800 syntax [D:/ara_modular/lane/ara_lane.srcs/sources_1/imports/vlsu/vlsu.sv:245]
WARNING: [Synth 8-1921] elaboration system task error violates IEEE 1800 syntax [D:/ara_modular/lane/ara_lane.srcs/sources_1/imports/vlsu/vlsu.sv:248]
---------------------------------------------------------------------------------
Starting RTL Elaboration : Time (s): cpu = 00:00:04 ; elapsed = 00:00:04 . Memory (MB): peak = 372.145 ; gain = 113.059
---------------------------------------------------------------------------------
INFO: [Synth 8-6157] synthesizing module 'vlsu' [D:/ara_modular/lane/ara_lane.srcs/sources_1/imports/vlsu/vlsu.sv:11]
	Parameter NrLanes bound to: 32'b00000000000000000000000000000100
	Parameter AxiDataWidth bound to: 32'b00000000000000000000000001000000
	Parameter AxiAddrWidth bound to: 32'b00000000000000000000000001000000
	Parameter DataWidth bound to: 32'b00000000000000000000000001000000
INFO: [Synth 8-6157] synthesizing module 'axi_cut' [D:/ara_modular/lane/ara_lane.srcs/sources_1/imports/src/axi_cut.sv:20]
	Parameter Bypass bound to: 1'b0
INFO: [Synth 8-6157] synthesizing module 'spill_register' [D:/ara_modular/lane/ara_lane.srcs/sources_1/imports/src/spill_register.sv:17]
	Parameter Bypass bound to: 1'b0
INFO: [Synth 8-6157] synthesizing module 'spill_register_flushable' [D:/ara_modular/lane/ara_lane.srcs/sources_1/imports/src/spill_register_flushable.sv:17]
	Parameter Bypass bound to: 1'b0
INFO: [Synth 8-6155] done synthesizing module 'spill_register_flushable' (1#1) [D:/ara_modular/lane/ara_lane.srcs/sources_1/imports/src/spill_register_flushable.sv:17]
INFO: [Synth 8-6155] done synthesizing module 'spill_register' (2#1) [D:/ara_modular/lane/ara_lane.srcs/sources_1/imports/src/spill_register.sv:17]
ERROR: [Synth 8-6038] cannot resolve hierarchical name for the item 'aw_valid' [D:/ara_modular/lane/ara_lane.srcs/sources_1/imports/src/axi_cut.sv:50]
ERROR: [Synth 8-6038] cannot resolve hierarchical name for the item 'aw_ready' [D:/ara_modular/lane/ara_lane.srcs/sources_1/imports/src/axi_cut.sv:51]
ERROR: [Synth 8-6038] cannot resolve hierarchical name for the item 'aw' [D:/ara_modular/lane/ara_lane.srcs/sources_1/imports/src/axi_cut.sv:52]
ERROR: [Synth 8-6038] cannot resolve hierarchical name for the item 'aw_valid' [D:/ara_modular/lane/ara_lane.srcs/sources_1/imports/src/axi_cut.sv:53]
ERROR: [Synth 8-6038] cannot resolve hierarchical name for the item 'aw_ready' [D:/ara_modular/lane/ara_lane.srcs/sources_1/imports/src/axi_cut.sv:54]
ERROR: [Synth 8-6038] cannot resolve hierarchical name for the item 'aw' [D:/ara_modular/lane/ara_lane.srcs/sources_1/imports/src/axi_cut.sv:55]
ERROR: [Synth 8-6156] failed synthesizing module 'axi_cut' [D:/ara_modular/lane/ara_lane.srcs/sources_1/imports/src/axi_cut.sv:20]
ERROR: [Synth 8-6156] failed synthesizing module 'vlsu' [D:/ara_modular/lane/ara_lane.srcs/sources_1/imports/vlsu/vlsu.sv:11]
---------------------------------------------------------------------------------
Finished RTL Elaboration : Time (s): cpu = 00:00:04 ; elapsed = 00:00:04 . Memory (MB): peak = 409.617 ; gain = 150.531
---------------------------------------------------------------------------------
RTL Elaboration failed
INFO: [Common 17-83] Releasing license: Synthesis
8 Infos, 4 Warnings, 0 Critical Warnings and 9 Errors encountered.
synth_design failed
ERROR: [Common 17-69] Command failed: Synthesis failed - please see the console or run log file for details
INFO: [Common 17-206] Exiting Vivado at Fri Jul 21 10:56:12 2023...

I get [Synth 8-6038] cannot resolve hierarchical name for the item 'aw', for every axi related module, while synthesizing on Vivado.
Please help!

AD738560581, 2024-09-04:
Hello, our team is also deploying FPGA for ARA. Have you ever encountered a problem where the always block is too large in decode module and causes a comprehensive abnormal interruption？

fulcrum34, 2024-09-23:
Hello @AD738560581, I was able to synthesize ara_soc.sv completely using VIVADO 2019.1 and generated the bit. I did not see anything relevant to always too big etc. (Which synth tool are you using???)

However I did see an issue relevant to **this issue** (cannot resolve hierarichal name ..........). This issue appears when the top file does not have a struct defined in it. Instead it is inheriting it from its upper module. So make sure you have `ara_soc.sv` as top and it should work.

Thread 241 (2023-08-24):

Maybe the vmv. x.s instruction seems to have problems in certain specific situations

LeleJun97, 2023-08-24:
**My native language is not English, and there may be some issues with my expression. I apologize to you.**
This issue was discovered when I tested the assembly code generated by automatic vectorization using riscv32-unknown-elf-gcc.

Fistly
My C code is as follows：
```
#include <stdio.h>
#include <time.h>
#include <stdlib.h>
#include <stdint.h>

void matrix_mul_vect(uint32_t N, uint32_t *C, uint16_t *A, uint16_t *B) {
	uint32_t i,j;
	for (i=0; i<N; i++) {
		C[i]=0;
		for (j=0; j<N; j++) {
			C[i]+=(uint32_t)A[i*N+j] * (uint32_t)B[j];
		}
	}
}
```

Because I am not proficient in assembly writing, I generate an automatic vectorization "matrix multiplication vector" function written using RISC-V V assembly.

Secondly I use commands
“riscv32-unknown-elf-gcc -S -O3 -march=rv32imacv matrix_mul_vect.c”
to generate. S file:
```
        .file	"matrix_mul_vect.c"
	.option nopic
	.attribute arch, "rv32i2p0_m2p0_a2p0_f2p0_d2p0_c2p0_v1p0_zve32f1p0_zve32x1p0_zve64d1p0_zve64f1p0_zve64x1p0_zvl128b1p0_zvl32b1p0_zvl64b1p0"
	.attribute unaligned_access, 0
	.attribute stack_align, 16
	.text
	.align	1
	.globl	matrix_mul_vect
	.type	matrix_mul_vect, @function
matrix_mul_vect:
	beq	a0,zero,.L1
	slli	t4,a0,2
	csrr	t1,vlenb
	slli	t5,a0,1
	add	t4,a1,t4
	srai	t1,t1,1
	vsetvli	a5,zero,e32,m1,ta,mu
.L4:
	mv	a7,a3
	mv	a6,a2
	mv	a5,a0
	vmv.v.i	v25,0
.L3:
	vsetvli	t3,a5,e32,m1,ta,mu
	vle16.v	v24,(a6)
	vle16.v	v27,(a7)
	vzext.vf2	v26,v24
	vzext.vf2	v24,v27
	vsetvli	a4,zero,e32,m1,ta,mu
	vmul.vv	v24,v24,v26
	vsetvli	zero,a5,e32,m1,tu,mu
	sub	a5,a5,t3
	add	a7,a7,t1
	add	a6,a6,t1
	vadd.vv	v25,v24,v25
	bne	a5,zero,.L3
	vsetvli	a5,zero,e32,m1,ta,mu
	addi	a1,a1,4
	vmv.s.x	v24,zero
	vredsum.vs	v24,v25,v24
	vmv.x.s	a5,v24
	sw	a5,-4(a1)
	add	a2,a2,t5
	bne	a1,t4,.L4
.L1:
	ret
	.size	matrix_mul_vect, .-matrix_mul_vect
	.ident	"GCC: (g) 12.0.1 20220505 (prerelease)"
```

Finally, I put the compiled assembly into the test file.
```
#include <stdint.h>
#include <string.h>
#include "printf.h"
#include "runtime.h"
#include "util.h"

**extern void matrix_mul_vect(uint32_t N, uint32_t *C, uint16_t *A, uint16_t *B);**

void printmat(uint16_t *A, uint32_t N, char *name) {
	uint32_t i,j;
	printf("Matrix %s [%dx%d]:\n",name,N,N);
	for (i=0; i<N; i++) {
		for (j=0; j<N; j++) {
			if (j!=0)
				printf(",");
			printf("%d",A[i*N+j]);
		}
		printf("\n");
	}
}

void printmatC(uint32_t *C, uint32_t N, char *name) {
	uint32_t i,j;
	printf("Matrix %s [%dx%d]:\n",name,N,N);
	for (i=0; i<N; i++) {
		for (j=0; j<N; j++) {
			if (j!=0)
				printf(",");
			printf("%d",C[i*N+j]);
		}
		printf("\n");
	}
}

void printnumb(uint16_t *numb, uint32_t N) {
  uint32_t i;
  for (i = 0; i < N; i++) {
    printf("%d ", numb[i]);
  }
  printf("\n");
}

void printnumbC(uint32_t *numb, uint32_t N) {
  uint32_t i;
  for (i = 0; i < N; i++) {
    printf("%d ", numb[i]);
  }
  printf("\n");
}

void printnumbXC(uint32_t *numb, uint32_t N) {
  uint32_t i;
  for (i = 0; i < N; i++) {
    printf("%x ", numb[i]);
  }
  printf("\n");
}

int main(int argc, char* argv[])
{
	uint16_t x[9][9] = {20,23,29,49,147,237,207,161,163,
						37,39,41,43,45,47,49,51,53,
						55,57,59,61,63,65,67,69,71,
						73,75,77,79,81,83,85,87,89,
						91,93,95,97,99,101,103,105,107,
						109,111,113,115,117,119,121,123,125,
						127,129,131,133,135,137,139,141,143,
						145,147,149,151,153,155,157,159,161,
						163,165,167,169,171,173,175,177,179,
};
	uint16_t y[9] = {2, 4, 9, 28, 125, 726, 5047, 40328, 35209};
	uint32_t z[9];
	printmat(x,9,"X");
	printf("Y\n");
	printnumb(y, 9);
    matrix_mul_vect(9, z,x, y);
	printf("Z\n");
	printnumbC(z,9);
	printf("XZ\n");
	printnumbXC(z,9);
	return 0;
}
```

Normally, it should print out a vector, but it doesn't.
I noticed he got stuck in vmv.x.s.
I also tried a lot of code using automatic vectorization, and they all encountered the same problem as above.

Why???

**Thank you for seeing this. If you could help me solve the problem, that would be even better!**

LeleJun97, 2023-08-25:
I am quite anxious about this issue, and I would greatly appreciate it if you could help me take a look!

978716899, 2023-08-29:
Yes, like you, I also encountered this problem. I wrote the LeNet-5 program in C language, and when gcc -O3 automatic vectorization was enabled, the vmv.x.s instruction would get stuck.
"""
8000063a:	4f01                	li	t5,0
8000063c:	00538cb3          	add	s9,t2,t0
80000640:	000e2b83          	lw	s7,0(t3)
80000644:	01cc8b33          	add	s6,s9,t3
80000648:	88a2                	mv	a7,s0
8000064a:	00fa8eb3          	add	t4,s5,a5
8000064e:	00db0d33          	add	s10,s6,a3
80000652:	c502f057          	vsetivli	zero,5,e32,m1,ta,mu
80000656:	020d6c87          	vle32.v	v25,(s10)
8000065a:	00de8d33          	add	s10,t4,a3
8000065e:	020d6c07          	vle32.v	v24,(s10)
80000662:	05007c57          	vsetvli	s8,zero,e32,m1,ta,mu
80000666:	979c2cd7          	vmul.vv	v25,v25,v24
8000066a:	c102f057          	vsetivli	zero,5,e32,m1,tu,mu
8000066e:	9fa03c57          	vmv1r.v	v24,v26
80000672:	03903c57          	vadd.vi	v24,v25,0
80000676:	01077057          	vsetvli	zero,a4,e32,m1,tu,mu
8000067a:	cf09                	beqz	a4,80000694 <normal_Predict_int+0x13a>
8000067c:	020b6c87          	vle32.v	v25,(s6)
80000680:	020eed87          	vle32.v	v27,(t4)
80000684:	05007c57          	vsetvli	s8,zero,e32,m1,ta,mu
80000688:	979dacd7          	vmul.vv	v25,v25,v27
8000068c:	01077057          	vsetvli	zero,a4,e32,m1,tu,mu
80000690:	039c0c57          	vadd.vv	v24,v25,v24
80000694:	05007c57          	vsetvli	s8,zero,e32,m1,ta,mu
80000698:	0ed1                	addi	t4,t4,20
8000069a:	42006cd7          	vmv.s.x	v25,zero
8000069e:	080b0b13          	addi	s6,s6,128
800006a2:	038cacd7          	vredsum.vs	v25,v24,v25
800006a6:	43902c57          	vmv.x.s	s8,v25
800006aa:	9be2                	add	s7,s7,s8
800006ac:	fbbe91e3          	bne	t4,s11,8000064e <normal_Predict_int+0xf4>
"""

mp-17, 2023-09-06:
Hello, thanks a lot for reporting!
I also had a look at this friendlier example (https://github.com/pulp-platform/ara/issues/246), but I can run it on both Verilator and QuestaSim from the `main` branch.

Can you please provide a similar example that easily reproducible, so that I can fix the bug?

Thank you,
Matteo

mp-17, 2024-08-12:
Let me know if [this](https://github.com/pulp-platform/ara/commit/28b9a3bcb903641727a8f1cc3a081b1c5c9d9de5) fixes the issue!

Closed 2024-08-12.

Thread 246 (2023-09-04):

Issues related to the use of vmv and vredsum.

LeleJun97, 2023-09-04:
Last time I raised this issue, I thought it was a problem with vmv.x.s.
[](https://github.com/pulp-platform/ara/issues/241#issue-1865247746)
However, after careful investigation, I found out that it was not the case. The specific reason is that the ara processor freezes when certain instructions are executed in a particular order.

I extracted the dot product test program from the author and wrote a very simple test case:
```
#include <stdio.h>
#include <time.h>
#include <stdlib.h>
#include <stdint.h>
#include "hbird_sdk_soc.h"

int16_t dotp_v16b(int16_t *a, int16_t *b, uint64_t avl) {
#ifdef INTRINSICS

  size_t orig_avl = avl;
  size_t vl = vsetvl_e16m8(avl);

  vint16m8_t acc, buf_a, buf_b;
  vint16m1_t red;

  int16_t *a_ = (int16_t *)a;
  int16_t *b_ = (int16_t *)b;

  // Clean the accumulator
  red = vmv_s_x_i16m1(red, 0, vl);
  // Stripmine and accumulate a partial reduced vector
  for (; avl > 0; avl -= vl) {
    vl = vsetvl_e16m8(avl);
    // Load chunk a and b
    buf_a = vle16_v_i16m8(a_, vl);
    buf_b = vle16_v_i16m8(b_, vl);
    // Multiply and accumulate
    if (avl == orig_avl) {
      acc = vmul_vv_i16m8(buf_a, buf_b, vl);
    } else {
      acc = vmacc_vv_i16m8(acc, buf_a, buf_b, vl);
    }
    // Bump pointers
    a_ += vl;
    b_ += vl;
  }

  // Reduce and store
  red = vredsum_vs_i16m8_i16m1(red, acc, red, vl);
  return vmv_x_s_i16m1_i16(red);

#else

  size_t orig_avl = avl;
  size_t vl;
  asm volatile("vsetvli %0, %1, e16, m8, ta, ma" : "=r"(vl) : "r"(avl));

  int16_t red;

  int16_t *a_ = (int16_t *)a;
  int16_t *b_ = (int16_t *)b;

  // Clean the accumulator
  asm volatile("vmv.s.x v0, zero");
  // Stripmine and accumulate a partial reduced vector
  for (; avl > 0; avl -= vl) {
    asm volatile("vsetvli %0, %1, e16, m8, ta, ma" : "=r"(vl) : "r"(avl));
    // Load chunk a and b
    asm volatile("vle16.v v8,  (%0)" ::"r"(a_));
    asm volatile("vle16.v v16, (%0)" ::"r"(b_));
    // Multiply and accumulate
    if (avl == orig_avl) {
      asm volatile("vmul.vv v24, v8, v16");
    } else {
      asm volatile("vmacc.vv v24, v8, v16");
    }
    // Bump pointers
    a_ += vl;
    b_ += vl;
  }

  // Reduce and return
  asm volatile("vredsum.vs v0, v24, v0");
  asm volatile("vmv.x.s %0, v0" : "=r"(red));
  return red;

#endif
}

void printnumb(uint16_t *numb, uint32_t N) {
  uint32_t i;
  for (i = 0; i < N; i++) {
    printf("%d ", numb[i]);
  }
  printf("\n");
}

int main(){

	int16_t x[9] = {1, 2, 3, 4, 5, 6, 7, 8, 9};
	int16_t y[9] = {1, 2, 3, 4, 5, 6, 7, 8, 9};
	int16_t zv;
	printf("X\n");
	printnumb(x, 9);
	printf("Y\n");
	printnumb(y, 9);

  zv = dotp_v16b(x, y, 9);
	printf("\n");
	printf("ZV\n");
	printf("%d \n", zv);
        printf("success!\n");
	return 0;
}
```

The meaning of this test case is to compute the dot product of {1, 2, 3, 4, 5, 6, 7, 8, 9}, which should result in 285.
```
X
1 2 3 4 5 6 7 8 9
Y
1 2 3 4 5 6 7 8 9

ZV
285
success!
```

But when I move “asm volatile(“vmv.s.x v0, zero”);” before “asm volatile(“vredsum.vs v0, v24, v0”);” as shown in the following diagram.
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
The result cannot be output when I do that.

Why???

LeleJun97, 2023-09-06:
I tried the given code in the “spike” simulator, and the program ran successfully with correct results. By using “verdi” to trace the signals, I found that there is an issue with the arbitration count in the “operand_requester” module’s “rr_arb_tree”.
A temporary solution now is to replace the instruction “vmv.s.x” with the instruction “vmv.v.i” to avoid the problem.

mp-17, 2023-09-06:
Hello @LeleJun97, I am investigating it right now, thanks for raising the issue!

mp-17, 2023-09-06:
This is weird, I can simulate it successfully with both QuestaSim and Verilator

```c
#include <printf.h>
#include <stdlib.h>
#include <stdint.h>

int16_t dotp_v16b(int16_t *a, int16_t *b, uint64_t avl) {
#ifdef INTRINSICS

  size_t orig_avl = avl;
  size_t vl = vsetvl_e16m8(avl);

  vint16m8_t acc, buf_a, buf_b;
  vint16m1_t red;

  int16_t *a_ = (int16_t *)a;
  int16_t *b_ = (int16_t *)b;

  // Clean the accumulator
  red = vmv_s_x_i16m1(red, 0, vl);
  // Stripmine and accumulate a partial reduced vector
  for (; avl > 0; avl -= vl) {
    vl = vsetvl_e16m8(avl);
    // Load chunk a and b
    buf_a = vle16_v_i16m8(a_, vl);
    buf_b = vle16_v_i16m8(b_, vl);
    // Multiply and accumulate
    if (avl == orig_avl) {
      acc = vmul_vv_i16m8(buf_a, buf_b, vl);
    } else {
      acc = vmacc_vv_i16m8(acc, buf_a, buf_b, vl);
    }
    // Bump pointers
    a_ += vl;
    b_ += vl;
  }

  // Reduce and store
  red = vredsum_vs_i16m8_i16m1(red, acc, red, vl);
  return vmv_x_s_i16m1_i16(red);

#else

  size_t orig_avl = avl;
  size_t vl;
  asm volatile("vsetvli %0, %1, e16, m8, ta, ma" : "=r"(vl) : "r"(avl));

  int16_t red;

  int16_t *a_ = (int16_t *)a;
  int16_t *b_ = (int16_t *)b;

  // Clean the accumulator
//  asm volatile("vmv.s.x v0, zero");
  // Stripmine and accumulate a partial reduced vector
  for (; avl > 0; avl -= vl) {
    asm volatile("vsetvli %0, %1, e16, m8, ta, ma" : "=r"(vl) : "r"(avl));
    // Load chunk a and b
    asm volatile("vle16.v v8,  (%0)" ::"r"(a_));
    asm volatile("vle16.v v16, (%0)" ::"r"(b_));
    // Multiply and accumulate
    if (avl == orig_avl) {
      asm volatile("vmul.vv v24, v8, v16");
    } else {
      asm volatile("vmacc.vv v24, v8, v16");
    }
    // Bump pointers
    a_ += vl;
    b_ += vl;
  }

  // Reduce and return
  asm volatile("vmv.s.x v0, zero");
  asm volatile("vredsum.vs v0, v24, v0");
  asm volatile("vmv.x.s %0, v0" : "=r"(red));
  return red;

#endif
}

void printnumb(uint16_t *numb, uint32_t N) {
  uint32_t i;
  for (i = 0; i < N; i++) {
    printf("%d ", numb[i]);
  }
  printf("\n");
}

int main(){

	int16_t x[9] = {1, 2, 3, 4, 5, 6, 7, 8, 9};
	int16_t y[9] = {1, 2, 3, 4, 5, 6, 7, 8, 9};
	int16_t zv;
	printf("X\n");
	printnumb(x, 9);
	printf("Y\n");
	printnumb(y, 9);

	zv = dotp_v16b(x, y, 9);
	printf("\n");
	printf("ZV\n");
	printf("%d \n", zv);
	printf("success!\n");
	return 0;
}
```

mp-17, 2024-08-12:
Let me know if [this](https://github.com/pulp-platform/ara/commit/28b9a3bcb903641727a8f1cc3a081b1c5c9d9de5) fixes the issue!

Closed 2024-08-12.

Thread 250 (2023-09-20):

a bunch of hangs and crashes

camel-cdr, 2023-09-20:
I noticed that a bunch of the programs (benchmarks) I want to execute on ara start hanging at some point, but since that isn't that reproducible, I've tried to find some short examples that are definitely broken.

My approach to finding the bugs below was to shuffle a [list of all instructions](https://github.com/pulp-platform/ara/files/12677616/instructions.txt), see if it breaks, and try to minimize the code while keeping the breakage. This sound time-consuming, but it wasn't because it almost always started hanging with just a few instructions.

I'm using the llvm toolchain, added the implemented foo in a new file asm.S and modified the hello_world main to the following:

```c
int main(void) {
        extern void foo(void);
        printf("BEGIN\n");
        foo();
        printf("END\n");
        return 0;
}
```

### Hangs

```asm
.text
.global foo
foo:
    vsetvli t0, x0, e32, m1, ta, ma
    vfirst.m t0,v8,v0.t
    ret
```

```asm
foo:
        vsetvli t0, x0, e32, m1, ta, ma
        vmseq.vi v8,v16,13
        vcpop.m t0,v8,v0.t
        ret
```

```asm
foo:
        vsetvli t0, x0, e32, m1, ta, ma
        vredmax.vs v8,v16,v24,v0.t
        vslidedown.vx v8,v16,t0,v0.t
        vmv.v.v v8,v16
        ret
```

```asm
foo:
        vsetvli t0, x0, e32, m1, ta, ma
        vredor.vs v8,v16,v24
        vslidedown.vi v8,v16,3
        vmxnor.mm v0,v8,v16
        ret
```

```asm
foo:
        vsetvli t0, x0, e32, m1, ta, ma
        vid.v v0
        vid.v v8
        vid.v v16
        vid.v v24
        vadd.vv v0, v8, v16 # these can be almost any two instructions
        vsub.vv v0, v8, v16 # and it will also hang, e.g: vsub&vmul,vmseq&vxor, ...
        ret
```

```asm
foo:
        vsetvli t0, x0, e32, m1, ta, ma
        vrsub.vx v8,v16,t0
        vmsbf.m v8,v16
        vsrl.vi v8,v16,13,v0.t
        vslideup.vi v8,v16,3,v0.t
        vsbc.vvm v8,v16,v24,v0
        ret
```

### Crashes

```asm
foo:
        vsetvli t0, x0, e16, m8, ta, ma
        vid.v v0
        ret
```

## Full Reproduction

```Docker
FROM ubuntu:22.04

RUN apt-get update \
	&& apt-get install -y build-essential wget git unzip python3 verilator make cmake zstd python3 ninja-build texi2html \
	texinfo device-tree-compiler autoconf autotools-dev curl lsb-release clang flex libfl-dev libelf-dev bison libmpc-dev htop  \
	help2man vim \
	&& apt-get clean \
	&& rm -rf /var/lib/apt/lists/*

RUN git clone https://github.com/pulp-platform/ara/

WORKDIR ara

COPY main.c apps/vfmv_test/main.c

RUN git submodule update --init --recursive

RUN make toolchain-llvm
RUN make riscv-isa-sim
RUN make verilator

RUN /usr/bin/install -c /ara/install/verilator/bin/verilator_bin /ara/install/verilator/share/verilator/

RUN make -C hardware apply-patches && make -C hardware verilate

```

```bash
$ # modify apps/hello_world/main.c and  apps/hello_world/asm.S
$ make bin/hello_world && app=hello_world make -C ../hardware/ simv
```

Note: I haven't looked at floating point, widening and narrowing instructions yet.

I also ran the built-in tests and `rv64uv-ara-vl_nocheck` hangs, and `rv64uv-ara-vssub` fails.

PS: Is there a kinda stable version of ara with rvv 1.0 or 0.7.1 support, I can run my benchmarks on for now?

mp-17, 2023-11-15:
Hi @camel-cdr, thanks a lot for reporting. We really need to integrate random sequence generation tests in our verification flow since, thus far, we only used hand-assembled tests and vectorized benchmarks that do not expose more exotic patterns.
The repo has been silent for a while because of internal exploration and evaluation, I will get back to this asap :-)

mp-17, 2023-12-08:
Hello @quswarabid, thank you very much; that would be fantastic! If you want and have time, we can schedule a meeting and discuss it.

mp-17, 2023-12-08:
Thank you, @quswarabid, waiting for it! Have a great weekend too! :-)

mp-17, 2024-06-27:
Hey @camel-cdr,

I am now dedicating some time every week to verification and bug fixes.
This branch should solve all the hangs/crashes you posted:
https://github.com/pulp-platform/ara/tree/mperotti/debug

I want to start solving all the bugs highlighted in the repo `Issues`. If you like, we can also have a call and discuss the problems you encountered. I see you have a repo with benchmarks https://github.com/camel-cdr/rvv-bench; I have not tried them yet, but I guess you have met problems running them.
Let me know!

camel-cdr, 2024-06-27:
Hi @mp-17,
thats great to hear. Yes, I run into problems trying my benchmark, and created the small script so I can share reproducible bugs. (The credit in the header is enough :+1:)

I haven't tested on ara for some time now, just followed the commits, but I'll look into it again after I'm back from the rv summit.

Closed 2025-01-20.

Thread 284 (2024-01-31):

AXI handshaking logic within the vstu and addrgen violates AXI Specification

T-Szymk, 2024-01-31:
Within the AXI Specification (ARM IHI 0022 Issue K) it states : "A source is not permitted to wait until READY is asserted before asserting VALID."

However on [addrgen.sv line 558](https://github.com/pulp-platform/ara/blob/ec0e37916b901961beab3974acc44ab5ea422db6/hardware/src/vlsu/addrgen.sv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) there is a conditional statement which uses the "axi_ax_ready" signal to determine whether the axi_ar/aw_valid_o signals are set on the interface.

"axi_ax_ready" is combinatorially set using the AXI addr ready signals on [line 546](https://github.com/pulp-platform/ara/blob/ec0e37916b901961beab3974acc44ab5ea422db6/hardware/src/vlsu/addrgen.sv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).

There is similar logic within [vlstu.sv line  207](https://github.com/pulp-platform/ara/blob/ec0e37916b901961beab3974acc44ab5ea422db6/hardware/src/vlsu/vstu.sv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).

mp-17, 2024-02-26:
Hello @T-Szymk,

You are right; thanks for pointing this out.
Fixing this in https://github.com/pulp-platform/ara/pull/287/files?diff=unified&w=1

T-Szymk, 2024-02-26:
Hi,

Thanks for responding and looking into that! I didn't experience any problems per se, I was just learning how everything was implemented (as I am using the design in project) and I just happened to notice that the read/valid behaviour seemed strange in the waveform. I should have looked more closely because as you say, there is the cut splitting the comb path from the external interface. Sorry about that!

I am happy for you to close this issue.

Closed 2024-02-26.

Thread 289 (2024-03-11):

About Mutilple Vector Core Setup

Rarity0123, 2024-03-11:
Hi All,
I'm studying the paper of your team "Ara2: Exploring Single- and Multi-Core Vector Processing with an Efficient RVV1.0 Compliant Open-Source Processor" and try to simulate.  However, I only found the setup of single core.  Do you have open source the muti core setup for Apps and Hardware Code?  Thanks!

AD738560581, 2024-03-12:
Hello，I also want to studying the paper of "Ara2: Exploring Single- and Multi-Core Vector Processing with an Efficient RVV1.0 Compliant Open-Source Processor". But I do not found it in the Internet, could you give the way how can i find it?

csgxiong, 2024-03-12:
I am also very interested about this project.
Anyone know about this ?
Thanks!!

@mp-17 @suehtamacv

mp-17, 2024-03-12:
Hello @Rarity0123  and @csgxiong,

Even if we developed it more internally, this is one of the development branches we used and should be a good starting point: https://github.com/pulp-platform/ara/commits/feat/multi-core/

Let me know!
Best,
Matteo

csgxiong, 2024-03-12:
Thank you for your reply. I will check the multi-core branch and wish to learn something from it.
So, here is another question:
when will your team merge the ara2 branch or the multi-core branch to main?
Or what is your plan to release a stable edition about ara2?

Best Regards

mp-17, 2024-03-12:
Hey @csgxiong,

We are still slowly finishing the cleanup of some of the last features we developed internally, like `vrgather/vcompress` and the segment memory operations (which are the missing features to have the "full" Ara2. The rest, which accounts for 99% of the paper material, should be already merged).
In the meantime, we are also going on with the architecture development in internal branches, with various explorations that will lead to the next PRs, while merging the multi-core support into `main` is currently not a priority.

Best,
Matteo

csgxiong, 2024-03-12:
@mp-17
Thank you, Matteo. Now I get it.
I think this project is a good example for learning RISC-V Vector.
And thank you and your team.
I will keep following this project！

mp-17, 2024-03-12:
That is great news. Let me know if you need help with anything! :-)

AdhamRagab25, 2024-03-13:
Hello @mp-17;

Thanks for your quick responses above! I am also interested in testing some of the multi-core setup in your project, and was curious about your preferred methods for simulation. For context, I was previously experimenting on the main branch prior to discovering the paper, and subsequently the branch and this issue. I have been using Verilator almost exclusively due to some Questa/ModelSim setup issues on my end. I'm curious if you used Verilator at all to simulate some multi-core setups, or if you tended to favour Questa/ModelSim. For the later, considering it can quite exciting to observe how it works, I might consider taking some time to fix my Questa/ModelSim issues. However, if you did use Verilator, I am curious in how you got it to simulate, as I am running into issues trying to use it.

Thanks in advance!

Closed 2024-03-12.

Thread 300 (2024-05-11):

Unclear failure to make toolchain-gcc

magurmach, 2024-05-11:
My attempts to `make toolchain-gcc` failing with the following unclear messeage:

```
/usr/bin/install -c -m 644 b-header-vars /home/sshakib/riscv/ara/install/riscv-gcc/lib/gcc/riscv64-unknown-elf/9.2.0/plugin/include/b-header-vars
make[3]: Leaving directory '/home/sshakib/riscv/ara/toolchain/riscv-gnu-toolchain/build/build-gcc-newlib-stage1/gcc'
make[2]: Leaving directory '/home/sshakib/riscv/ara/toolchain/riscv-gnu-toolchain/build/build-gcc-newlib-stage1'
mkdir -p stamps/ && touch stamps/build-gcc-newlib-stage1
make[1]: Leaving directory '/home/sshakib/riscv/ara/toolchain/riscv-gnu-toolchain/build'
make: *** [Makefile:66: toolchain-gcc] Error 2
```

I am attempting to install toolchain-gcc because `riscv_tests` was failing for missing riscv-gcc specific installations.

When I try riscv_tests now, I get the following:

```
sshakib@pop-os:~/riscv/ara$ make riscv_tests
make -C apps -j4 riscv_tests && \
make -C hardware riscv_tests_simc
make[1]: Entering directory '/home/sshakib/riscv/ara/apps'
chmod +x /home/sshakib/riscv/ara/apps/common/script/align_sections.sh
/home/sshakib/riscv/ara/install/riscv-gcc/bin/riscv64-unknown-elf-gcc -mcmodel=medany -march=rv64gcv -mabi=lp64d -I/home/sshakib/riscv/ara/apps/common -static -std=gnu99 -O3 -ffast-math -fno-common -fno-builtin-printf  -DNR_LANES=4 -DVLEN=4096 -Wunused-variable -Wall -Wextra -Wno-unused-command-line-argument  -c common/crt0.S -o common/crt0-gcc.S.o
/home/sshakib/riscv/ara/install/riscv-gcc/bin/riscv64-unknown-elf-gcc -mcmodel=medany -march=rv64gcv -mabi=lp64d -I/home/sshakib/riscv/ara/apps/common -static -std=gnu99 -O3 -ffast-math -fno-common -fno-builtin-printf  -DNR_LANES=4 -DVLEN=4096 -Wunused-variable -Wall -Wextra -Wno-unused-command-line-argument  -c common/printf.c -o common/printf-gcc.c.o
/home/sshakib/riscv/ara/install/riscv-gcc/bin/riscv64-unknown-elf-gcc -mcmodel=medany -march=rv64gcv -mabi=lp64d -I/home/sshakib/riscv/ara/apps/common -static -std=gnu99 -O3 -ffast-math -fno-common -fno-builtin-printf  -DNR_LANES=4 -DVLEN=4096 -Wunused-variable -Wall -Wextra -Wno-unused-command-line-argument  -c common/string.c -o common/string-gcc.c.o
rm -f /home/sshakib/riscv/ara/apps/common/link.ld && cp /home/sshakib/riscv/ara/apps/common/arch.link.ld /home/sshakib/riscv/ara/apps/common/link.ld
/home/sshakib/riscv/ara/apps/common/script/align_sections.sh 4 /home/sshakib/riscv/ara/apps/common/link.ld
common/string.c:1:10: fatal error: ctype.h: No such file or directory
    1 | #include <ctype.h>
      |          ^~~~~~~~~
compilation terminated.
In file included from common/printf.c:34:
/home/sshakib/riscv/ara/install/riscv-gcc/lib/gcc/riscv64-unknown-elf/9.2.0/include/stdint.h:9:16: fatal error: stdint.h: No such file or directory
    9 | # include_next <stdint.h>
      |                ^~~~~~~~~~
compilation terminated.
/home/sshakib/riscv/ara/install/riscv-gcc/bin/riscv64-unknown-elf-gcc -mcmodel=medany -march=rv64gcv -mabi=lp64d -I/home/sshakib/riscv/ara/apps/common -static -std=gnu99 -O3 -ffast-math -fno-common -fno-builtin-printf  -DNR_LANES=4 -DVLEN=4096 -Wunused-variable -Wall -Wextra -Wno-unused-command-line-argument  -c common/serial.c -o common/serial-gcc.c.o
In file included from common/serial.c:1:
/home/sshakib/riscv/ara/install/riscv-gcc/lib/gcc/riscv64-unknown-elf/9.2.0/include/stdint.h:9:16: fatal error: stdint.h: No such file or directory
    9 | # include_next <stdint.h>
      |                ^~~~~~~~~~
compilation terminated.
make[1]: *** [/home/sshakib/riscv/ara/apps/common/runtime.mk:120: common/string-gcc.c.o] Error 1
make[1]: *** Waiting for unfinished jobs....
make[1]: *** [/home/sshakib/riscv/ara/apps/common/runtime.mk:120: common/serial-gcc.c.o] Error 1
make[1]: *** [/home/sshakib/riscv/ara/apps/common/runtime.mk:120: common/printf-gcc.c.o] Error 1
rm common/crt0-gcc.S.o
make[1]: Leaving directory '/home/sshakib/riscv/ara/apps'
make: *** [Makefile:174: riscv_tests] Error 2
```

If I understand correctly, it's failure due to missing header libraries. Any advice?

mp-17, 2024-05-15:
Hello Shakib,
I think so. The GCC toolchain installation errored out, but it is not clear what happened. Do you have a verbose log of the installation or a hint about the error that occurred at installation time?

magurmach, 2024-05-17:
Hi,

Here is the following error I am getting with `make VERBOSE=1 toolchain-gcc`:

```
/usr/bin/install -c -m 644 ../../../riscv-gcc/gcc/xcoffout.h /home/sshakib/riscv/ara/install/riscv-gcc/lib/gcc/riscv64-unknown-elf/9.2.0/plugin/include/xcoffout.h
/usr/bin/install -c -m 644 b-header-vars /home/sshakib/riscv/ara/install/riscv-gcc/lib/gcc/riscv64-unknown-elf/9.2.0/plugin/include/b-header-vars
make[3]: Leaving directory '/home/sshakib/riscv/ara/toolchain/riscv-gnu-toolchain/build/build-gcc-newlib-stage1/gcc'
make[2]: Leaving directory '/home/sshakib/riscv/ara/toolchain/riscv-gnu-toolchain/build/build-gcc-newlib-stage1'
mkdir -p stamps/ && touch stamps/build-gcc-newlib-stage1
make[1]: Leaving directory '/home/sshakib/riscv/ara/toolchain/riscv-gnu-toolchain/build'
make: *** [Makefile:66: toolchain-gcc] Error 2
```

I am unclear why this is happening or what specifically is the error source.

mp-17, 2024-05-17:
Maybe the error is raised by one of the four jobs on which `make` runs.

You can modify here:
https://github.com/pulp-platform/ara/blob/main/Makefile#L68C6-L68C21

```diff
- 	$(MAKE) MAKEINFO=true -j4
+ 	$(MAKE) MAKEINFO=true -j1
```

This should serialize the build so that the error will be hopefully printed closer to when `make` errors out.

magurmach, 2024-05-17:
It was due to missing library.

Fixed by:

```
sudo apt-get install linux-headers-$(uname -r)
```

Closed 2024-05-17.

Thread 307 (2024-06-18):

invalid arch name error

sheikhfaizanqureshi, 2024-06-18:
After working with v2.2.0 for a while I updated my project repository to v3.0.0. On compiling benchmarks in apps I receive this error: lang-13: error: invalid arch name 'rv64gcv_zfh_zvfh0p1', experimental extension requires explicit version number 'v. (also see attachment)
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

Tried many different architecture names/versions but no success.

mp-17, 2024-06-25:
Hello @sheikhfaizanqureshi, have you also re-installed the toolchains? You need an updated LLVM to be compatible with the new options (try to re-install the toolchain following the readme).

Closed 2024-06-27.

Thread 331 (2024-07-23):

uint64_t

grigohas, 2024-07-23:
Hello, i do make riscv-isa-sim but i get an error for the uint64_t of the device.h file and i checked that there isn't the cstdint library defined but when i add it and do make again , the device.h file is regenerated without the cstdint header. How can i solve this error?

egor-achkasov, 2024-07-26:
Could you try downgrading gcc to the version 12 and running the build again? My guess us that the issue is due to a reduced usage of several headers (including cstdint that defines uint64_t) in the gcc implementation.

grigohas, 2024-07-27:
it worked thanks

Closed 2024-07-27.

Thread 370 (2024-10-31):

Vector mask instructions VMSBF, VMSIF and VMSOF encountered errors during simulation

0rd1narY1, 2024-10-31:
Hi!
I tried simulating VMSBF, VMSIF and VMSOF instructions with self-added testcases  consistent with the examples in the RVV1.0 spec. Then I met errors in the RTL simulation. However, I passed the simulations using Spike.
### The example in the RVV1.0 spec
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
where v3 contents are masked by v0, and then the result is written in v2.
### Testcase
```C
void TEST_CASE3() {
  VSET(8, e8, m1);
  VLOAD_8(v3, 0x94, 0, 0, 0, 0, 0, 0, 0);
  VLOAD_8(v0, 0xC3, 0, 0, 0, 0, 0, 0, 0);
  VCLEAR(v2);
  __asm__ volatile("vmsbf.m v2, v3, v0.t");
  VCMP_U8(3, v2, 0x43, 0, 0, 0, 0, 0, 0, 0);
}
```
The testcase is the same as what is in the manual. The expected result is 01000011.
### Simulations
Spike simulation  passed successfully.
```
spike --isa=rv64gcv_zfh --varch="vlen:4096,elen:64" rv64uv-p-vmsbf 2> rv64uv-p-vmsbf.cout
Checking the results of the test case 1:
PASSED.
Checking the results of the test case 2:
PASSED.
Checking the results of the test case 3:
PASSED.
PASSED: rv64uv/vmsbf.c!
```
But RTL simulation got wrong result.
```
Loading ELF file /media/ord1nary/Yeah/Project/ara/apps/bin/rv64uv-ara-vmsbf
# Loading section 0000000080000000 of length 000000000000146a
# Loading section 0000000080001470 of length 00000000000004b8
# Loading section 0000000080001930 of length 0000000000000068
# [TRACER] Output filename is: trace_hart_0.log
# Checking the results of the test case 1:
# PASSED.
# Checking the results of the test case 2:
# PASSED.
# Checking the results of the test case 3:
# Index 0 FAILED. Got 3, expected 43.
# ERROR: /media/ord1nary/Yeah/Project/ara/apps/riscv-tests/isa/rv64uv/vmsbf.c failed 1 tests!
# ** Warning: Core Test *** FAILED *** (tohost = 1)
```
It shows that RTL simulation got a result of 0x3 instead of 0x43.
### Possible RTL Design Bug
I think there may be a bug in MaskUnit Design. Here is the code in masku.sv, line 501-515:
 ```verilog
[VMSBF:VMSIF] : begin
            if (&masku_operand_a_valid_i) begin
                for (int i = 0; i < NrLanes * DataWidth; i++) begin
                    if (alu_operand_b_seq[i] == 1'b0) begin
                        alu_result_vm[i] = (vinsn_issue.op == VMSOF) ? 1'b0 : not_found_one_d;
                    end else begin
                        not_found_one_d = 1'b0;
                        alu_result_vm[i] = (vinsn_issue.op == VMSBF) ? not_found_one_d : 1'b1;
                        break;
                    end
                end
                alu_result_vm_m = (!vinsn_issue.vm) ? alu_result_vm & bit_enable_mask : alu_result_vm;
            end else begin
                alu_result_vm = '0;
            end
```
We first get the result 'alu_result_vm' using the operand 'alu_operand_b_seq' which isn't masked and then mask the result to get 'alu_result_vm_m'. But actually we should mask the operand first and then get the result, according to the manual.
In this wrong case, we first get  result 0 0 0 0 0 0 1 1, and then mask it to get the final result 0 0 0 0 0 0 1 1(0x3)(where mask vector is 1 1 0 0 0 0 1 1).

mp-17, 2024-11-25:
Thanks a lot! I am refactoring the `MASKU` to solve the many bugs it has triggered.
If you want, can you try the base branch of [this PR](https://github.com/pulp-platform/ara/pull/376) and let me know if the bug is still there?

mp-17, 2024-11-25:
Okay, I have tried. The test should actually be:

```c
  VSET(8, e8, m1);
  VLOAD_8(v3, 0x94, 0, 0, 0, 0, 0, 0, 0);
  VLOAD_8(v0, 0xC3, 0, 0, 0, 0, 0, 0, 0);
  VCLEAR(v2);
  asm volatile("vmsbf.m v2, v3, v0.t");
  VSET(1, e8, m1);
  VCMP_U8(17, v2, 0x43);
```

Since you are comparing only the first 8 bits for this operation (the last ones are prescribed as tail-agnostic by the specs).

This tests passes with the new mask unit. I will add the test to the test suite, thank you! ;)

Feel free to re-open the issue if something is not clear.

Closed 2024-11-25.

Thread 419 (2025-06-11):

vwmacc.vx error when rs1 is temporary registers

hypertseng, 2025-06-11:
my application is a gemm kernel with int8 input and int16 output, partial dumped codes is as follows:
```
8007be8a: f727e057     	vwmacc.vx	v0, a5, v18
8007be8e: 00058783     	lb	a5, 0x0(a1)
8007be92: f72f6157     	vwmacc.vx	v2, t5, v18
8007be96: 95b6         	add	a1, a1, a3
8007be98: 00058f03     	lb	t5, 0x0(a1)
8007be9c: f72ee257     	vwmacc.vx	v4, t4, v18
```

the instruction which PC is 8007be8a can execute normally, but the 8007be92 instruction throws an exception:
```
Exception @  65601500, PC: 000000008007be92, Cause: Illegal Instruction,
				tval: 00000000f72f6157
```

mp-17, 2025-06-12:
Hi @hypertseng, can you please share the current `vtype` and `vl` configuration? Which is the last `vsetvl`, `vsetivli`, `vsetvli`, or CSR instruction executed before this code fragment?

mp-17, 2025-06-12:
Are you sure your code is correct, e.g., by running it on SPIKE or a golden simulator?
The issue is probably the vector register, and not the scalar register.

```
Some vector instructions have source and destination vector operands with the same number of
elements but different widths, so that EEW and EMUL differ from SEW and LMUL respectively but
EEW/EMUL = SEW/LMUL. For example, most widening arithmetic instructions have a source group
with EEW=SEW and EMUL=LMUL but have a destination group with EEW=2*SEW and EMUL=2*LMUL.

...

# Vector Widening Integer Multiply-Add Instructions
The widening integer multiply-add instructions add the full 2*SEW-bit product from a SEW-bit*SEW-bit multiply to a 2*SEW-bit value and produce a 2*SEW-bit result. All combinations of signed and
unsigned multiply operands are supported.
```

In your case, it seems that EMUL of the destination register is `EMUL = EEW * LMUL/SEW = 16 * 2/8 = 4`. If this is the case, `v2` as destination register is illegal.

hypertseng, 2025-06-12:
Oh thank you very much, it's indeed the application's error.

Closed 2025-06-12.

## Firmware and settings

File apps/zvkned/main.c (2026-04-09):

// Copyright 2024 ETH Zurich and University of Bologna.
// Licensed under the Apache License, Version 2.0, see LICENSE for details.
// SPDX-License-Identifier: Apache-2.0
//
// AES-128 ECB correctness test using RISC-V Zvkned vector crypto extension.
// Test vectors from NIST FIPS 197, Appendix A.1 (key schedule) and
// Appendix B (encrypt/decrypt).

#include <stdint.h>
#include <string.h>

#ifdef SPIKE
#include <stdio.h>
#else
#include "printf.h"
#include "runtime.h"
#endif

// ---------------------------------------------------------------------------
// NIST FIPS 197 test vectors – stored as little-endian uint32_t words.
//
// Conversion: each big-endian 32-bit column word 0xAABBCCDD becomes the
// uint32_t literal 0xDDCCBBAA on a little-endian machine, because byte 0xAA
// sits at the lowest address (bits [7:0]).
// ---------------------------------------------------------------------------

// Key: 2b7e1516 28aed2a6 abf71588 09cf4f3c
static const uint32_t aes128_key[4] __attribute__((aligned(16))) = {
    0x16157e2b, 0xa6d2ae28, 0x8815f7ab, 0x3c4fcf09};

// Plaintext: 3243f6a8 885a308d 313198a2 e0370734
static const uint32_t plaintext[4] __attribute__((aligned(16))) = {
    0xa8f64332, 0x8d305a88, 0xa2983131, 0x340737e0};

// Expected ciphertext: 3925841d 02dc09fb dc118597 196a0b32
static const uint32_t expected_ct[4] = {0x1d842539, 0xfb09dc02, 0x978511dc,
                                        0x320b6a19};

// Realistic standalone instruction operands/results derived from the FIPS 197
// AES-128 known-answer test. These let the suite validate each instruction in
// isolation before checking the full encrypt/decrypt flow.
static const uint32_t state_after_rk0[4] = {0xbee33d19, 0x2be2f4a0, 0x2a8dc69a,
                                            0x0848f8e9};

static const uint32_t state_after_round1[4] = {0xf27f9ca4, 0x2b359f68,
                                               0x43ea5b6b, 0x49506a02};

static const uint32_t state_after_round9[4] = {0x1ef240eb, 0x84382e59,
                                               0xe713a18b, 0xd242c31b};

static const uint32_t state_after_ct_rk10[4] = {0xb57d31e9, 0x722c32cb,
                                                0x5f892e3d, 0x940709af};

static const uint32_t state_after_inv_round9[4] = {0xa6466e87, 0x8ce74cf2,
                                                   0xd84a904d, 0x95c3ec97};

static const uint32_t state_before_final_decrypt[4] = {0x305dbfd4, 0xae52b4e0,
                                                       0xf11141b8, 0xe598271e};

// All 11 AES-128 round keys (from FIPS 197 Appendix A.1), LE uint32_t.
static const uint32_t expected_rk[11][4] = {
    {0x16157e2b, 0xa6d2ae28, 0x8815f7ab, 0x3c4fcf09}, // RK 0
    {0x17fefaa0, 0xb12c5488, 0x3939a323, 0x05766c2a}, // RK 1
    {0xf295c2f2, 0x43b9967a, 0x7a803559, 0x7ff65973}, // RK 2
    {0x7d47803d, 0x3efe1647, 0x447e231e, 0x3b887a6d}, // RK 3
    {0x41a544ef, 0x7f5b52a8, 0x3b2571b6, 0x00ad0bdb}, // RK 4
    {0xf8c6d1d4, 0x879d837c, 0xbcb8f2ca, 0xbc15f911}, // RK 5
    {0x7aa3886d, 0xfd3e0b11, 0x4186f9db, 0xfd9300ca}, // RK 6
    {0x0ef7544e, 0xf3c95f5f, 0xb24fa684, 0x4fdca64e}, // RK 7
    {0x2173d2ea, 0xd2ba8db5, 0x60f52b31, 0x2f298d7f}, // RK 8
    {0xf36677ac, 0x21dcfa19, 0x4129d128, 0x6e005c57}, // RK 9
    {0xa8f914d0, 0x8925eec9, 0xc80c3fe1, 0xa60c63b6}, // RK10
};

// ---------------------------------------------------------------------------
// Working buffers
// ---------------------------------------------------------------------------
static uint32_t result[4] __attribute__((aligned(16)));

// ---------------------------------------------------------------------------
// Helpers
// ---------------------------------------------------------------------------
static int cmp128(const uint32_t *got, const uint32_t *exp, const char *tag) {
  uint32_t got_snapshot[4];
  uint32_t exp_snapshot[4];
  int err = 0;
  for (int i = 0; i < 4; i++) {
    got_snapshot[i] = got[i];
    exp_snapshot[i] = exp[i];
  }
  for (int i = 0; i < 4; i++) {
    if (got_snapshot[i] != exp_snapshot[i]) {
      printf("  %s[%d]: got 0x%x, exp 0x%x\n", tag, i,
             (unsigned)got_snapshot[i], (unsigned)exp_snapshot[i]);
      err = 1;
    }
  }
  return err;
}

static void set_vl_128(void) {
  unsigned long vl;
  asm volatile("vsetvli %0, %1, e32, m1, ta, ma" : "=r"(vl) : "r"(4));
}

static void store_result(void) {
  asm volatile("vse32.v v4, (%0)" ::"r"(result) : "memory");
}

static void prepare_operands(const uint32_t *vd_in, const uint32_t *vs2_in,
                             uint32_t *vd_words, uint32_t *vs2_words) {
  for (int i = 0; i < 4; i++) {
    vd_words[i] = vd_in[i];
    vs2_words[i] = vs2_in[i];
  }
}

static void load_vd_vs2(const uint32_t *vd_words, const uint32_t *vs2_words) {
  asm volatile("vle32.v v4, (%0)" ::"r"(vd_words) : "memory");
  asm volatile("vle32.v v2, (%0)" ::"r"(vs2_words) : "memory");
}

// ---------------------------------------------------------------------------
// Test 1 – vaeskf1.vi  (AES-128 key schedule, rounds 1‥10)
// ---------------------------------------------------------------------------
static int test_key_schedule(void) {
  uint32_t round_keys[11][4] __attribute__((aligned(16)));
  int fail = 0;
  printf("Test 1: vaeskf1 (key schedule)\n");

  // Copy RK0
  for (int i = 0; i < 4; i++)
    round_keys[0][i] = aes128_key[i];

  // Set VL=4, SEW=32, LMUL=1  (one 128-bit element group)
  set_vl_128();

  // Load RK0 → v2
  asm volatile("vle32.v v2, (%0)" ::"r"(round_keys[0]));

  // Generate round keys 1‥10, alternating v2↔v4 to avoid WAR hazards.
  // Round number is an immediate, so we must unroll.
  asm volatile("vaeskf1.vi v4, v2, 1");
  asm volatile("vse32.v v4, (%0)" ::"r"(round_keys[1]) : "memory");

  asm volatile("vaeskf1.vi v2, v4, 2");
  asm volatile("vse32.v v2, (%0)" ::"r"(round_keys[2]) : "memory");

  asm volatile("vaeskf1.vi v4, v2, 3");
  asm volatile("vse32.v v4, (%0)" ::"r"(round_keys[3]) : "memory");

  asm volatile("vaeskf1.vi v2, v4, 4");
  asm volatile("vse32.v v2, (%0)" ::"r"(round_keys[4]) : "memory");

  asm volatile("vaeskf1.vi v4, v2, 5");
  asm volatile("vse32.v v4, (%0)" ::"r"(round_keys[5]) : "memory");

  asm volatile("vaeskf1.vi v2, v4, 6");
  asm volatile("vse32.v v2, (%0)" ::"r"(round_keys[6]) : "memory");

  asm volatile("vaeskf1.vi v4, v2, 7");
  asm volatile("vse32.v v4, (%0)" ::"r"(round_keys[7]) : "memory");

  asm volatile("vaeskf1.vi v2, v4, 8");
  asm volatile("vse32.v v2, (%0)" ::"r"(round_keys[8]) : "memory");

  asm volatile("vaeskf1.vi v4, v2, 9");
  asm volatile("vse32.v v4, (%0)" ::"r"(round_keys[9]) : "memory");

  asm volatile("vaeskf1.vi v2, v4, 10");
  asm volatile("vse32.v v2, (%0)" ::"r"(round_keys[10]) : "memory");

  for (int i = 0; i < 11; i++) {
    if (cmp128(round_keys[i], expected_rk[i], "RK")) {
      printf("  FAIL round key %d\n", i);
      fail++;
    }
  }
  if (!fail)
    printf("  PASSED (all 11 round keys)\n");
  return fail;
}

// ---------------------------------------------------------------------------
// Tests 2-9 – Single-instruction checks with realistic AES round-state inputs
// ---------------------------------------------------------------------------
static int test_vaesz_vs(void) {
  uint32_t vd_words[4] __attribute__((aligned(16)));
  uint32_t vs2_words[4] __attribute__((aligned(16)));

  printf("Test 2: vaesz.vs\n");
  set_vl_128();
  prepare_operands(plaintext, expected_rk[0], vd_words, vs2_words);
  load_vd_vs2(vd_words, vs2_words);
  asm volatile("vaesz.vs v4, v2");
  store_result();
  if (cmp128(result, state_after_rk0, "RK0")) {
    printf("  FAIL\n");
    return 1;
  }
  printf("  PASSED\n");
  return 0;
}

static int test_vaesem_vv(void) {
  uint32_t vd_words[4] __attribute__((aligned(16)));
  uint32_t vs2_words[4] __attribute__((aligned(16)));

  printf("Test 3: vaesem.vv\n");
  set_vl_128();
  prepare_operands(state_after_rk0, expected_rk[1], vd_words, vs2_words);
  load_vd_vs2(vd_words, vs2_words);
  asm volatile("vaesem.vv v4, v2");
  store_result();
  if (cmp128(result, state_after_round1, "R1")) {
    printf("  FAIL\n");
    return 1;
  }
  printf("  PASSED\n");
  return 0;
}

static int test_vaesem_vs(void) {
  uint32_t vd_words[4] __attribute__((aligned(16)));
  uint32_t vs2_words[4] __attribute__((aligned(16)));

  printf("Test 4: vaesem.vs\n");
  set_vl_128();
  prepare_operands(state_after_rk0, expected_rk[1], vd_words, vs2_words);
  load_vd_vs2(vd_words, vs2_words);
  asm volatile("vaesem.vs v4, v2");
  store_result();
  if (cmp128(result, state_after_round1, "R1")) {
    printf("  FAIL\n");
    return 1;
  }
  printf("  PASSED\n");
  return 0;
}

static int test_vaesef_vv(void) {
  uint32_t vd_words[4] __attribute__((aligned(16)));
  uint32_t vs2_words[4] __attribute__((aligned(16)));

  printf("Test 5: vaesef.vv\n");
  set_vl_128();
  prepare_operands(state_after_round9, expected_rk[10], vd_words, vs2_words);
  load_vd_vs2(vd_words, vs2_words);
  asm volatile("vaesef.vv v4, v2");
  store_result();
  if (cmp128(result, expected_ct, "CT")) {
    printf("  FAIL\n");
    return 1;
  }
  printf("  PASSED\n");
  return 0;
}

static int test_vaesef_vs(void) {
  uint32_t vd_words[4] __attribute__((aligned(16)));
  uint32_t vs2_words[4] __attribute__((aligned(16)));

  printf("Test 6: vaesef.vs\n");
  set_vl_128();
  prepare_operands(state_after_round9, expected_rk[10], vd_words, vs2_words);
  load_vd_vs2(vd_words, vs2_words);
  asm volatile("vaesef.vs v4, v2");
  store_result();
  if (cmp128(result, expected_ct, "CT")) {
    printf("  FAIL\n");
    return 1;
  }
  printf("  PASSED\n");
  return 0;
}

static int test_vaesdm_vv(void) {
  uint32_t vd_words[4] __attribute__((aligned(16)));
  uint32_t vs2_words[4] __attribute__((aligned(16)));

  printf("Test 7: vaesdm.vv\n");
  set_vl_128();
  prepare_operands(state_after_ct_rk10, expected_rk[9], vd_words, vs2_words);
  load_vd_vs2(vd_words, vs2_words);
  asm volatile("vaesdm.vv v4, v2");
  store_result();
  if (cmp128(result, state_after_inv_round9, "R9")) {
    printf("  FAIL\n");
    return 1;
  }
  printf("  PASSED\n");
  return 0;
}

static int test_vaesdm_vs(void) {
  uint32_t vd_words[4] __attribute__((aligned(16)));
  uint32_t vs2_words[4] __attribute__((aligned(16)));

  printf("Test 8: vaesdm.vs\n");
  set_vl_128();
  prepare_operands(state_after_ct_rk10, expected_rk[9], vd_words, vs2_words);
  load_vd_vs2(vd_words, vs2_words);
  asm volatile("vaesdm.vs v4, v2");
  store_result();
  if (cmp128(result, state_after_inv_round9, "R9")) {
    printf("  FAIL\n");
    return 1;
  }
  printf("  PASSED\n");
  return 0;
}

static int test_vaesdf_vv(void) {
  uint32_t vd_words[4] __attribute__((aligned(16)));
  uint32_t vs2_words[4] __attribute__((aligned(16)));

  printf("Test 9: vaesdf.vv\n");
  set_vl_128();
  prepare_operands(state_before_final_decrypt, expected_rk[0], vd_words,
                   vs2_words);
  load_vd_vs2(vd_words, vs2_words);
  asm volatile("vaesdf.vv v4, v2");
  store_result();
  if (cmp128(result, plaintext, "PT")) {
    printf("  FAIL\n");
    return 1;
  }
  printf("  PASSED\n");
  return 0;
}

static int test_vaesdf_vs(void) {
  uint32_t vd_words[4] __attribute__((aligned(16)));
  uint32_t vs2_words[4] __attribute__((aligned(16)));

  printf("Test 10: vaesdf.vs\n");
  set_vl_128();
  prepare_operands(state_before_final_decrypt, expected_rk[0], vd_words,
                   vs2_words);
  load_vd_vs2(vd_words, vs2_words);
  asm volatile("vaesdf.vs v4, v2");
  store_result();
  if (cmp128(result, plaintext, "PT")) {
    printf("  FAIL\n");
    return 1;
  }
  printf("  PASSED\n");
  return 0;
}

// ---------------------------------------------------------------------------
// Test 11 – AES-128 encryption  (vaesz.vs + vaesem.vv×9 + vaesef.vv)
// ---------------------------------------------------------------------------
static int test_encrypt_vv(void) {
  uint32_t vd_words[4] __attribute__((aligned(16)));
  uint32_t vs2_words[4] __attribute__((aligned(16)));

  printf("Test 11: AES-128 encrypt (.vv)\n");

  set_vl_128();
  prepare_operands(plaintext, expected_rk[0], vd_words, vs2_words);
  load_vd_vs2(vd_words, vs2_words);
  asm volatile("vaesz.vs v4, v2");
  for (int i = 1; i <= 9; i++) {
    store_result();
    prepare_operands(result, expected_rk[i], vd_words, vs2_words);
    load_vd_vs2(vd_words, vs2_words);
    asm volatile("vaesem.vv v4, v2");
  }
  store_result();
  prepare_operands(result, expected_rk[10], vd_words, vs2_words);
  load_vd_vs2(vd_words, vs2_words);
  asm volatile("vaesef.vv v4, v2");
  store_result();

  if (cmp128(result, expected_ct, "CT")) {
    printf("  FAIL\n");
    return 1;
  }
  printf("  PASSED\n");
  return 0;
}

// ---------------------------------------------------------------------------
// Test 3 – AES-128 decryption  (vaesz.vs + vaesdm.vv×9 + vaesdf.vv)
// Uses the standard inverse cipher ordering with unmodified round keys.
// ---------------------------------------------------------------------------
static int test_decrypt_vv(void) {
  uint32_t vd_words[4] __attribute__((aligned(16)));
  uint32_t vs2_words[4] __attribute__((aligned(16)));

  printf("Test 12: AES-128 decrypt (.vv)\n");

  set_vl_128();
  prepare_operands(expected_ct, expected_rk[10], vd_words, vs2_words);
  load_vd_vs2(vd_words, vs2_words);
  asm volatile("vaesz.vs v4, v2");

  // Rounds 9‥1: decrypt middle (reverse key order)
  for (int i = 9; i >= 1; i--) {
    store_result();
    prepare_operands(result, expected_rk[i], vd_words, vs2_words);
    load_vd_vs2(vd_words, vs2_words);
    asm volatile("vaesdm.vv v4, v2");
  }

  // Final round: decrypt final with RK0
  store_result();
  prepare_operands(result, expected_rk[0], vd_words, vs2_words);
  load_vd_vs2(vd_words, vs2_words);
  asm volatile("vaesdf.vv v4, v2");
  store_result();

  if (cmp128(result, plaintext, "PT")) {
    printf("  FAIL\n");
    return 1;
  }
  printf("  PASSED\n");
  return 0;
}

// ---------------------------------------------------------------------------
// Test 4 – AES-128 encryption with .vs variants
// The .vs instructions broadcast the key from element-group 0 of vs2.
// With VL=4 (one element group) the result must match the .vv test.
// ---------------------------------------------------------------------------
static int test_encrypt_vs(void) {
  uint32_t vd_words[4] __attribute__((aligned(16)));
  uint32_t vs2_words[4] __attribute__((aligned(16)));

  printf("Test 13: AES-128 encrypt (.vs)\n");

  set_vl_128();
  prepare_operands(plaintext, expected_rk[0], vd_words, vs2_words);
  load_vd_vs2(vd_words, vs2_words);
  asm volatile("vaesz.vs v4, v2");

  // Rounds 1‥9
  for (int i = 1; i <= 9; i++) {
    store_result();
    prepare_operands(result, expected_rk[i], vd_words, vs2_words);
    load_vd_vs2(vd_words, vs2_words);
    asm volatile("vaesem.vs v4, v2");
  }

  // Round 10
  store_result();
  prepare_operands(result, expected_rk[10], vd_words, vs2_words);
  load_vd_vs2(vd_words, vs2_words);
  asm volatile("vaesef.vs v4, v2");
  store_result();

  if (cmp128(result, expected_ct, "CT")) {
    printf("  FAIL\n");
    return 1;
  }
  printf("  PASSED\n");
  return 0;
}

// ---------------------------------------------------------------------------
// Test 5 – AES-128 decryption with .vs variants
// ---------------------------------------------------------------------------
static int test_decrypt_vs(void) {
  uint32_t vd_words[4] __attribute__((aligned(16)));
  uint32_t vs2_words[4] __attribute__((aligned(16)));

  printf("Test 14: AES-128 decrypt (.vs)\n");

  set_vl_128();
  prepare_operands(expected_ct, expected_rk[10], vd_words, vs2_words);
  load_vd_vs2(vd_words, vs2_words);
  asm volatile("vaesz.vs v4, v2");

  for (int i = 9; i >= 1; i--) {
    store_result();
    prepare_operands(result, expected_rk[i], vd_words, vs2_words);
    load_vd_vs2(vd_words, vs2_words);
    asm volatile("vaesdm.vs v4, v2");
  }

  store_result();
  prepare_operands(result, expected_rk[0], vd_words, vs2_words);
  load_vd_vs2(vd_words, vs2_words);
  asm volatile("vaesdf.vs v4, v2");
  store_result();

  if (cmp128(result, plaintext, "PT")) {
    printf("  FAIL\n");
    return 1;
  }
  printf("  PASSED\n");
  return 0;
}

// ---------------------------------------------------------------------------
// Test 6 – Round-trip: encrypt then decrypt must recover plaintext
// ---------------------------------------------------------------------------
static int test_roundtrip(void) {
  uint32_t vd_words[4] __attribute__((aligned(16)));
  uint32_t vs2_words[4] __attribute__((aligned(16)));

  printf("Test 15: encrypt-then-decrypt round-trip\n");

  set_vl_128();

  // Encrypt
  prepare_operands(plaintext, expected_rk[0], vd_words, vs2_words);
  load_vd_vs2(vd_words, vs2_words);
  asm volatile("vaesz.vs v4, v2");
  for (int i = 1; i <= 9; i++) {
    store_result();
    prepare_operands(result, expected_rk[i], vd_words, vs2_words);
    load_vd_vs2(vd_words, vs2_words);
    asm volatile("vaesem.vv v4, v2");
  }
  store_result();
  prepare_operands(result, expected_rk[10], vd_words, vs2_words);
  load_vd_vs2(vd_words, vs2_words);
  asm volatile("vaesef.vv v4, v2");

  // Decrypt (v4 still holds the ciphertext)
  store_result();
  prepare_operands(result, expected_rk[10], vd_words, vs2_words);
  load_vd_vs2(vd_words, vs2_words);
  asm volatile("vaesz.vs v4, v2");
  for (int i = 9; i >= 1; i--) {
    store_result();
    prepare_operands(result, expected_rk[i], vd_words, vs2_words);
    load_vd_vs2(vd_words, vs2_words);
    asm volatile("vaesdm.vv v4, v2");
  }
  store_result();
  prepare_operands(result, expected_rk[0], vd_words, vs2_words);
  load_vd_vs2(vd_words, vs2_words);
  asm volatile("vaesdf.vv v4, v2");
  store_result();

  if (cmp128(result, plaintext, "RT")) {
    printf("  FAIL\n");
    return 1;
  }
  printf("  PASSED\n");
  return 0;
}

// ---------------------------------------------------------------------------
int main(void) {
  int num_failed = 0;

  printf("=== Zvkned AES-128 Test Suite ===\n\n");

  num_failed += test_key_schedule();
  num_failed += test_vaesz_vs();
  num_failed += test_vaesem_vv();
  num_failed += test_vaesem_vs();
  num_failed += test_vaesef_vv();
  num_failed += test_vaesef_vs();
  num_failed += test_vaesdm_vv();
  num_failed += test_vaesdm_vs();
  num_failed += test_vaesdf_vv();
  num_failed += test_vaesdf_vs();
  num_failed += test_encrypt_vv();
  num_failed += test_decrypt_vv();
  num_failed += test_encrypt_vs();
  num_failed += test_decrypt_vs();
  num_failed += test_roundtrip();

  printf("\n=== Summary: %d test(s) failed ===\n", num_failed);
  return num_failed;
}

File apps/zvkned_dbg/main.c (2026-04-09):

// Zvkned single-instruction debug test
// Select which instruction to test by defining exactly one of:
//   TEST_VAESZ, TEST_VAESZ_2G,
//   TEST_VAESEM, TEST_VAESEM_2G, TEST_VAESEM_VS, TEST_VAESEM_VS_2G,
//   TEST_VAESEF, TEST_VAESEF_2G, TEST_VAESEF_VS, TEST_VAESEF_VS_2G,
//   TEST_VAESDM, TEST_VAESDM_2G, TEST_VAESDM_VS, TEST_VAESDM_VS_2G,
//   TEST_VAESDF, TEST_VAESDF_2G, TEST_VAESDF_VS, TEST_VAESDF_VS_2G,
//   TEST_VAESKF1, TEST_VAESKF2_EVEN, TEST_VAESKF2_ODD
// Default: TEST_VAESZ
//
// AES-128 vectors from NIST FIPS 197 Appendix B, verified by
// gen_test_vectors.py AES-256 vectors from NIST FIPS 197 Appendix A.3 (vaeskf2
// tests)

#include <stdint.h>

#ifdef SPIKE
#include <stdio.h>
#else
#include "printf.h"
#include "runtime.h"
#endif

// Default to TEST_VAESZ if nothing is defined
#if !defined(TEST_VAESZ) && !defined(TEST_VAESZ_2G) &&                         \
    !defined(TEST_VAESEM) && !defined(TEST_VAESEM_2G) &&                       \
    !defined(TEST_VAESEM_VS) && !defined(TEST_VAESEM_VS_2G) &&                 \
    !defined(TEST_VAESEF) && !defined(TEST_VAESEF_2G) &&                       \
    !defined(TEST_VAESEF_VS) && !defined(TEST_VAESEF_VS_2G) &&                 \
    !defined(TEST_VAESDM) && !defined(TEST_VAESDM_2G) &&                       \
    !defined(TEST_VAESDM_VS) && !defined(TEST_VAESDM_VS_2G) &&                 \
    !defined(TEST_VAESDF) && !defined(TEST_VAESDF_2G) &&                       \
    !defined(TEST_VAESDF_VS) && !defined(TEST_VAESDF_VS_2G) &&                 \
    !defined(TEST_VAESKF1) && !defined(TEST_VAESKF2_EVEN) &&                   \
    !defined(TEST_VAESKF2_ODD)
#define TEST_VAESZ
#endif

// FIPS 197 Appendix B, AES-128 key (LE uint32)
// BE: 2b7e1516 28aed2a6 abf71588 09cf4f3c
static uint32_t rk0[4] __attribute__((aligned(16))) = {0x16157e2b, 0xa6d2ae28,
                                                       0x8815f7ab, 0x3c4fcf09};

// FIPS 197 Appendix B, AES-128 plaintext (LE uint32)
// BE: 3243f6a8 885a308d 313198a2 e0370734
static uint32_t plaintext[4] __attribute__((aligned(16))) = {
    0xa8f64332, 0x8d305a88, 0xa2983131, 0x340737e0};

// Round key 1 (from vaeskf1 round 1)
static uint32_t rk1[4] __attribute__((aligned(16))) = {0x17fefaa0, 0xb12c5488,
                                                       0x3939a323, 0x05766c2a};

// Round key 9
static uint32_t rk9[4] __attribute__((aligned(16))) = {0xf36677ac, 0x21dcfa19,
                                                       0x4129d128, 0x6e005c57};

// Round key 10
static uint32_t rk10[4] __attribute__((aligned(16))) = {0xa8f914d0, 0x8925eec9,
                                                        0xc80c3fe1, 0xa60c63b6};

// State after vaesz.vs (plaintext XOR rk0)
static uint32_t state_after_rk0[4] __attribute__((aligned(16))) = {
    0xbee33d19, 0x2be2f4a0, 0x2a8dc69a, 0x0848f8e9};

static uint32_t rk2[4] __attribute__((aligned(16))) = {0xf295c2f2, 0x43b9967a,
                                                       0x7a803559, 0x7ff65973};

static uint32_t rk8[4] __attribute__((aligned(16))) = {0x2173d2ea, 0xd2ba8db5,
                                                       0x60f52b31, 0x2f298d7f};

static uint32_t state_after_round1[4] __attribute__((aligned(16))) = {
    0xf27f9ca4, 0x2b359f68, 0x43ea5b6b, 0x49506a02};

static uint32_t state_after_round2[4] __attribute__((aligned(16))) = {
    0x035f8faa, 0xefe3dd61, 0xd24ad282, 0x9a463268};

static uint32_t state_after_round8[4] __attribute__((aligned(16))) = {
    0xf05c83ea, 0x2d334504, 0xad985d65, 0xc5b09685};

static uint32_t vaesz_state_after_round9_rk0[4] __attribute__((aligned(16))) = {
    0x08e73ec0, 0x22ea8071, 0x6f065620, 0xee0d0c12};

static uint32_t vaesem_round1_with_rk1[4] __attribute__((aligned(16))) = {
    0xe634b7f8, 0x1d761f93, 0x91f344f8, 0xe0c60731};

static uint32_t vaesef_state_after_rk0_rk1[4] __attribute__((aligned(16))) = {
    0x27a34574, 0x1f7ee068, 0xc828e29b, 0xe0ee4b34};

static uint32_t vaesef_state_after_rk0_rk10[4] __attribute__((aligned(16))) = {
    0x98a4ab04, 0x27775a29, 0x391d7e59, 0x439444a8};

static uint32_t vaesdm_round1_with_rk9[4] __attribute__((aligned(16))) = {
    0xc71c3d6d, 0xaba89ad8, 0x3ec67d19, 0xdd0eba6a};

static uint32_t vaesdf_round1_with_rk1[4] __attribute__((aligned(16))) = {
    0xe7a2794a, 0x9c1f118c, 0x94a1fe46, 0xc0c6faaf};

static uint32_t vaesdf_round1_with_rk0[4] __attribute__((aligned(16))) = {
    0xe649fdc1, 0x8be1eb2c, 0x258daace, 0xf9ff598c};

#if defined(TEST_VAESZ_2G) || defined(TEST_VAESEM_2G) ||                       \
    defined(TEST_VAESEM_VS_2G) || defined(TEST_VAESEF_2G) ||                   \
    defined(TEST_VAESEF_VS_2G) || defined(TEST_VAESDM_2G) ||                   \
    defined(TEST_VAESDM_VS_2G) || defined(TEST_VAESDF_2G) ||                   \
    defined(TEST_VAESDF_VS_2G)
#define TEST_WORDS 8
#else
#define TEST_WORDS 4
#endif

// ── Per-instruction test data ────────────────────────────────────────────────

#ifdef TEST_VAESZ
// vaesz.vs: vd = plaintext, vs2 = RK0 → state_after_rk0
#define VD_DATA plaintext
#define VS2_DATA rk0
static uint32_t expected[4] __attribute__((aligned(16))) = {
    0xbee33d19, 0x2be2f4a0, 0x2a8dc69a, 0x0848f8e9};
static const char *test_name = "vaesz.vs";
#endif

#ifdef TEST_VAESZ_2G
static uint32_t vd_data[8] __attribute__((aligned(16))) = {
    0xa8f64332, 0x8d305a88, 0xa2983131, 0x340737e0,
    0x1ef240eb, 0x84382e59, 0xe713a18b, 0xd242c31b};
static uint32_t vs2_data[8] __attribute__((aligned(16))) = {
    0x16157e2b, 0xa6d2ae28, 0x8815f7ab, 0x3c4fcf09,
    0xa8f914d0, 0x8925eec9, 0xc80c3fe1, 0xa60c63b6};
#define VD_DATA vd_data
#define VS2_DATA vs2_data
static uint32_t expected[8] __attribute__((aligned(16))) = {
    0xbee33d19, 0x2be2f4a0, 0x2a8dc69a, 0x0848f8e9,
    0x08e73ec0, 0x22ea8071, 0x6f065620, 0xee0d0c12};
static const char *test_name = "vaesz.vs (2 groups)";
#endif

#if defined(TEST_VAESEM) || defined(TEST_VAESEM_VS)
// vaesem: vd = state_after_rk0, vs2 = RK1 → round 1 state
#define VD_DATA state_after_rk0
#define VS2_DATA rk1
static uint32_t expected[4] __attribute__((aligned(16))) = {
    0xf27f9ca4, 0x2b359f68, 0x43ea5b6b, 0x49506a02};
#ifdef TEST_VAESEM
static const char *test_name = "vaesem.vv";
#else
static const char *test_name = "vaesem.vs";
#endif
#endif

#ifdef TEST_VAESEM_2G
static uint32_t vd_data[8] __attribute__((aligned(16))) = {
    0xbee33d19, 0x2be2f4a0, 0x2a8dc69a, 0x0848f8e9,
    0xf27f9ca4, 0x2b359f68, 0x43ea5b6b, 0x49506a02};
static uint32_t vs2_data[8] __attribute__((aligned(16))) = {
    0x17fefaa0, 0xb12c5488, 0x3939a323, 0x05766c2a,
    0xf295c2f2, 0x43b9967a, 0x7a803559, 0x7ff65973};
#define VD_DATA vd_data
#define VS2_DATA vs2_data
static uint32_t expected[8] __attribute__((aligned(16))) = {
    0xf27f9ca4, 0x2b359f68, 0x43ea5b6b, 0x49506a02,
    0x035f8faa, 0xefe3dd61, 0xd24ad282, 0x9a463268};
static const char *test_name = "vaesem.vv (2 groups)";
#endif
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

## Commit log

2021-03-09 [cva6] ld/st semaphore on full memory
    implemented in EX stage. Can deadlock.
2021-03-09 [cva6] :bug: load-store ordering: fix corner case
2021-03-09 [ci] Compile the Verilator model with traces
2021-03-09 [ci] Create traces of the simv tests
2021-03-09 [hardware] :truck: Rename the AXI invalidation filter
2021-03-09 [apps] Fix matmul's verify_matrix function
    [main.c]
2021-03-09 [ara] Update the LICENSE to Solderpad v0.51
2021-03-09 [hardware] Block issue stage until fcsr writes are over upon ACCEL request
2021-03-09 [hardware] Remove issue-stage block upon ACCEL request+pending fcsr write
2021-03-09 [apps] Make fmatmul print float numbers
2021-03-09 [hardware] Remove unreachable case
2021-03-09 [cva6] Add CVA6 as a submodule
    [ariane-multi-hart.cfg, ariane.cfg, ariane_boot.cfg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]
2021-03-12 [ci] Print-out the commit hash
2021-05-25 [apps] Re-insert GCC_PATH variable
2021-07-15 [hardware] :bug: Calculate `vstu`'s vl based on the current `SEW`
2021-08-05 [hardware] Cut critical paths
2021-08-05 [hardware] :bug: Lanes accept and grant their incoming masks
    The introduction of the spill register at the edge of the lanes
    to cut the critical path in2out of mask_ready_o introduces an
    issue: the lanes now acknowledge and store all the incoming
    mask requests, even if they are for other units (e.g., sldu).
    This brings two problems: the spill reg saves a mask value
    that cannot be drained since the request was not for the lanes,
    and the lanes acknowledge the mask unit even if the correct
    unit destination of the request (e.g., the sldu) was not ready
    and did not registered the mask.
    Now the ALU and the MFPU tell the spill register if they are
    waiting for a request from the mask unit: if not, t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
2021-09-29 [hardware] :bug: Fix addrgen for bursts with len > 256
    There were multiple bugs here:
    addrgen unit:
    1) The condition "if (((1 << 12) >> $clog2(AxiDataWidth/8)) > 256)" was wrong (less than, not greater than).
    2) Fixing 1) allowed to have a correct burst length of 256 in the case of 2 lanes (AxiWidth == 64 bit) and 4096 byte to transfer.
    3) The computation of the aligned end address was not keeping this into account. If the burst was saturated to 256, the resulting end address was wrong.
    4) Fixing 3) I also removed some redundant conditions for the burst length calculation. The page limit is kept into account when the end address is computed, so we can skip them.
    load/store unit:
    5) The comp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
2021-09-30 [hardware] Generate traces when running a Verilator simulation
2021-10-10 [hardware] :bug: Some SLIDE instructions cannot chain
    VSLIDEUP cannot chain a previous instruction with which it has a WAW or WAR hazard, as VSLIDEUP writes to arbitrary positions of the VRF, and this can interfere with the read process of the previous instruction.
    VSLIDEDOWN cannot chain a previous instruction with which it has a RAW hazard, as VSLIDEDOWN reads from arbitrary positions of the VRF, and it's not sure that the previous instruction already wrote those positions.
2021-10-15 [ci] :memo: Simulate `riscv-tests` with eight parallel threads
2021-11-08 [hardware] :bug: Fix lanes unbalancing
    The lanes de-synchronizes in terms of giving back the signal of
    "instruction done" when the load is not balanced. So they must be
    all together ready to accept the new instruction, so that all of
    them can sample it.
2021-11-08 [hardware] :bug: Stall sequencer if lane 0 is not the last at finishing
2022-03-27 [hardware] :alien: Cut in2out path in valu
2022-03-27 [hardware] Unparametrize the lanes
    Reductions required new hardware, and each lane
    had different hardware for reductions. Our pnr flow
    needs that all the lanes are the same, so the parameter
    to differenciate the lanes is removed, now. This will
    bring to worse timing and higher area.
2022-03-27 [hardware] :alien: Cut in2reg path in lane
2022-03-27 [hardware] :bug: Fix issue stage in sequencer
2022-03-27 [hardware] :bug: Handle hazards globally from main sequencer
    When the sequencer issues an instruction, it also saves the information
    about its hazards in an entry of the global_hazard_table.
    This table keeps, for each instruction, up to date information on the
    status of the offender previous instructions. This information is given
    to the operand requesters, which can handle the stalls downstream.
    Before the introduction of the global hazard table, each instruction
    kept, in the pipeline, information about the status of the offending
    instructions. When this is the case, these information must be kept
    up to date in multiple points of the pipeline.
    With the introduction of new fall-through regis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
2022-03-27 [hardware] :bug: Fix stream registers bug in operand requesters
    The operand requesters has three stream registers to cut in2out
    paths from LDU, SLDU, MASKU, when they act as masters and write
    results into the VRF. The stream registers grant the requests
    as soon as the result is accepted, but this does not mean that
    the result is written in the VRF (this can happen various cycles
    later, as there can be bank conflicts).
    Issue is that the given grant will tell the main sequencer that
    the instruciton is done, and that all the instructions that have
    an hazard on that finished instruciton can now execute. This is not
    true, as the result was not already written back and the instruction
    is NOT finis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
2022-04-11 [hardware] :bug: Fix corner case assignment in MASKU
    Fun fact: this bug did not show with Questa, but only on Verilator.
    The two simulators provided different outputs during a simulation.
2022-05-04 [riscv-tests] Add corner case test for vslidedown
2022-07-11 [hardware] :bug: Fix instruction-change engine after reduction in VALU
    1) VALU now cleans up the result queue after a reduction partial result
    2) The instruction following a reduction will start only upon
    commit of the reduction itself
    3) When a reduction follows a normal operation, it can happen that
    the reduction operands starts coming before the main FSM goes in the
    correct state. For this reason, the operands should not be consumed
    if the current instruction is a reduction AND we are not in the
    INTRA_LANE_REDUCTION state yet
2022-07-13 [hardware] :bug: Enforce full in-order execution of FPU instructions
    fpnew is composed of different unbalanced pipelined datapaths,
    therefore it's possible that new instructions finish execution
    before older ones.
    In Ara, this should never happen. Therefore, if a potential latency
    problem is detected, the issue instruction stalls.
2022-07-13 [hardware] :bug: Fix AXI inval filter policy for misaligned accesses
    Add some necessary logic to the axi inval filter to correctly
    invalidate scalar D$ lines upon vector misaligned stores.
2022-08-04 [hardware] :bug: Stall when LMUL changes and LMUL_new < LMUL_old
    If LMUL_new < LMUL_old, new registers can be selected from the insn.
    These "new" registers were not tracked by the hazard engine,
    so we should wait until Ara finishes executing the old instructions
    before issuing the new ones to avoid hazard violations.
2022-08-15 [hardware] :bug: Fix (misaligned && (beats>=256)) mem op case
2022-09-22 Add vfredusum benchmark, fix vmfpu & sldu bugs
    [main.c]
2022-09-22 Fix odered sum operand processing bug and add benchmark for EW64 and ordered sum
    [main.c]
2022-09-22 Fix corner case: vfredusum-vfredusum, vfredusum-vfadd, vfadd-vfredusum
    [main.c]
2022-09-22 [hardware] :bug: Fix rebase issues
    [main.c]
2022-09-22 [hardware] :space_invader: Cut critical path
2022-09-22 [apps] Rework and fix the fdotproduct benchmark
    [main.c]
2022-09-22 [apps] Rewrite and fix vfredsum benchmark
    [main.c]
2022-09-29 [hardware] :bug: Fix reductions + rework the VALU module
    The previous mechanism to handle the commit during a reduction
    was confusing and led to bugs. Now, the reduction triggers its
    commit only after the inter-lanes phase is over.
2022-10-13 [hardware] :bug: Reshuffle source vregs for in-lane ops
    In case of an operation executed within the lanes (e.g., vadd),
    the lanes cannot read the vector correctly if the vsew of the
    source register is different from the eew_q of that register
    (different byte layout!). So, we need to reshuffle in this case
    as well. Since this is costly, the suggested software procedure
    is to avoid filling a register with an encoding and using it
    with a different one.
2022-10-17 [apps] Fix fconv*d to work with new util.(c,h) files
    [main.c]
2022-10-17 [scripts, apps] Minimize Jacobi2d memory footprint
2022-10-17 [apps] Update dropout and print performance
2022-10-17 [.github] Add Dropout to the CI and print performance
2022-10-17 [apps] :bug: Fix mask load pointer bumping
    [main.c]
2022-10-27 [scrpit, apps] Print exp benchmark performance
2022-11-18 [hardware] Cut problematic adder path in addrgen
2022-11-20 [hardware] :bug: Operand requesters sanitize the partial operands
    Not all the opqueues support the netural value filling, so that we
    can decrease the overall timing pressure/congestion
2022-12-02 [hardware] Add SpyGlass flow
2022-12-10 [apps] Solve duplicate function error during benchmark
    [main.c]
2022-12-10 [apps] Optimize assembly exp function
2022-12-10 [hardware] :bug: Don't let the lanes sample insn more than once
2022-12-13 [hardware] :sparkles: Power-gate the SIMD multipliers
2023-01-23 [docs] :books: Added documentation for Vector Registor File
    [Vector_Starting_Addr.csv]
2023-02-01 Uncomment test forvfncvt.rod.f.f instruction
2023-02-01 [apps] add tests to verify case when flags=0 and mantissa[0]=0,1
2023-02-02 [hardware] :bug: Fix unique case statements in ara_pkg
2023-03-01 [hardware] Power gate the VRF
2023-03-01 [hardware] :alien: Cut the SLDU input operand paths
2023-03-03 [hardware] Optimize SLDU datapath
    The slide unit interconnect is now simpler and allows
    for power-of-two slides only. Additionally it can
    re-encode the vector registers, but without sliding
    them at the same time! So, either we re-encode,
    or we slide.
    The non-power-of-two slides are expected to be slow
    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
2023-12-01 cva6: Bump (remove stall signls)
2023-12-01 [hardware, .gitmodules] Switch from submodules to bender
2023-12-01 [hardware] :bug: Filter operand queue ready from sldu and addrgen
    The addrgen-sldu operand queue is common to slide unit and addrgen.
    Since it's shared, we should be sure not to sample a
    spurious ready from the wrong unit, i.e., when we are
    feeding the addrgen, we don't want spurious readies from
    the slide unit. The units should be responsible for avoiding
    sampling wrong data, but spurious ready signals can happen in
    specific corner cases. Fixing this without impacting timing is
    hard, so we just mask the ready signals here as well to avoid
    bugs.
2023-12-03 [scripts] Print information in a format understandable by plot2d
2023-12-03 [hardware, script] Print D$, I$ stalls + sb_full metrics
2023-12-03 [script] Adapt script to dcache, icache stalls and sbfull metrics
2023-12-03 [script] Print performance against the number of Byte
2024-06-28 Stall Ara upon operations on vector CSRs
2024-07-09 Update submodules
    * Switch from pulp-platform/cva6 to MaistoV/cva6_fork
    * Bump axi to v0.39.0
2024-07-09 [hardware] Support VLD and VST with vstart > 0
    - Restrict mem bus to EW if vstore, vstart > 0, and EW < 64-bit
    If vstart > 0 and EW < 64, the situation is similar to when the memory addr
    is misaligned wrt the memory bus. Because of the VRF Byte Layout and
    since the granularity of each lane's payload to the store unit is 64 bit,
    all the packets can contain valid data while we have not completed the
    beat. So, either we calculate in the addrgen the effective length of a
    bursts with unequal beats, or we add a buffer and aligner in the store
    unit, or we handle the ready signals at a byte level, or we simply reduce
    the effective memory bus to the element width (worst case).
    We do the latter. It's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
2024-07-09 [hardware] :bug: Fix case when ld exception is not on the first beat
2024-07-09 [hardware] :bug: Fix case when st exception is not on the first beat
2024-07-30 [apps] Fix fft performance
    [main.c]
2024-08-24 [apps] Fix multi-precision matmul
    [main.c]
2024-08-26 [hardware] :bug: Stall vfdiv/vfsqrt not to violate insn ordering
2024-09-07 [hardware] 🐛Fix vasub&vasubu error in simd_alu.
2024-11-11 [hardware] Cut ready path from VLSU to masku
    Before, there was a stream register only, which does NOT cut the ready path.
2025-01-07 Add back-referencing bitstream compile flow to Cheshire
2025-01-07 [cheshire] Back-ref sw compilation flow for fmatmul
2025-01-07 Add device tree patch for cheshire
2025-01-07 [cheshire] Add RVV-Linux img compilation flow
2025-01-07 [cheshire] Add LINUX + SW flow for cheshire
2025-01-07 [cheshire] Parametrize FPGA flow
    The flow now also works with VCU11
2025-01-14 [hardware] Cut MMU-enable path
2025-01-20 [hardware] :bug: Abort pe_req in case of addrgen exception
2025-01-20 [hardware] Refactor STU-exception flush engine
    When a store-translation exception occurs, Ara's backend
    should be flushed as soon as the instruction preceding the
    store is over. This happens when ara is idle again.
    Ara's frontend (dispatcher, sequencer) are already "flushed".
    Therefore, we wait for idle, and then we inject a flush
    command to flush the pipeline following the data stream to be
    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
2025-01-20 [hardware] :bug: Kill main seq request upon stu MMU exception
    In case of an exception on this burst, kill the request.
    Exceptions on this burst mean that all the valid sources
    have been fetched from VRF already. Don't immediately
    kill when detecting the exception in the addrgen, as previous
    valid bursts can still need operands to be fetched from the VRF.
2025-02-12 [hardware] 🐛Fix vssub error in simd_alu.
2026-04-09 [hardware] Fix Zvkned AES instruction completion and consolidate modules
    Fix dispatcher missing acc_resp_o.resp_valid for OpcodeRsrvd3 (OP-VE)
    crypto instructions, which caused CVA6 to hang waiting to commit.
    Also fix VALU AES FSM issue_cnt underflow and consolidate simd_aes into
    simd_aes_lane. Add Zvkned test programs with FIPS 197 test vectors.
    [main.c]
2026-04-09 Extend Zvkned debug tests to cover all 11 instructions
    Add tests for the 6 missing Zvkned instruction variants:
    - .vs variants: vaesem.vs, vaesef.vs, vaesdm.vs, vaesdf.vs
    - AES-256 key schedule: vaeskf2.vi even (rnum=2) and odd (rnum=3)
    AES-256 test vectors from NIST FIPS 197 Appendix A.3, covering both
    the RotWord+SubWord+Rcon (even) and SubWord-only (odd) code paths.
    All 12 tests pass on Spike; Verilator RTL sim reveals 9 failures
    (all .vs variants, vaesdm.vv, vaeskf1.vi, vaeskf2.vi).
    Also add run_all_spike.sh and run_all_verilator.sh scripts for
    batch-running all test variants with timeout support.
    [main.c]
2026-04-09 Reroute control flow for vv/vs difference
2026-04-09 Implement vaeskf1.vi (AES-128 key schedule)
    3-phase execution reusing the existing AES FSM: VALU computes
    SubWord(RotWord(w3)) ^ Rcon per-lane, SLDU performs the cross-lane
    prefix-XOR chain (nw0..nw2), VALU finalises nw3 = w3 ^ nw2.
    Files changed:
    - simd_aes_lane.sv: add RotWord/SubWord/Rcon helpers and VAESKF1 case
    - valu.sv: include VAESKF1 in is_aes_valu/is_aes_round, pass NrLanes/lane_id/rnum to simd_aes_lane
    - sldu.sv: add prefix-XOR combinator and VAESKF1 to acceptance/issue/commit logic
    - ara_sequencer.sv: route VAESKF1 to both ALU and SLDU
    - lane.sv: add VAESKF1 to ALU_RED_SEL selector (fixes VALU↔SLDU deadlock)
2026-04-09 Implement vaeskf2.vi (AES-256 key schedule)
    Reuses the vaeskf1 3-phase FSM (VALU → SLDU → VALU) with two key
    differences: operand_a carries vd (key[i-1]) instead of scalar_op,
    and the ack pattern is swapped (vs2 acked in Phase 0, vd in Phase 1)
    so the w3 lane can compute nw3 = vd[3] ^ nw2.
    Even rounds apply RotWord + SubWord + Rcon; odd rounds apply SubWord
    only. The SLDU prefix-XOR chain is shared with vaeskf1.
    Tested with NIST FIPS 197 Appendix A.3 vectors (rnum=2 even, rnum=3 odd).
2026-04-09 Clean up AES implementation: gate by CryptoSupport, simplify code
    - Gate all AES logic behind Zvkned(CryptoSupport) so nothing is
    synthesized when CryptoSupport=None:
    - sldu.sv: wrap ShiftRows and prefix-XOR blocks in generate, gate
    is_issue_aes, acceptance, commit_cnt, and SLIDE_SETUP control arms
    - ara_sequencer.sv: move AES VFU routing to gated post-case override
    - lane.sv: move AES ALU_RED_SEL to gated post-case override
    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
2026-04-09 Fix SLDU commit_cnt for back-to-back AES instructions
    The SLDU initializes commit_cnt for a queued instruction in two places:
    at accept time and at commit time of the preceding instruction. The
    accept-time path correctly set commit_cnt = NrLanes * 8 for AES ops,
    but the commit-time path fell through to the reduction formula
    ((NrLanes * (clog2(NrLanes)+1)) << EW64), giving 96 instead of 32.
    This caused the second and subsequent AES instructions to never reach
    commit_cnt == 0, so the SLDU never signalled vinsn_done, filling its
    instruction queue and stalling the pipeline.
    Also enable Zvkned in ara_soc and add zvkned to the Spike ISA string.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
2026-04-09 Fix review issues in Zvkned AES implementation
    - Remove use_scalar_op from vaeskf1 dispatcher (matches vaeskf2,
    avoids overriding operand_a via alu_operand_a mux)
    - Add NrLanes <= 4 assertion for Zvkned (.vs broadcast needs
    cross-lane replication not yet implemented for NrLanes > 4)
    - Consolidate duplicate sub_bytes_col/inv_sub_bytes_col into
    sub_word/inv_sub_word in simd_aes_lane
    - Fix phase numbering comments in valu.sv and misleading test
    comment in zvkned_dbg/main.c
    [main.c]
2026-04-09 Add aes kernel to performance.py and vaes ISA test to CI
    Add the missing "aes" kernel entry to the performance extractor
    (perfExtr, ideal_maxPerf, real_maxPerf) so benchmark.sh no longer
    fails with "kernel aes is not valid".
    Also wire up the vaes ISA test for CI: add vaes to the Makefrag test
    list, enable the zvkned extension in the ISA test Makefile, and widen
    linker script section patterns for clang-generated subsections.
2026-04-09 Document Zvkned vector crypto AES extension support
    Add documentation for the Zvkned AES instructions across all relevant
    docs: FUNCTIONALITIES.md, CHANGELOG, README, introduction, and module
    docs for dispatcher, sequencer, VALU, SLDU, lane sequencer, and
    simd_alu. Create new simd_aes_lane.md describing the per-lane AES
    unit. The key architectural concept—the 3-phase ALU-SLDU-ALU
    pipeline—is documented in valu.md and cross-referenced throughout.
